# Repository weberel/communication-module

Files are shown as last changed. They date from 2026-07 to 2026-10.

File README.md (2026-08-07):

# ecoTrace Communication Module

> ## 🚧 HARDWARE VALIDATED, APPLICATION NOT YET - read this
> As of the **2026-08-06/07** bring-up campaign the **board is fully validated on
> real hardware**: both charge inputs (USB and solar, incl. VINDPM/MPPT control),
> cellular, WiFi, all I2C sensors, the SPI flash, deep sleep, and the QON button
> (wake / OTA mode / ship-mode power-off). GPS is the only untested block.
> The `lib/EcoTrace` drivers underneath all of that ran on hardware too.
>
> What has **NOT been exercised end-to-end** is the **`datalogger` application
> itself**: the 5-minute duty cycle, the flash ring log across power loss, MPPT
> tracking over a real day, the twice-daily ThingsBoard upload with clock sync,
> and watchdog/crash recovery. It compiles and boots; treat it as a scaffold to
> validate, not as proven.
>
> Full breakdown, including the measured numbers: [`docs/testing-status.md`](docs/testing-status.md).

Firmware and board-support for the **ecoTrace Communication Module** - a small,
battery- and solar-powered ESP32-C6 board with an LTE modem, built for **logging
data remotely** from the field.

This repo gives you a ready-to-run **datalogger** plus a library of drop-in
**functions for every peripheral** on the board, so you can fork the logger and add
whatever you need. It is the starting point for anyone (students, collaborators)
picking up the board.

> ⚠️ **Read [`docs/hardware-errata.md`](docs/hardware-errata.md) before wiring anything.**
> Rev A has a **swapped VIN +/- silkscreen** and other gotchas.

---

## The board at a glance

| | |
|---|---|
| MCU | ESP32-C6-MINI-1 (WiFi / BLE / 802.15.4, native USB Serial/JTAG) |
| Power / charging | **BQ25792** buck-boost charger + PMIC - USB, solar (MPPT), LiPo, 16-bit ADC |
| Cellular | **SIMCom A7672E-LASE** LTE Cat-1 modem (+ internal GNSS, untested) |
| Sensors (optional) | SC7A20 accelerometer, LTR-303ALS ambient light |
| Storage | GD25Q128 16 MB SPI NOR flash |
| Security | ATECC608B secure element |
| Inputs | USB-C (power + flashing), SIM slot, battery connector, VIN (solar/DC in) |
| Antennas | u.FL for LTE and GPS |

Board revision: **Rev A, 2026-04-23**. Full KiCad project, schematic PDF, board
renders, and JLCPCB fab files are in [`hardware/`](hardware/).

## What you get

**1. The datalogger** (`src/datalogger/`) - the main application. Every 5-minute
wake it:
- reads the full battery + charger state (BQ25792) and the I2C sensors
  (LTR-303 light, SC7A20 accel, MS5837 pressure + temperature on the hat header),
- runs a solar-management pass: **MPPT** (fractional-Voc + perturb-&-observe on
  VINDPM) to maximise input power, per-day **harvest accounting**, and a
  **weather-adaptive charge target** - good weather caps charging at ~80 % SoC to
  age the LiPo slower, bad weather allows 100 % for reserve,
- appends one 64-byte record to a **ring log on the 16 MB SPI flash**
  (power-loss safe, ~2.5 years of capacity),
- twice a day drains the backlog to **ThingsBoard** in timestamped batches -
  cellular first, **WiFi as backup** - and syncs the wall clock from the network,
- deep-sleeps in between with everything powered down (modem rail, flash,
  sensors, charger ADC); the BQ25792 keeps charging autonomously.

It is a **hackable starting point** - fork it and change whatever you need. To log
your own sensor: extend `LogRecord` in [`record.h`](src/datalogger/record.h) (spare
bytes are reserved), read it in `readSample()` in
[`main.cpp`](src/datalogger/main.cpp), and send it in `recordValues()` in
[`uplink.cpp`](src/datalogger/uplink.cpp). Connect external sensors on the SENSOR
(I2C) or SPI header. Tune the duty cycle / charge profile / MPPT / weather
thresholds in [`config.h`](src/datalogger/config.h).

**2. The driver library** (`lib/EcoTrace/`) - ready-to-call functions for every part
on the board. Pull in only what you need. Full list: [`docs/api-reference.md`](docs/api-reference.md).

| Driver | Covers | Status |
|---|---|---|
| `BQ25792` | charging (USB + solar), ADC, status, faults, MPPT/VINDPM | ✅ full, datasheet-accurate |
| `ModemA7672` | LTE power/AT, SIM, registration, GPRS, HTTP GET/POST, time | ✅ full (GPS = stub) |
| `LTR303` | ambient light (CH0/CH1, lux) - datalogger's example sensor | ✅ |
| `SC7A20` | accelerometer (X/Y/Z mg) | ✅ |
| `ExtFlash` | GD25Q128 read/erase/program, power-down | ✅ (full 16 MB) |
| `MS5837` | MS5837-02BA barometer (pressure, temperature, altitude) | ✅ |
| `ATECC608B` | secure element presence/wake | 🔹 thin (crypto via CryptoAuthLib) |
| `EcoTraceBoard` | safe init, I2C/SPI bring-up, deep sleep | ✅ |

**3. The board self-test** (`src/functionality_test/`) - probes every device and
prints a `PASS / FAIL / SKIP` report. Run it first on a new board.

## Toolchain

**VS Code + PlatformIO + Arduino-ESP32.** Reproducible builds, a real editor, the
Arduino library ecosystem, and full ESP-IDF APIs underneath when needed. See
[`docs/getting-started.md`](docs/getting-started.md).

The ESP32-C6 needs arduino-esp32 v3+, which the official PlatformIO platform does not
ship yet - this project pins the [pioarduino](https://github.com/pioarduino/platform-espressif32)
fork (version `53.03.13`) in `platformio.ini`. Don't unpin it.

## Quick start

```bash
# 1. open this folder in VS Code with the PlatformIO extension installed
# 2. plug the board in over USB-C (keep a battery connected -- see errata)
# 3. check the board is healthy:
pio run -e functionality_test -t upload && pio device monitor

# 4. set your SIM APN + upload URL, then run the logger:
cp lib/EcoTrace/secrets.example.h lib/EcoTrace/secrets.h   # then edit it
pio run -e datalogger -t upload && pio device monitor

# 5. reflash over WiFi later (bench convenience): press the QON button 3x
#    (board joins WiFi, blinks once per second, prints its IP on serial), then:
pio run -e datalogger        # build the new image
curl -F "image=@.pio/build/datalogger/firmware.bin" http://<board-ip>/update
#    (espota / `pio run -e datalogger_ota -t upload` also exists but its UDP
#     handshake proved unreliable on real networks -- prefer the curl path)
```

Without a `POST_URL` in `secrets.h` the datalogger runs in bench mode: it samples and
prints over serial but does not transmit.

## Layout

```
lib/EcoTrace/      board support: pin map + drivers (the reusable core)
  ecotrace_pins.h    single source of truth for the pin map
  EcoTraceBoard.*    safe init, I2C/SPI bring-up, deep-sleep helper
  BQ25792.*          charger / PMIC (hand-written, datasheet-accurate)
  ModemA7672.*       LTE modem (hand-written AT stack)
  LTR303.* SC7A20.* ATECC608B.* ExtFlash.*   peripheral drivers
  secrets.example.h  copy to secrets.h and fill in (gitignored)
src/
  datalogger/        the main application
    config.h           duty cycle, charge profile, MPPT, weather, upload tunables
    record.h           the 64-byte on-flash log record (+ CRC)
    flash_log.*        power-loss-safe ring log on the 16 MB SPI flash
    solar.*            MPPT + harvest tracking + weather-adaptive charge target
    uplink.*           ThingsBoard upload: cellular first, WiFi backup, clock sync
    main.cpp           the wake/sample/sleep cycle
  functionality_test/  board bring-up self-test
docs/              getting started, pinout, errata, api reference, testing status
hardware/          KiCad project + exports
```

## Related

- `functionality_test_arduino` - the original bring-up test this repo grew from.
- `bms_stove` - an ESP-IDF application on this hardware (remote battery/stove
  datalogger), a reference for a full deployment.

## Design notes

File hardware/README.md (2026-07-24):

# Hardware

The KiCad design and manufacturing outputs for the ecoTrace Communication Module
(Rev A, 2026-04-23) are included here so you don't need Drive access.

```
hardware/
  kicad/         KiCad project - open Communication_pcb_main.kicad_pro in KiCad
    Communication_pcb_main.kicad_pro / .kicad_pcb / .kicad_sch
    mcu.kicad_sch  power_mgmt.kicad_sch  simcom.kicad_sch   (schematic sheets)
    jlcpcb/        fab outputs: gerbers, drill, BOM, CPL, GERBER-*.zip
  exports/       viewable without KiCad:
    Communication_pcb_main-schematic.pdf
    board-top.png  board-bottom.png   (3D renders)
```

## No KiCad? Start here

- **Schematic:** `exports/Communication_pcb_main-schematic.pdf`. Sheets: `mcu`,
  `power_mgmt`, `simcom`. The **power_mgmt** sheet (BQ25792) is the one to know: it
  defines the charging path, VSYS, the NTC (TS) network (note the errata), and the
  ACDRV FET gating for USB vs solar inputs.
- **Board:** `exports/board-top.png` / `board-bottom.png`.

## Fabrication

`kicad/jlcpcb/` holds a ready-to-order set (gerbers, drill, BOM, CPL, and a zipped
gerber bundle) targeted at JLCPCB. Re-export from KiCad if you change the board.

This is the **current 4-layer** version of the board (F.Cu / In1 / In2 / B.Cu). An
older 2-layer design also exists on the shared drive; it is not included here.

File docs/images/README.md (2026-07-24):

# Board images

- `board_top.png` - top side (3D render from KiCad)
- `board_bottom.png` - bottom side (shows the BOOT / UART0 / test pads)

Higher-level renders and the schematic PDF are in [`../../hardware/exports/`](../../hardware/exports/).

TODO: add `board_annotated.png` - the top view with connector/pin callouts (the
hand-annotated render used during bring-up) if you want it embedded in the pinout doc.

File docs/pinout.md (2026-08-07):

# Pinout - ecoTrace Communication Module (ESP32-C6-MINI-1)

Verified against schematic 2026-05-05. The authoritative machine-readable copy is
[`lib/EcoTrace/ecotrace_pins.h`](../lib/EcoTrace/ecotrace_pins.h) - this page is the
human-friendly version.

Exposed GPIOs on the MINI-1 module: `0,1,2,3,4,5,6,7,8,9,12,13,14,15,18,19,20,21,22,23`
(GPIO10,11,16,17 are not bonded on the MINI-1; GPIO24-30 are internal flash).

## By function

| GPIO | Net | Notes |
|-----:|-----|---|
| 0 | MODEM_STATUS | A7672 STATUS out, but **only valid while the modem rail is on**: the translator (Q408) is gated by the modem's own 1V8, so with the rail off the line floats HIGH via R423 - indistinguishable from "modem running". Detect boot as the LOW→HIGH edge (or an AT response), never as a HIGH level. **Also a boot strap** - read briefly only |
| 1 | LED | status LED, active HIGH |
| 2 | QON | shared button net: BQ25792 QON + ESP deep-sleep wake (EXT1). BQ hardware behavior: LOW ~1 s exits ship mode, LOW ~10 s = full power cycle (tRST); shorter holds are ignored by the BQ, so firmware defines the long-press action (datalogger: 3 s hold = enter ship mode via I²C). Pad TP404 |
| 3 | INT_shared | shared interrupt: SC7A20 accel + LTR-303 light |
| 4 | SPI_MOSI (SI) | to GD25Q128 flash |
| 5 | SPI_MISO (SO) | from GD25Q128 flash |
| 6 | I2C_SDA | LP_I2C, external 4k7 pull-up to 3V3 |
| 7 | I2C_SCL | LP_I2C, external 4k7 pull-up to 3V3 |
| 8 | SPI_CS_FLASH | GD25Q128 CS. Strapping pin, idles HIGH via 10k |
| 9 | SPI_CS_PERIPH | spare CS, **not populated**. Strapping + **BOOT pad** (TP403) |
| 12 | USB D− | native USB Serial/JTAG |
| 13 | USB D+ | native USB Serial/JTAG |
| 14 | SENSOR_PWR | populated high-side switch (active HIGH) for EXTERNAL sensor power on the SENSOR header. On-board sensors run on the always-on 3V3 (RT9080 LDO), not this switch |
| 15 | (tied to GND) | strapping pin |
| 18 | SPI_CLK | to GD25Q128 flash |
| 19 | INT_bq | BQ25792 fault / charge interrupt |
| 20 | MODEM_TX | ESP TX → modem RX |
| 21 | MODEM_RX | ESP RX ← modem TX |
| 22 | MODEM_PWRKEY | drives a **low-side inverter** (Q409): GPIO HIGH = PWRKEY asserted (pulled LOW at the modem), GPIO LOW = released. The firmware's idle-HIGH convention holds PWRKEY asserted, so the modem auto-boots as the rail rises - field-proven, but be aware of the inversion when porting |
| 23 | MODEM_PWR_EN | modem rail MOSFET; HIGH = modem powered |

## I2C device addresses (7-bit)

| Addr | Device |
|---|---|
| 0x18 / 0x19 | SC7A20 accelerometer |
| 0x29 | LTR-303ALS ambient light |
| 0x35 / 0x60 | ATECC608B secure element (needs a wake pulse to answer) |
| 0x6B | BQ25792 charger / PMIC |

## Header labels (silkscreen)

Top-edge and side headers, per the board silkscreen:

- **SENSOR / I2C** (J401, the "hat" header): `GND · 3V3 · SCL · SDA` - the 3V3 pin is
  the **always-on** LDO rail, *not* the GPIO14-switched one, so devices here stay
  powered in deep sleep (put them in their own low-power mode instead). The separate
  J404 connector is the one switched by GPIO14.
- **SPI**: `GND · 3V3 · SCLK · SI · SO · CS`
- **BTN**: `GND · QON`
- **USB**: `GND · VUSB · DN · DP`
- **Programming pads** (back): `GND · 3V3 · RESET · BOOT · RX · TX`
- **Power**: `VIN (+/−, SWAPPED - see errata)`, `VBAT · TS · GND`, `VSYS`

## Debug / fixture pads (back side)

| Pad | Signal |
|-----|---|
| TP401 | TXD0 - UART0 flash TX |
| TP402 | RXD0 - UART0 flash RX |
| TP403 | GPIO9 - CS_periph / **BOOT** fallback |
| TP404 | GPIO2 - QON / wake |
| EN | reset (10k to 3V3, 1µF to GND, button to GND) |

## Board landmarks

Renders: [`images/board_top.png`](images/board_top.png),
[`images/board_bottom.png`](images/board_bottom.png). Schematic PDF:
[`../hardware/exports/`](../hardware/exports/).

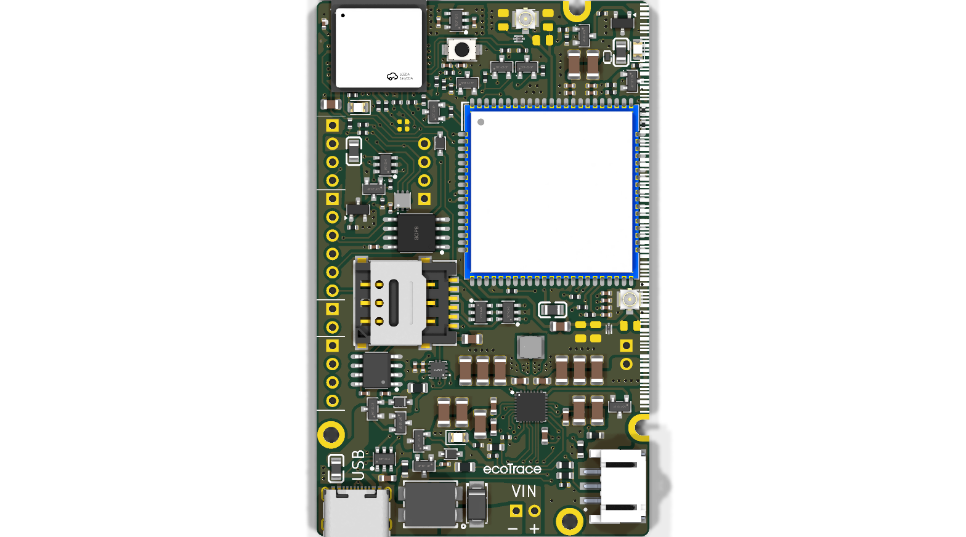
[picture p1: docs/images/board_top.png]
top render


Landmarks (using the photo orientation, USB at top-left): USB-C (power + ESP
flashing), USB pins, on/off button, SIM card slot, SPI pins, I2C/VSYS pins along the
top; ESP32-C6-MINI-1 module centre; A7672E LTE modem top-right; ESP reset button and
LTE (mobile) u.FL antenna on the right; GPS u.FL antenna, VSYS-out pads, battery
connector (bottom-left), and solar/general power in (VIN) on the left edge.

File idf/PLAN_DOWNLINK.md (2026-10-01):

# Plan: downlink (remote config and OTA) for the comm board

Written 2026-09-30, before the code. **The contract both sides build against is
`ecotrace-server/docs/DOWNLINK.md`** (agreed the same day, with the three corrections below
taken in). This file is the firmware half: stages, files, done-criteria. Where the two differ,
DOWNLINK.md wins.

## Contract

**Topic.** `ecotrace/<username>/config`, retained, QoS 1, published by the server only. The
device gets `pattern read ecotrace/%u/config` in the broker ACL and nothing else new. It is not
the telemetry topic: a retained message there would be ingested as a reading, and the device
must never be able to write its own config.

**Payload.** One JSON object. Unknown keys are ignored, so the contract can grow.

```json
{"cfg_ver": 7,
 "sample_interval_s": 300, "upload_period_s": 43200,
 "fw_ver": "com-0.36", "fw_url": "https://ingest.ecotrace.ch/fw/com-0.36.bin",
 "fw_sha256": "<64 hex>"}
```

- `cfg_ver` is an identity, not an order: the device applies a payload whose version differs
  from the one in NVS. A server that resets the counter still gets applied.
- Interval bounds on the device: sample 60..3600 s, upload 600..86400 s, upload >= sample.
  A payload that fails them is not applied at all and is reported with `cfg_err: "range"`.
- The `fw_*` keys are optional. Present means "run this version"; absent means keep what runs.
- An empty retained payload (the server's "clear") means no config: the device keeps its NVS
  values and reports them. Not an error.

**Ack, in the status message.** `cfg_ver` (in effect, 0 if never configured), `sample_s`,
`upload_s` (in force for the sleep that follows), `cfg_err` (only while the last received
payload was rejected: `parse`, `range`), and after a failed OTA `fw_err` (`download`, `sha256`,
`write`, `rollback`) with `fw_err_ver`. `fw` is already sent on every status message and is the
OTA ack.

The ack is truthful within one session: the payload arrives at subscribe time, before the
drain; the sleep length and the upload countdown are computed after the drain, so the status
message of the same session reports what will actually happen next.

## Stage 1: config (one build, com-0.35) -- DONE, verified on unit A (dev-4) 2026-09-30

Files: `main.c`, `uplink.c`, new `devcfg.c/h`, `config.h`, `CMakeLists.txt` (adds `json`).

- [x] `devcfg.c`: NVS namespace `cfg`, keys `ver`, `samp_s`, `upl_s` (u32). `devcfg_init()`
      at every boot in `app_main`, right after the rollback mark and before `board_init()`; it
      owns `nvs_flash_init()` now (it used to run only on the WiFi path). Values cached in
      `RTC_DATA_ATTR` with a magic: a warm wake never opens NVS, a cold boot reloads.
- [x] `SAMPLE_INTERVAL_S` / `UPLOAD_PERIOD_S` are compiled defaults only (`config.h`); the five
      use sites read `devcfg_sample_s()` / `devcfg_upload_s()`.
- [x] `uplink.c`: `config_fetch()` after `mqtt_up()` in both the cellular and the WiFi session,
      before `drain()`. Subscribes QoS 1 to `ecotrace/<user>/config`, waits up to 2 s for
      `EV_CFG_DONE`, unsubscribes. A refused SUBSCRIBE (`MQTT_ERROR_TYPE_SUBSCRIBE_FAILED`,
      the ACL not deployed yet) and a timeout are both "no config". The payload is applied
      from the MQTT event task (`devcfg_apply`, cJSON, bounded parse).
- [x] Apply rule as in DOWNLINK.md: `cfg_ver` differs from NVS, absent interval = keep, bounds
      sample 60..3600, upload 600..86400, upload >= sample checked on the resulting pair; any
      violation rejects the whole payload. NVS written and committed before the cache moves.
- [x] Status keys: `cfg_ver`, `sample_s`, `upload_s` on every status message, `cfg_err`
      (`parse` | `range`) only while the last received payload was rejected.
- [x] No countdown clamp needed: the countdown is (re)armed from `devcfg_upload_s()` after
      the session, so a new period is in force from the same session.

Verified 2026-09-30 from the server UI, board untouched: a config published from the server shows up in the next
status message with the same `cfg_ver`; the following wakes are spaced by the new interval
(USB console timestamps); a rejected payload shows `cfg_err` and unchanged intervals; a board
that never received a config reports `cfg_ver` 0 and the compiled 300 / 43200; a session
before the ACL is deployed logs "config subscribe refused" and drains normally.

## Stage 2: OTA (com-0.36) -- DONE. Forward and reverse OTA proven 2026-09-30; rollback proven 2026-10-01 with com-0.40

Files: `ota.c/h` (new), `devcfg.c/h`, `uplink.c/h`, `main.c`, `config.h`, `src/CMakeLists.txt`,
`version.txt` (new).

- [x] **One version source.** `idf/version.txt` holds `com-0.36`; ESP-IDF puts it in the image's
      app descriptor (the server reads it there at release upload) and `src/CMakeLists.txt`
      passes the same string as `FW_VERSION`. `config.h` errors if it is missing. Bump
      `version.txt` **and touch `idf/CMakeLists.txt`** (PlatformIO re-runs CMake only when a
      CMakeLists changes; a bump alone rebuilt com-0.36 on 2026-09-30). Checked on the built
      image: descriptor and status string agree. Release copies go to `.pio/build/release/`.
- [x] `devcfg.c` takes `fw_ver` / `fw_url` / `fw_sha256` from every accepted payload (also on
      `same`), all three or none; keeps them for the session. Attempt counter per version and
      the last error (`fw_err`, `fw_err_ver`) in NVS, so they outlive a rollback.
- [x] `ota.c`: `esp_https_ota` begin/perform/finish over the link already up, pinned ISRG root,
      into `esp_ota_get_next_update_partition()`. SHA-256 of the written bytes (mbedtls, 4 KB
      static buffer, WDT reset per chunk) against `fw_sha256` BEFORE `esp_https_ota_finish()`
      switches the boot partition. Errors map to the contract: `download`, `sha256`, `write`.
- [x] `uplink.c` `ota_attempt()`: after the drain, before the status message, in both the
      cellular and the WiFi session. Skipped when the target equals the running version, when
      VBAT < modem floor + 100 mV, or after 3 attempts for that version. The attempt is counted
      before the download starts, so a crash mid-download counts.
- [x] `main.c`: the mark-valid call moved from the top of `app_main` to after the upload
      session, only when it published. `ota_boot_check()` after the boot classification: an
      ABORTED other slot records `fw_err: rollback` with that slot's descriptor version and
      forces an upload now. On `ota_ready`: RTC magic cleared, devcfg cache dropped, restart.
- [x] Status keys `fw_err`, `fw_err_ver` when set; `fw` unchanged (it is the ack).
- [x] Builds clean: RAM 19.5 %, flash 64.8 %.
- [x] **Found on the first attempt, fixed the same day:** the download wedged after
      `uart_terminal: HW FIFO Overflow`. The UART ISR was in flash, so it is masked during every
      OTA flash write and modem bytes are lost, which killed the PPP stream; and
      `esp_https_ota_perform()` returns IN_PROGRESS on a read timeout, so the loop spun for 10+
      minutes feeding the watchdog with the modem on. Fixes: `CONFIG_UART_ISR_IN_IRAM=y`
      (sdkconfig.defaults and the generated sdkconfig), a 60 s no-progress stall and a 9 min
      deadline in `ota_run()` (`fw_err: download`), and the attempt counter restarts when the
      running version changes (a serial reflash gets fresh tries).
- [x] Forward OTA verified 2026-09-30 17:06: dev-4 on the fixed com-0.36 downloaded com-0.37
      over cellular, restarted, reported `fw: com-0.37`, cfg_ver 4 applied, server "up to date".
      (That com-0.37 was the build WITHOUT the UART fix; it must not be asked to OTA again.)

- [x] With the fixed code on both ends, 2026-09-30 17:19 and 17:26: com-0.36 -> com-0.37 -> com-0.36
      over cellular, each under 4 min from button press to "up to date" on the server. The status
      message of the downloading session goes out with the old `fw` and no `fw_err`, then the
      new image's cold-boot session acknowledges.

- [x] com-0.38 (2026-10-01): a version with `fw_err: rollback` on record is never retried (the
      retry ran before the status message and would have cleared the error the server needs to
      see; the same bytes would fail the same way). Also fixes the RSSI 0 dBm regression (CSQ
      re-read after registration). com-0.39 = same code with a wrong broker host, built only for
      the rollback test. Procedure: server `CHANGES_FIRMWARE_com-0.38.md`.

- [x] **com-0.40 (2026-10-01): rollback actually works now.** The com-0.39 rollback test failed:
      the broken image survived every wake and the button. Cause: the mark-valid call sat after
      the upload session in `main.c`, and the OTA runs inside that session;
      `esp_ota_mark_app_valid_cancel_rollback()` marks the ACTIVE otadata entry, which
      `esp_https_ota_finish()` had just pointed at the new slot. So every OTA so far validated the
      new image before it booted. Fix: `confirm_running_image()` in `uplink.c`, right after the
      drain published and before `ota_attempt()`, guarded by "running slot is PENDING_VERIFY";
      the `main.c` call is gone. com-0.41 = com-0.40 with the wrong broker host, for the retest.

- [x] **Rollback verified 2026-10-01 09:50** (device_status row, UTC 07:50:02): com-0.40 downloaded
      com-0.39 (09:44 status, `fw: com-0.40`, no error), restarted into it, com-0.39 failed its
      cold-boot session and slept; at its first timer wake the bootloader booted com-0.40, which
      reported `fw_err: rollback`, `fw_err_ver: com-0.39`, `wake_reason: timer`, `rssi_dbm: -71`
      (RSSI fix confirmed too). 5.5 min from restart to report. Server-side gap: `ecotrace-admin
      config` still prints `[pending]` for the target instead of failed; the data is there.

Still open on hardware:  a wrong SHA-256 is
refused with `fw_err: sha256` and the running image is untouched.

## Server side: three corrections to the 2026-09-30 plan (all taken into DOWNLINK.md)

1. Separate topic and a read ACL entry, see Contract. "The existing topic" does not work.
2. Put the `fw_*` keys and the error keys into the contract now, so the handoff is written
   once. The server leaves them unset until it hosts images.
3. Host firmware images over HTTPS behind the existing certificate chain (Caddy, same host as
   ingest), with the SHA-256 computed at upload time and stored with the version.

Per device only, no group inheritance. Agreed. Deltas the server side added: `fw_err` values
are `download | sha256 | write | rollback` with `fw_err_ver`; the OTA attempt counter stops at 3;
`cmd` stays reserved for one-shot commands.

## Traps
- `nvs_flash_init()` currently runs only when WiFi is used (`uplink.c` 1078). It must run at boot.
- ESP-IDF rollback is checked in the bootloader on every reset, including deep-sleep wake.
- MQTT 5 stays: a refused subscribe is visible as a reason code, a 3.1.1 broker would hide it.
- `boot_id` rolls on the post-OTA cold boot by design; the server's gap check treats the two
  boots separately.

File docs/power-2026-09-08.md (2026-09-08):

# Comm module sleep current: 1467 uA -> 356 uA (2026-09-08)

All currents measured with a Joulescope JS220 in the **battery lead**, USB
unplugged, board on battery. "Comm board alone" means nothing on J404.

USB-plugged is easy to mistake for a valid reading: with the cable in, the board
runs from VBUS and the battery lead shows a flat **62.9 uA**. That number, not
the presence of a COM port, is the test for whether the cable is out -- the C6's
USB-Serial/JTAG only enumerates while awake, so a sleeping board shows no port
either way.

## 1. Result

| configuration | sleep current |
|---|---|
| shipping firmware, start of day | **1467.5 uA** (also 1468, 1501 on two earlier runs) |
| after the pull-up fix, sensor rail up | **356.5 uA** |
| same, sensor rail down | **139.8 uA** |
| no GPIO holds at all | **128.3 - 128.5 uA** |

The 128.3 uA floor matches the 129.1 uA in the 2026-09-06 report's June bench
staircase to within 0.8 uA. The hardware was never the problem.

Full system (comm + ultrasonic + pressure sensor, rail up, USS metering at 1 Hz):
**floor 546.1 uA, median 649.1 uA**; the ripple is the 1 Hz captures.

## 2. What was actually wrong

### 2.1 Internal pull-ups latched into their own output drivers (1122 uA)

`gpio_reset_pin()` enables the pad's internal pull-up -- its own comment says
"for powersave reasons, the GPIO should not be floating, select pullup" -- and
`gpio_set_direction()` only touches input-enable / output-enable / open-drain.
It never clears the pull-up. So board.c's `out()` leaves every pin driving a
level WITH the pull-up still on.

A pad driven LOW then fights its own driver through the ~42k internal pull-up.
That pull-up is in the always-on domain, so an UNHELD pad powers down in deep
sleep and the conflict disappears; `gpio_hold_en()` latches it in.

MEASURED, holding pads driven LOW:

| pads held | delta |
|---|---|
| LED only | +78.4 uA |
| MODEM_PWR_EN + PWRKEY | +156.1 uA (78.1 uA each) |

A pad held HIGH costs nothing: GPIO1 high vs low measured **+12.4 uA**, which is
that pin's own load -- (3.3 - 1.9) V / R454 100k = 14 uA through D420.

FIX: `gpio_pullup_dis()` on the three pads held low, before `gpio_hold_en()`.
Three lines. Shipping firmware went **1467.5 -> 356.5 uA** with no behavioural
change: all four holds still applied, sensor rail still up, ultrasonic board
still powered between wakes.

### 2.2 The energised sensor rail (216.6 uA) -- already fixed in the schematic

Energising the switched rail costs **216.6 uA**, measured twice, under two
different pull-up configurations, with J404 empty.

It is NOT a load on the rail. It is the gate-drive divider, and the board on the
bench does not match the current schematic:

| | R419 | R420 | R421 |
|---|---|---|---|
| as built (BOM sent to JLC 2026-04-23) | 10k | 10k | 100k |
| schematic since 2026-08-18 | 1k | 1M | 1M |

With the as-built values:

    GPIO14 high -> R419 10k -> gate -> R420 10k -> GND   3.3 V / 20k   = 165 uA
    Q405 on     -> R421 100k, VSYS to drain              4.16 V / 100k =  42 uA
                                                                         -------
                                                             predicted   207 uA
                                                             measured    216.6 uA

The corrected values give 7.5 uA for the same paths, so the next build removes
~209 uA with no new work. D606 was suspected and is exonerated.

Supporting readings: with the rail ON, J404 pin 2 = 4.16 V (so nothing loads it)
and SDA/SCL = 3.3 V (so no clamp path); rail-to-GND cold = 2.9 MOhm.

### 2.3 Park mode leaked 321 uA

The two park-mode sleep paths called `bq_adc_disable()` but never
`bq_ibat_sense(false)`, leaving EN_IBAT on for exactly the long low-battery
sleeps. Fixed.

BQ25792 costs, one control bit removed per ladder rung:

| left enabled across sleep | cost |
|---|---|
| ADC in continuous conversion | **574.1 uA** |
| EN_IBAT | **321.4 uA** |
| ACDRV1, ACDRV2 | 0.0 uA each |

574.1 + 321.4 = 895.5 uA, matching an independent single-rung measurement of
895.5 uA exactly. Note the normal wake path already disabled both before sleep,
so this was never the field problem -- only park mode leaked.

## 3. Suspected and cleared

* Motion wake / `sc7a20_arm_motion()` -- disabled it, board still slept at
  1467.5 uA vs 1467.1 uA. Costs nothing. Left enabled.
* The modem and WiFi uplink -- a rung covering the entire wake path including a
  full uplink measured the same as one that skipped it.
* R405/R408 2.2k UART pull-ups -- parking IO20/IO21 before sleep changed nothing.
  The Q402/Q403 level shifters have their gates on the modem's own VDD_1V8, so
  they isolate correctly when it is unpowered.
* `esp_pm_configure()` with light sleep enabled -- +0.1 uA.
* D606 / errata 11 -- with the ultrasonic board attached and the rail down, the
  back-feed measures **+60.4 uA**, not 1.4 mA. The 1.4 mA figure belongs to
  `board_sensor_power_cycle()`, which deliberately drives SDA/SCL LOW through the
  4k7 pull-ups (2 x 3.3 V / 4k7 = 1.404 mA) for the off window only. Confirmed
  with a voltmeter: rail off, J404 pin 2 sits at 2.8 V, fed through D606's clamps
  from the 3.3 V bus. A connected ultrasonic board is therefore parasitically
  held near 2.8 V during sleep rather than being cleanly off.

## 4. Two ESP32-C6 facts worth keeping

* `gpio_deep_sleep_hold_en()` does not exist on the C6. driver/gpio.h guards it
  with `#if SOC_GPIO_SUPPORT_HOLD_IO_IN_DSLP && !SOC_GPIO_SUPPORT_HOLD_SINGLE_IO_IN_DSLP`
  and the C6 defines BOTH -- it holds pads individually, so plain
  `gpio_hold_en()` is sufficient, including on non-RTC pads like GPIO14/22/23.
  Being an RTC/LP pin (GPIO0..7) governs EXT1 wake and LP-core access, not hold.
  RTC pads are not cheaper to hold.
* `esp_sleep_pd_config(ESP_PD_DOMAIN_RTC_PERIPH, ESP_PD_OPTION_OFF)` RAISES
  deep-sleep current to 885.7 uA -- the documented light-sleep level -- and wipes
  RTC_DATA_ATTR. Do not use it.

## 5. Energy budget

Measured, comm + ultrasonic + pressure sensor, USS metering at 1 Hz:

    sleep    655 uA x 24 h                  = 15.7 mAh/day
    wakes    67.1 mC above floor x 288/day  =  5.4 mAh/day
    uplink   2.28 mAh x 1/day               =  2.3 mAh/day
                                              -------------
                                              ~23 mAh/day

against the 114 mAh/day field baseline in the 2026-09-06 report. On a 5000 mAh
cell that is ~217 days nominal; derating for usable capacity, self-discharge and
a real registered cellular session gives roughly 5 months, against ~6 weeks
before. The next board build should reach ~18 mAh/day.

## 6. NOT established

* The uplink figure is one attach ATTEMPT, not a registered session. There is no
  cellular signal at the bench, so the modem drew 351 mA for ~40 s (8.21 C =
  2.28 mAh) and failed to register. A real session may cost more; the 2026-09-06
  report modelled ~5.5 mAh/day.
* The per-wake charge comes from a SINGLE wake in one 420 s window.
* The rung-0 baseline drifted 128.5 -> 174.4 -> 139.6 uA across runs of identical
  code. Deltas within a run are consistent to ~1 uA; absolute floors across runs
  carry roughly 11-35 uA of unexplained spread.
* That the 216.6 uA is the gate divider is supported by arithmetic (207 uA
  predicted vs 216.6 uA measured) and by the BOM/schematic mismatch, but has NOT
  been confirmed by measuring the fitted resistors.

## 7. Method notes

* Peripheral state survives an ESP32 reset. The BQ25792 keeps its registers (and
  `bq_disable_watchdog()` removes the one timer that would restore defaults), and
  so does the SC7A20. A minimal "boot and sleep" image therefore proves nothing
  about persistent peripheral state -- only a ladder that TAKES STATE AWAY does.
* Encode the rung in the sleep duration (20 s + 5 s per rung). Two earlier
  ladders were mapped by plateau ORDER, and the same trace admitted two
  self-consistent mappings that gave opposite conclusions.
* Give every rung a >= 1.5 s awake window, or the USB port never enumerates and
  the board cannot be reflashed without a full power cycle.
* Always include a rung that MUST reproduce a known reference. The ladder that
  finally worked had one rung land on 128.5 uA (the known floor) and another on
  1467.1 uA (the known shipping figure). Earlier ladders had no such check and
  produced confident wrong answers.
* Audit the netlist that matches the BOARD, not the latest schematic. An hour was
  spent blaming D606 because the netlist export came from a schematic revised
  four months after the board was manufactured.

## 8. Soak configuration (flashed 2026-09-08)

| setting | value |
|---|---|
| SAMPLE_INTERVAL_S | 300 s |
| UPLOAD_PERIOD_S | 24 h (one uplink/day) |
| USS_AUTO_PERIOD_S | 1 s (ultrasonic meters at 1 Hz) |
| MOTION_WAKE_ENABLE | 1 |

Firmware contains the pull-up-before-hold fix and the park-mode EN_IBAT fix; all
ladder instrumentation removed (main.c 1271 -> 791 lines).

Predicted ~23 mAh/day. The soak is sited where there IS cellular signal, so the
daily uplink should be a real registered session rather than the failed attach
measured at the bench -- which makes the soak the measurement that finally closes
the one term in section 6 that is still an estimate.

What to check when it comes back:

* battery discharge slope vs the predicted 23 mAh/day
* actual mAh per registered cellular session
* whether the sleep floor drifts with battery voltage (it should not, now that
  the 216.6 uA is understood as a fixed resistive divider rather than a leakage)
* USS capture quality over a week (badcode / badsnr in the telemetry)

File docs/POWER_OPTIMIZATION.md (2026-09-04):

# Power optimisation — work plan (bench session, week of 2026-09-08)

Everything below came out of the 2026-09-02 telemetry export
(`tools/tb_export_PCB-test-rig_20260902_1831.csv`, 137,939 datapoints,
2026-08-11 → 09-02). Nothing here needs a hardware change: every item is
firmware, on one side or the other.

Companion write-up on the module side: `Ultrasonic/Firmware/docs/DEVLOG.md` §13.

---

## 0. Before you start: the board's state

The unit has been indoors on battery since 08-17 with **no charging at all**
(deliberate max-lifespan test). At 09-02 it was at 3789 mV falling ~22.5 mV/day:

| threshold | what happens | ETA from 09-02 |
|---|---|---|
| 3600 mV | cellular stops, WiFi only | ~09-10 |
| 3450 mV | **all telemetry stops** — records bank in flash only | ~09-15 |
| 3350 mV | sampling drops to 30 min | ~09-19 |
| 3300 mV | park mode, 60-min wakes | ~09-20 |

So by the bench session it may already be silent on the dashboard. That is not
a fault. **Plug USB in first** — charging resumes, and the flash backlog drains
on the next session (ring holds 131k records, cursor is journalled, nothing is
lost). Grab that data before reflashing anything: a record-layout bump would
discard it.

---

## 1. What the run measured

Whole node: **114 mAh/day (~4.8 mA)** on the 5000 mAh cell — ~45 days
full-to-empty. Split (from ratios of voltage slopes, so independent of the
capacity calibration):

| load | share | cause |
|---|---|---|
| ultrasonic board | ~45% (~2.1 mA) | OPA836 idle ~1 mA **+** MSP430 never sleeping ~1 mA |
| ESP32 wakes | ~28% | 288 wakes/day |
| cellular | ~25% | measured: +3.08 mV per session, 2 sessions/day |
| ESP32 deep sleep | ~2% | — |

Reliability over the same window was excellent and is not a concern: 5812
records, ~286/day against 288 nominal, **zero crashes**, `uss_code` 122 on
100% of 5090 measurements, `snr_db` pinned at 34.0 dB for 18 days.

---

## 2. Work items

### A. Ultrasonic module firmware (G: drive repo)

- [ ] **A1. Sleep the main loop (biggest single item, ~1 mA).**
      `EcoTrace_Run()`'s `for(;;)` busy-polls forever — the MSP430 never leaves
      active mode (~120 µA/MHz from FRAM ≈ 1 mA at 8 MHz). Add
      `__bis_SR_register(LPM3_bits | GIE)` at the bottom of the loop for the
      `ECOTRACE_I2C_SLAVE` build.
      * the I²C ISR **already** exits LPM3 (`__bic_SR_register_on_exit`), and
        `uss_link.h` already documents this as the design — it was simply never
        implemented;
      * needs a timer wake for the autonomous tick (ACLK Timer_A or RTC);
      * `now_ms()` timebase must run off ACLK, not SMCLK, to survive LPM3;
      * watchdog interval must exceed the sleep period (or source it from
        ACLK) — `FEED_WDT()` stops happening while asleep;
      * keep the bench build busy-polling so UART stays responsive; the
        `ECOTRACE_I2C_SLAVE` split already exists for exactly this.

- [ ] **A2. PD-gate the OPA836 per capture (~1 mA).**
      In the autonomous tick: `board_rx_en(true)` → measure →
      `board_rx_en(false)`. **Leave the rails up** — the bias network and
      coupling caps stay charged, so there is no `RAIL_SETTLE_MS` and no
      discard capture, unlike full rail gating. Today `RX_EN` is only ever
      cleared as a side effect inside `board_pwr_rx(false)`, which the
      autonomous path reaches only at `AUTO_STOP`.
      *Acceptance:* `uss_amp_ups`/`uss_amp_dns`/`uss_snr_db` unchanged against
      the 34.0 dB / 18-day baseline. If they move, the amp needs more settle.

- [ ] **A3. (optional) Gate the boost + VCC_TX muxes between captures.**
      Tens of µA — the smallest prize, but the TPS61240 currently runs
      continuously to feed an idle level shifter. `board_boost()` already
      toggles it mid-capture for the "BOOST 2" noise mode, so it is proven.

- [ ] **A4. Fix the totalizer wrap.** At zero flow `uss_vol_ml` climbs ~17 L
      per 5 min and tops out at 4,294,437 mL. 2³²/1000 = 4,294,967: the
      accumulator is a **uint32 of µL reported as mL**, wrapping every ~21 h.
      Integrate signed, and either widen it or expose a wrap counter — the
      master reads only the absolute value every 5 min, so a wrap is
      indistinguishable from reverse flow.
      (The ~3.4 L/min phantom flow driving the wrap is the uncalibrated cell —
      known and accepted — but the wrap survives calibration.)

- [ ] **A5. Find out why `uss_tof_comp2_us` stopped on 2026-08-24.** 97 points
      that day, then nothing for 9 days while every other USS key kept flowing.
      Deliberate change or a code path that quietly stopped emitting?

- [ ] **A6. (optional) Latch min/max/mean flow since last read.** Makes a
      longer ESP sample interval lossless for diagnostics — 15-min records that
      still describe a 1 Hz process. Spare register space at 0x1C–0x1E.

- [ ] **A7. (optional, later) Adaptive rate** — slow when idle, fast on flow.
      Worth it for burst capture, *not* for power (see §3). Needs the zero-flow
      offset fixed first or the threshold sits permanently triggered.

### B. Communication module firmware (this repo)

- [ ] **B1. Restore `vac2_mv` and `ts_stat` (and ideally `tdie_c`) telemetry.**
      The 08-15 trim to 22 keys dropped `vac2_mv`, `vindpm_mv`, `vreg_mv`,
      `weather_good`, `eco_chg`, `tdie_c`, `ts_pct`, `ts_stat`, `press_mbar`.
      Consequence found this session: with no `vac2_mv` there is no way to tell
      "no panel voltage" from "panel fine, charger refusing". Indoors
      `light_ch0` settled it; outdoors that argument does not exist. Required
      before the panel swap.

- [ ] **B2. Log VBAT *during* modem transmit into the status record.** Every
      VBAT sample today is taken with the modem off, so the sag under the
      A7672's ~2 A burst has never been measured — and that sag, not energy, is
      what sets the minimum battery size. A single mid-session read in
      `cell_session()` turns battery sizing from a datasheet estimate into a
      measurement.

- [ ] **B3. Retune MPPT for the small panel** (do together with C1):
      `MPPT_VINDPM_START_MV` 14000 → ~5000, `MPPT_VINDPM_MIN_MV` 5000 → ~3800.
      The 5000 floor is our choice, not the chip's — the BQ25792 is
      **buck-boost**, VBUS range 3.6–24 V, so a 6 V panel at Vmp ~4.5 V when
      hot is still fine. Without the retune the MPPT clamps against the floor
      and sits off the maximum power point.

- [ ] **B4. Clear the NVS `voc_max` key when the panel changes.** It still
      holds the 18 V panel's best-ever Voc, and the poison guards deliberately
      make the reference slow to fall — the sun-hours detector would report
      permanent overcast. Needs a mechanism or a documented procedure.

- [ ] **B5. (optional, small) Trim per-wake cost.** LTR-303 costs 150 ms every
      wake for a reading that has been 0 for 18 days in the box — sample it
      every 12th wake. Outdoors, `mppt_step()` adds 600–900 ms per wake (3
      perturb steps at 150 ms plus an hourly 250 ms Voc); the operating point
      does not move on a 5-min timescale, so every Nth wake is enough. The
      200 ms console drain before sleep only matters on USB.

- [ ] **B6. (probably NOT needed) Sample interval 5 → 15 min, upload 12 → 24 h.**
      See §3 — after A1+A2 there is enough margin to keep 5-minute sampling.
      Change these for margin, not necessity.

- [ ] **B7. Decision to record: keep GPIO14 always-on.** Cutting the
      ultrasonic board's rail *is* firmware-only (the switch is fitted, and
      `I2C_LINK.md` §2.0 documents the SDA/SCL-low sequence needed to avoid
      back-feeding through the I²C ESD clamps). But after A1+A2 the module
      costs ~2.4 mAh/day, so the rail cut would save that last few percent and
      cost continuous totalizing. Not worth it.
      *Open question:* confirm the harness actually has the module on the
      switched rail rather than always-on VSYS.

### C. Hardware to have on the bench

- [ ] **C1. 6 V / 1 W panel** (~1 CHF) — works electrically; measure Voc in
      full sun before trusting the label. For the deployed fleet buy ETFE or
      proper laminate: cheap epoxy potting delaminates under UV within a year
      or two. Voltage is not the deciding factor — the buck-boost handles it.
- [ ] **C2. 18650, 2000–2500 mAh**, with protection PCB, solder tabs not a
      spring holder (holder contact resistance lands on the same sag budget).
      Sized by ESR for the 2 A modem burst, not by energy — 30–80 mΩ gives
      60–160 mV of sag. The 5000 mAh pack is ~2.5× larger than needed.

---

## 3. Expected outcome

| state | mAh/day | autonomy, 2500 mAh 18650 |
|---|---|---|
| today | 114 | 18 days |
| **after A1 + A2** | **~40** | **~50 days** |
| + B5/B6 if wanted | ~25 | ~80 days |

Against the 5–10 days of overcast that actually needs riding out, **A1 + A2
alone give 5× margin while keeping 5-minute sampling and 12-hour uploads.**
That is the headline: the fixes buy resolution back, not just runtime.

Derate ~25% for cell aging after two years at 45–57 °C enclosure temperature.
Recovery: a 1 W panel yields ~500–600 mAh on a decent day, so a drained pack
refills in 3–4 good days.

## 4. Verification

1. **Night slope** (00:00–05:00 UTC, no sun, no charging) is the clean metric —
   it isolates idle draw from cellular. Baseline to beat: **0.61–0.82 mV/h**.
   After A1+A2 expect roughly 0.15–0.25 mV/h.
2. **Signal integrity after A2:** `uss_amp_*` and `uss_snr_db` must be
   unchanged (34.0 dB baseline).
3. **Charger efficiency**, once B1 restores `vac2_mv`: plot
   `vbus_mv × ibus_ma` against `vbat_mv × ibat_ma` versus input power. This is
   what decides whether the BQ25792 is still the right chip at the new scale —
   its ~15 µA quiescent is negligible (~0.4 mAh/day), so the only real question
   is conversion efficiency at low irradiance. Decide with the curve, not on
   suspicion; a swap to a nano-power harvester (BQ25570, AEM10941) would cost
   the dual input, the full ADC set, JEITA and ship mode.
4. **Battery sag** from B2: headroom above the 3600 mV modem floor tells you
   how small a cell you can actually run.

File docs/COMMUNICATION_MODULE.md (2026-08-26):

# ecoTrace Communication Module — system description

**Scope.** What this board is, how the firmware behaves in the field, what it
stores, and exactly what it sends to ThingsBoard. Written 2026-08-13 against
firmware **idf-0.10**. Companion document on the sensing side:
`Ultrasonic/Firmware/docs/I2C_LINK.md` (the link contract) — the two are
designed to be read together.

---

## 1. The plan

The module is the **communications and power half of a solar-powered remote
node**. It is the long-term replacement for a fleet of MicroPython
"bucket-communication" devices (20 units, six months in Kenya and Malawi):
same job, but engineered for unattended operation with no local support.

Design commitments, in priority order:

1. **Never lose data.** Sampling and logging must survive anything the uplink
   does. Records go to external flash first; the network is a separate,
   failable concern.
2. **Never expose the fleet.** All telemetry travels over TLS. There is no
   plaintext fallback at any escalation level — better no data than a leaked
   device credential or a compromised server.
3. **Never drain the battery chasing a network.** Outages are waited out, not
   fought. Roughly two short attempts per day; the log keeps banking meanwhile.
4. **Survive the season, not the demo.** Deep sleep between samples, a charge
   profile that respects battery chemistry and weather, and a park mode that
   refuses to write flash on a dying pack.

The node splits across two boards: **this one** (ESP32-C6: power, storage,
uplink) and the **ultrasonic flow module** (MSP430FR6043 + gas cell). This
board owns the wake schedule, so it owns the I²C bus; the ultrasonic module
joins as a slave peripheral. See §7.

---

## 2. The hardware (Rev A, 2026-04-23)

Single ESP32-C6-MINI-1 board. Pin map source of truth:
[`lib/EcoTrace/ecotrace_pins.h`](../lib/EcoTrace/ecotrace_pins.h) — verified
against the schematic 2026-05-05.

### 2.1 Blocks

| Block | Part | Interface | Notes |
|---|---|---|---|
| MCU | ESP32-C6-MINI-1 | — | 4 MB flash used; RISC-V + LP core (LP core unused so far) |
| Charger / PMIC | BQ25792 | I²C 0x6B | 1S Li-ion, dual input (USB + solar), MPPT via VINDPM, full ADC set, JEITA |
| Cellular | SIMCom A7672E-LASE | UART1 @115200 | LTE Cat-1, PPP; separate switched rail |
| External storage | GD25Q128 (16 MB NOR) | SPI | the log ring; deep-power-down between wakes |
| Light | LTR-303 | I²C 0x29 | always-on 3V3 rail |
| Accelerometer | SC7A20 | I²C 0x18/0x19 | tilt/tamper; always-on rail |
| Barometer | MS5837-02BA | I²C 0x76 | pressure + temperature |
| Secure element | ATECC608B | I²C 0x60 | fitted, **not yet used** (mTLS endgame) |
| Flow module | MSP430FR6043 (separate PCB) | I²C 0x2C | slave; see §7 |
| Pressure (flow board) | WF280A | I²C 0x38 | read directly by this board; see §7 |

### 2.2 Pins that matter

```
I²C  SDA 6, SCL 7 (100 kHz, external 4k7 pull-ups)
SPI  MOSI 4, MISO 5, CLK 18, CS_flash 8
Modem TX 20, RX 21, PWRKEY 22, PWR_EN 23, STATUS 0
Wake  QON/button 2 (EXT1), sensor INT 3, BQ INT 19
Misc  LED 1, external sensor rail 14 (active HIGH)
```

Two hardware behaviours the firmware must respect:

- **PWRKEY is inverted** by Q409: GPIO HIGH = PWRKEY asserted at the modem.
  It is held **LOW through deep sleep** — holding it asserted burns ~0.3 mA in
  the inverter (lesson from dl-2.10).
- **The on-board sensors are on the always-on 3V3 rail**, not the switched
  GPIO14 rail. They are low-powered over I²C, never by cutting their supply.

### 2.3 Power tree

Solar panel (1.2 W) and/or USB → BQ25792 → 1S LiPo (2500 mAh) → RT9080 LDO →
3V3 always-on rail (ESP32 + sensors + flash). The modem has its own switched
high-side rail off VBAT, enabled only for an uplink session. GPIO14 switches an
external-sensor header rail, independent of the on-board sensors.

---

## 3. How the firmware works

Source: [`idf/src/`](../idf/src). ESP-IDF (PlatformIO `framework = espidf`,
pioarduino platform 53.03.13). The Arduino implementation in `src/datalogger`
is **frozen at dl-2.14** as a hardware-validated reference — do not modify it.

### 3.1 The wake cycle

Every wake is a complete, self-contained transaction — there is no long-running
main loop. `app_main()` runs once and ends in deep sleep.

```
wake (timer / button / crash-reboot)
  ├─ enforce 120 s task watchdog          (runtime, not just sdkconfig — §3.6)
  ├─ board_init(): rails safe, PWRKEY idle
  ├─ BQ25792 up, read VBAT
  ├─ park-mode check ──────────────► if parked: sleep 3600 s, done
  ├─ flash log begin (recover cursors if cold/crashed)
  ├─ solar_on_wake(): MPPT step, harvest accounting, weather verdict, VREG target
  ├─ read_sample(): charger + all sensors + flow module → one 128 B record
  ├─ append record to the flash ring
  ├─ upload if due (12 h schedule, or button) ─► §4
  └─ deep sleep (300 s; ×6 when critically low)
```

State that must survive sleep (ring cursors, MPPT operating point, harvest
counters, upload schedule, boot/crash counters) lives in **RTC RAM**, with the
flash-log cursors additionally journalled to flash sector 0 so a power cut is
recoverable. A cold boot rebuilds the ring cursors by forward-scanning the
chip.

### 3.2 Sampling and the flash ring

- Interval **300 s** (5 min) during validation. For deployment this is expected
  to drop to 10–15 min, ideally by remote configuration.
- One **128-byte record** per sample, self-validating: magic + sequence number
  + CRC16-CCITT. Fixed size keeps the ring trivial — 32 records per 4 KB
  sector, never crossing a page.
- Capacity: 4095 data sectors × 32 = **131,040 records ≈ 1.25 years** at 5 min.
  Records are only dropped from the tail when the ring wraps, and the upload
  cursor only advances on a broker **PUBACK**, so an unacknowledged record is
  re-sent rather than lost.
- Record magic is a layout version: `ECL3` → `ECL4` at idf-0.10 (64 → 128 B,
  flow-module fields added). **A magic bump makes older pending records
  unreadable**, so a build carrying one must be flashed immediately after a
  clean upload.

### 3.3 Charging, MPPT and weather

- **MPPT** on the BQ25792's VINDPM input-regulation point: fractional-Voc
  (80 % of a periodically measured open-circuit panel voltage) plus a small
  perturb-and-observe hill climb, 3 steps per wake, clamped 5–22 V.
- **Weather-aware charge target.** A "good day" caps the pack at 4050 mV
  (~80 % SoC) instead of 4200 mV — meaningfully longer calendar life. USB
  always charges full: plugging a cable in is a deliberate "fill it up".
- Two independent signals declare a good day; either suffices:
  - **harvest** — integrated input current ≥ 1000 mAh today or yesterday;
  - **Voc sun-hours** — hourly open-circuit panel voltage ≥ 80 % of a
    self-calibrating best-ever Voc (persisted in NVS, with guards against one
    glitched reading poisoning the reference), ≥ 4 such hours.

  The second exists because harvest goes blind when the battery is already
  full — found in the 2026-08-12 telemetry audit.
- **JEITA** thermal charge suspension is the charger's own doing and is now
  fully observable in telemetry (`tdie_c`, `ts_pct`, `ts_stat`) after an
  afternoon lockout at ~57 °C box temperature was misread as a fault.

### 3.4 Battery protection

| Threshold | Value | Behaviour |
|---|---|---|
| Cellular floor | 3600 mV | no modem attempts below (resting voltage) |
| WiFi floor | 3450 mV | no WiFi attempts below |
| Park entry | 3300 mV | no flash writes, no sensors, 3600 s sleeps |
| Park exit | 3450 mV | hysteresis |
| Critical sampling | 3350 mV | sample interval ×6 (30 min) |

Park mode exists to avoid the one unrecoverable failure: a brownout in the
middle of a flash write.

### 3.5 Clock

Correct timestamps matter more than they look — every record carries one, and a
wrong clock silently corrupts a year of data. Carrier NITZ is **never** used
(it produced a 1970→2070 parse bug). Instead: multi-server SNTP
(time.google.com, pool.ntp.org) cross-checked against the **HTTPS `Date`
header** from the ThingsBoard server. The carrier can intercept UDP NTP; it
cannot rewrite a header inside our TLS session, so a disagreement > 120 s
vetoes the SNTP result. Sanity bounds: [2026-01-01, 2036-01-01). Re-synced
every uplink session.

A record sampled before the first sync stores `ts_s = 0` and is placed in time
at upload, from the **monotonic uptime counter** it carries: the elapsed time
between that record and the newest one is real elapsed time, whatever the sleep
interval happened to be. That matters because a clockless device is exactly the
device whose intervals are irregular — critical-battery mode (×6), park mode
(3600 s), button wakes, crash reboots. Uptime is only comparable within one
boot epoch (a cold boot restarts it and rolls `boot_id`), so records from an
older epoch fall back to a position-in-the-ring estimate at the nominal
interval — coarse, but the only thing left.

### 3.6 Watchdog

120 s task watchdog, panic on expiry. It is set **at runtime** with
`esp_task_wdt_reconfigure()` and not only in `sdkconfig.defaults`: regenerating
the sdkconfig silently reverted the timeout to 5 s once and boot-looped the
board during the modem's 8 s settle (idf-0.5/0.6).

---

## 4. Uplink: what goes to ThingsBoard, and how

### 4.1 Transport

**Cellular is primary, WiFi is backup** — the reverse of what is convenient on
a bench, but correct for the field.

```
cell_session:  modem rail on → PWRKEY → 8 s fed settle → esp_modem sync
               → +CEREG registration (stat 1 or 5) → PPP up
               → clock sync → MQTT → drain → status record
wifi_session:  same publisher, different netif
```

Registration is bounded: 25 s fail-fast if CSQ still reports no signal, 45 s
normal attach budget, 180 s once-daily deep search.

**Broker:** `mqtts://eu.thingsboard.cloud:8883`, TLS with the **ISRG Root X1**
certificate pinned into the image. Authentication is the ThingsBoard device
access token as the MQTT username. **There is no plaintext fallback** — if TLS
cannot be established the session fails and the data waits in flash.

**Topic:** `v1/devices/me/telemetry`, QoS 1.

### 4.2 Batching and pacing

Records are drained oldest-first in batches of **8**, as a JSON array, with a
400 ms gap between batches (ThingsBoard Cloud dislikes bursts). The ring cursor
advances only on PUBACK. Broker connection churn — routinely ~18 s on TB Cloud
— is handled by waiting out the client's auto-reconnect (up to 15 s) and
retrying the publish once.

A **status record** is published at both the start and the end of every
session. Sending it only at the end lost it nearly every time to the
end-of-session disconnect; health telemetry must not depend on the drain
succeeding.

### 4.3 Payload format

Historical records carry an explicit timestamp:

```json
[{"ts": 1786000000000, "values": {"vbat_mv": 3987, "ibat_ma": 142, ...}},
 {"ts": 1786000300000, "values": {...}}]
```

Status records are a single object of the same shape.

### 4.4 Telemetry keys

**Per record** (every sample):

| key | unit | meaning |
|---|---|---|
| `vbat_mv` | mV | battery voltage |
| `ibat_ma` | mA | battery current (+ charging, − discharging) |
| `bat_mw` | mW | derived battery power |
| `soc_pct` | % | crude voltage-based state of charge (temperature-sensitive — §6) |
| `vbus_mv`, `ibus_ma` | mV, mA | charger input rail |
| `vac2_mv` | mV | solar input voltage |
| `vsys_mv` | mV | system rail |
| `vindpm_mv` | mV | MPPT operating point |
| `vreg_mv` | mV | active charge-voltage target (4200 or 4050) |
| `chg_stat` | enum | BQ25792 charge state |
| `fault0`, `fault1` | bitfield | BQ25792 fault registers |
| `harvest_mah` | mAh | solar charge harvested today |
| `solar`, `usb` | 0/1 | input present |
| `weather_good`, `eco_chg` | 0/1 | weather verdict, eco charge cap active |
| `light_ch0`, `light_ch1` | counts | LTR-303 visible+IR, IR |
| `acc_x_mg`, `acc_y_mg`, `acc_z_mg` | mg | SC7A20 |
| `press_mbar`, `temp_c` | mbar, °C | MS5837 |
| `tdie_c` | °C | BQ25792 die temperature |
| `ts_pct` | % | battery NTC as % of bias |
| `ts_stat` | bitfield | charger JEITA verdict |
| `sensor_ok` | bitfield | bit0 BQ, bit1 LTR-303, bit2 SC7A20, bit3 MS5837, bit4 flow module, bit5 WF280A |

`sensor_ok` matters: without it a zero reading is indistinguishable from a dead
sensor.

**Per record, only when the flow module answered** (`sensor_ok` bit 4):
`flow_lpm` (L/min), `uss_dtof_ns` (ns), `uss_temp_c` (°C), `uss_code`
(122 = valid, 126 = no echo), `uss_amp_ups`, `uss_amp_dns` (ADC counts),
`uss_snr_db` (dB), `uss_gain` (index), `uss_vol_ml` (mL, totalizer — reserved),
`uss_status` (link status bits).

Signal metrics are sent even when no echo was found; that is what makes a
remote gain problem diagnosable from a dashboard.

**Per record, only when the WF280A answered** (bit 5): `wf_praw`, `wf_traw` —
raw 24-bit counts. The vendor compensation polynomial is private, so
conversion to physical units happens server-side once characterized.

**Per session** (status record): `fw` (version string), `transport`
(`cell`/`wifi`/`none`), `rssi_dbm`, `wifi_rssi_dbm`, `cereg_stat`, `backlog`
(records still pending), `boot_id`, `boot_count`, `wake_count`, `crash_count`,
`reset_reason`, `vbat_mv`, `sun_h`, `voc_max_mv`.

### 4.5 Schedule and escalation

Uploads every **12 h**, plus a manual button press. On failure: up to **2
retries at 30 min**, then back to the 12 h schedule. Escalation varies
*technique*, never *tempo* — a multi-day outage costs roughly two short
attempts per day while everything banks in flash. If an upload attempt crashes
the board, the next attempt skips cellular once (one-shot) and tries WiFi.

**Datapoint budget:** ~26 keys × 288 samples/day ≈ 7.5 k datapoints/device/day
at the current 5-minute interval, more with the flow keys. Fine for validation;
for a fleet, lengthen the interval and/or send daily aggregates.

---

## 5. Build, flash, deploy

```bash
cd idf && pio run                 # build
pio run -t upload                 # normal flash
pio device monitor                # 115200
```

Partition layout (4 MB): dual 1.9 MB OTA slots with bootloader rollback
enabled, 64 KB coredump, NVS.

**ESP32-C6 flashing quirk that will bite anyone new:** the USB-Serial/JTAG port
only exists while the chip is awake, and *opening the port resets the chip*
(reset reason 11), wiping RTC RAM. On a deep-sleeping unit, flashing means
catching a wake window — a background watcher that waits for the port to
appear, then writes the app only at `0x10000`. Observe a running unit
sparingly: every serial connection is a cold boot.

Secrets (`idf/src/secrets.h`, gitignored): APN, broker URI, device access
token, WiFi credentials.

---

## 6. Field lessons worth carrying forward

- **Afternoon "battery drain" that isn't.** A hot pack shows depressed
  open-circuit voltage (~50 mV at +30 °C) which recovers on cooling. It looks
  like drain in `vbat_mv`/`soc_pct` with `ibat_ma` at zero. Real, reversible,
  and a reason not to trust voltage-based SoC in the heat.
- **Enclosure temperature drives everything.** At ~57 °C box temperature the
  charger's JEITA protection suspends charging 12:00–18:00 UTC. The hardware is
  behaving correctly; the enclosure is the problem.
- **The light sensor is nearly useless inside a box.** Panel Voc is the better
  weather signal — it exists whether or not charging is happening.
- **Broker churn is normal**, not a fault. Publishes must be retry-wrapped.

## 7. Interface to the ultrasonic flow module

One bus, one master: **this board is the master**, because it owns the wake
schedule. The MSP430FR6043 is an I²C **slave at 0x2C**, and this board reads
the flow board's WF280A pressure sensor (0x38) directly as another device on
the same wires.

Handshake per sample: write `MEASURE` to the command register, poll status
until ready (3 s budget), read a 28-byte CRC8-guarded result block in one
transaction. Integers only on the wire — flow in µL/min, ΔToF in picoseconds,
temperature in 0.01 °C, SNR in half-dB.

The contract is `uss_link.h`, held **byte-identical in both repositories**
(`idf/src/uss_link.h` and `Ultrasonic/Firmware/fw/uss_link.h`); they must be
changed together. Master-side driver: `idf/src/uss.c`. Full rationale, wiring,
power constraints and bring-up checklist:
**`Ultrasonic/Firmware/docs/I2C_LINK.md`**.

Two constraints that belong here as well as there:

- The flow board's `/VCC` must be fed from this board's always-on rail. An
  unpowered board on a shared bus drags SDA/SCL down and takes out every other
  sensor.
- The flow module's own I²C master (its bit-banged WF280A driver) must be
  dormant in the deployed build. Two masters on one bus is a bus fight.

**Status (2026-08-15): WORKING on hardware, end to end.**

Verified: `sensor_ok=0x3F` (all six devices), `uss_code=122`, absolute ToF
131.3 us -> 335 m/s, autonomous mode `st=0x09`, volume accumulating, records
uploading over LTE with the backlog draining to zero.

### How it is driven

The module runs **autonomously at 1 Hz** and integrates flow into `VOL_ML`; this
board wakes every 5 min and reads the latest latched block plus the totalizer.
Sample rate is decoupled from bus traffic, which is also the prerequisite for
LP-core sampling later. Rules the master must follow are in
`Ultrasonic/Firmware/docs/PROTOCOL.md` section 8.3 -- in particular: only send
`AUTO_START` when `STATUS.AUTO` is clear (it zeroes the totalizer), wait for
`AUTO` and then for `READY` before sampling, and never send `MEASURE` while AUTO
is set.

### Power, and why it matters more than it looks

The ultrasonic board is on the **switched SENSOR rail (J404, GPIO14)**, and the
rail is **always on** except during a deliberate power cycle. Three findings
force that:

1. **An unpowered board on the shared bus clamps it.** Its ESD diodes hold
   SDA/SCL near 0.6 V and its own 4k7 pull-ups become pull-downs to a dead rail.
   The symptom is every device unreachable -- the BQ25792 on our own always-on
   rail included -- and a record of all zeros.
2. **Leaving the rail off in sleep costs power, not saves it**: our pull-ups
   then feed the sleeping board through those clamps, ~1.4 mA continuously.
3. **Cutting VCC does not power it down while the bus idles high.** To
   power-cycle it you must hold SDA/SCL LOW for the whole off window --
   `board_sensor_power_cycle()` does this, and `eco_i2c_hold_low()` tears the
   bus down to make it possible. **CAUTION: that blocks the charger and every
   other sensor for the duration, so keep the window short.**

`BOARD_SENSOR_BOOT_MS` is **3000**: that board's init primes the USSXT crystal
with up to 5 x 300 ms retries, and talking to it sooner gets a clean NACK from a
module that is merely still booting.

### Telemetry keys

22 per record (trimmed from ~40 on 2026-08-15; the 128-byte flash record still
carries every field, only the uplink is trimmed):

`vbat_mv ibat_ma soc_pct vbus_mv ibus_ma chg_stat harvest_mah solar usb`
`light_ch0 acc_x_mg acc_y_mg acc_z_mg temp_c sensor_ok`
`p_gas_hpa dp_hpa`
`uss_tof_us uss_dtof_us uss_code uss_snr_db uss_vol_ml`

* `uss_tof_us` is the **mean** of both directions: the mean is the
  speed-of-sound (composition) signal, the difference is flow and `uss_dtof_us`
  carries that at far better resolution.
* `uss_vol_ml` is a counter to be **differenced**; it wraps at 4294 L.
* `flow_lpm` is deliberately **not** published: the VFR constants are wrong for
  this cell, so it is misleading rather than merely useless.
* Datapoint budget matters -- at ~40 keys x 8 records ThingsBoard Cloud closed
  the MQTT connection.

## 8. Roadmap

In rough priority order:

1. **OTA with rollback** — staged through the 16 MB external flash with a
   golden image. This is what ends bench visits; the partition table and
   bootloader rollback are already in place.
2. **Remote configuration** via ThingsBoard shared attributes — per-device
   charge target (server-side weather-informed, no on-device forecast API),
   sample interval, "stay awake for OTA". NVS-cached with a freshness window,
   falling back to the on-board Voc heuristic.
3. **Error-event log** in the coredump partition; health telemetry.
4. **NVS provisioning** — one image for the whole fleet.
5. **ATECC608B identity**, ending in mTLS. TLS must terminate on the ESP32, not
   in the modem's AT stack, for the secure element to be usable.
6. **LP-core sampling** while the HP core sleeps.
7. **Autonomous flow totalizer** on the MSP430 (register space reserved): flow
   integrated between samples is a far better volume estimate than 288
   instantaneous readings, and costs this board nothing.

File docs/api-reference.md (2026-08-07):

# API reference - EcoTrace driver library

Every peripheral on the board has a ready-to-call driver in `lib/EcoTrace/`. Include
the header you need and call the functions. This page lists what is available so you
can grab a function without reading the source.

All drivers default to the shared `Wire` / `SPI` instance and the addresses/pins in
`ecotrace_pins.h`, so construction is usually just `BQ25792 bq;`.

> **Logging your own sensor?** The datalogger is a plain starting point - edit
> `readSample()` in `src/datalogger/main.cpp` and read your sensor there, with any
> driver below, an Arduino library, or raw `Wire` / `analogRead`.

Typical setup at the top of `setup()`:

```cpp
#include "EcoTraceBoard.h"
EcoTrace::beginBoard();   // safe defaults: rails off, strapping-safe
EcoTrace::beginI2C();     // Wire on GPIO6/7
EcoTrace::beginSPI();     // SPI on GPIO18/5/4 (only if you use the flash)
```

---

## EcoTraceBoard (`EcoTraceBoard.h`, namespace `EcoTrace`)

| Function | Does |
|---|---|
| `beginBoard()` | safe GPIO defaults (modem + sensor rails off, releases sleep holds) |
| `beginI2C(freq=100k)` | start `Wire` on GPIO6/7, returns `TwoWire&` |
| `beginSPI()` | start `SPI` on the flash pins, both CS high, returns `SPIClass&` |
| `ledOn() / ledOff() / ledToggle()` | status LED (GPIO1) |
| `sensorRail(bool)` | external sensor rail (GPIO14) on/off |
| `deepSleepSeconds(s)` | hold rails off and deep-sleep; never returns |
| `wokeFromTimer()` | true if this boot was a timer wake (vs power-on/reset) |
| `wokeFromButton()` | true if the QON button woke us (EXT1 on GPIO2) |

`deepSleepSeconds()` arms both the timer and the QON button, so a short press
always wakes the board early.

## BQ25792 charger / PMIC (`BQ25792.h`)

The important one. Charging, ADC, status, faults, MPPT knobs. Register-accurate to
the TI datasheet.

| Function | Does |
|---|---|
| `begin() / isPresent()` | detect the chip (part number check) |
| `enableADC(continuous=true) / disableADC()` | turn the 16-bit ADC on/off |
| `enableIbatSensing(on=true)` | needed to read discharge current (IBAT < 0) |
| `readVbat_mV() readVbus_mV() readVsys_mV() readVac1_mV() readVac2_mV()` | voltages (1 mV) |
| `readIbat_mA() readIbus_mA()` | currents, signed (+ = charge / into VBUS) |
| `chargeState() / chargeStateName()` | not-charging / trickle / CC / CV / done ... |
| `vbusPresent() ac1Present() ac2Present() powerGood()` | input presence |
| `readFaults(f0,f1) / hasFault() / faultString(buf,len)` | fault decode |
| `setChargeVoltage_mV() setChargeCurrent_mA() setInputCurrentLimit_mA()` | limits |
| `setVINDPM_mV() / getVINDPM_mV()` | input-voltage regulation point (used for MPPT) |
| `enableCharging(on) setHIZ(on) disableWatchdog()` | control |
| `enableACDRV1(on) enableACDRV2(on)` | gate USB (AC1) / solar (AC2) input FETs |
| `enableExtILIM(on)` | ILIM_HIZ pin current clamp (cleared by `configureCharging`) |
| `setShipFETPresent(on=true)` | declare the external ship FET - **required** before any ship/reset action |
| `enterShipMode(immediate=true)` | power the board off: battery disconnected, ~129 µA |
| `systemPowerReset()` | hardware power-cycle everything on VSYS (~350 ms) |
| `configureCharging(ichg,iindpm,vreg)` | one-call: WD off, HIZ off, set limits, charge on |
| `readReg8/16 writeReg8/16 setBits` | raw register access for experimentation |

> ⚠️ **Ship mode gotcha.** `SDRV_CTRL` writes are silently discarded unless
> `SFET_PRESENT` (REG14 bit 7) is set first - the write is ACKed, the field reads
> back 0, and nothing happens. `enterShipMode()` / `systemPowerReset()` set it for
> you. Ship mode also requires **no input present** (USB or solar refuses it), and
> the board wakes on a ~1 s QON press *or* on any adapter being plugged in.

Solar note: the BQ25792 has no true MPPT. Track the panel's max-power point by
hill-climbing `setVINDPM_mV()` (see `mpptStep()` in the datalogger).

## ModemA7672 LTE modem (`ModemA7672.h`)

Hand-written AT driver for the A7672E. Use `sendAT()` / `uart()` for anything not
wrapped below.

| Function | Does |
|---|---|
| `begin(baud=115200)` | power rail + PWRKEY sequence, wait for AT/OK |
| `powerOff()` | graceful AT+CPOF then drop the rail |
| `statusHigh()` | modem STATUS pin (powered?) |
| `sendAT(cmd,expect="OK",timeout) / waitFor(needle,timeout)` | raw AT |
| `lastResponse() / uart()` | last reply buffer / the underlying Stream |
| `getInfo(buf,len)` | ATI |
| `simReady()` | AT+CPIN? -> READY |
| `waitForNetwork(timeout)` | registration (home/roaming) |
| `signalQuality_dBm()` | AT+CSQ in dBm |
| `batteryVoltage_mV()` | modem's own VBAT sense (AT+CBC) |
| `connectGPRS(apn)` | CGDCONT + CGACT |
| `httpGet(url,status[,body,len])` | HTTP GET, returns true on 2xx |
| `httpPost(url,ctype,payload,status[,body,len])` | HTTP POST, returns true on 2xx |
| `getUnixTimeMs()` | network time (AT+CCLK) as unix ms |
| `gpsEnable() / gpsGetFix(...)` | 🚧 stub - GPS untested on Rev A hardware |

## LTR303 ambient light (`LTR303.h`)

| Function | Does |
|---|---|
| `begin() / isPresent()` | detect + activate |
| `read(ch0,ch1)` | CH0 = visible+IR, CH1 = IR |
| `readCh0()` | convenience |
| `readLux()` | rough lux estimate (trends, not photometry) |
| `setActive(bool) / powerDown()` | active / standby |

## SC7A20 accelerometer (`SC7A20.h`)

| Function | Does |
|---|---|
| `begin() / isPresent()` | auto-detect 0x18/0x19, WHO_AM_I, 100 Hz |
| `readMilliG(x,y,z)` | acceleration in mg (+/-2 g) |
| `powerDown()` | low-power |
| `address()` | detected I2C address |

## ExtFlash - GD25Q128 NOR flash (`ExtFlash.h`)

Persists across power loss. Erase-before-write; page = 256 B, sector = 4 KB. The
full 16 MB is reachable via 3-byte addressing.

| Function | Does |
|---|---|
| `begin()` | wake + confirm GigaDevice JEDEC |
| `jedecId()` | mfg/type/capacity |
| `read(addr,buf,n)` | read bytes |
| `eraseSector(addr)` | erase 4 KB to 0xFF |
| `writePage(addr,buf,n)` | program <=256 B within one page |
| `powerDown() / wake()` | deep power-down for sleep |

## MS5837-02BA barometer (`MS5837.h`)

Off-board pressure / temperature sensor on the I2C hat header (J401), fixed
address 0x76. Handles the factory PROM (with CRC-4 check) and the full first- and
second-order compensation.

| Function | Does |
|---|---|
| `begin()` | reset, read calibration PROM, verify CRC-4 |
| `read(mbar, degC)` | one conversion pair at OSR 4096 (blocks ~40 ms) |
| `altitudeM(mbar, sea_level=1013.25)` | ISA altitude estimate |
| `isPresent() / coefficient(i)` | probe / raw calibration words |

Note it sits on the **always-on** 3V3 rail, so it cannot be switched off in deep
sleep; it idles at ~0.1 µA between conversions, which is negligible next to the
board's ~198 µA sleep current.

## ATECC608B secure element (`ATECC608B.h`)

Thin: presence + wake/sleep only. For provisioning / ECDSA signing use Microchip
CryptoAuthLib or SparkFun_ATECCX08a.

| Function | Does |
|---|---|
| `begin()` | wake pulse + probe (0x60 or 0x35) |
| `wake() / sleep()` | power state |
| `address()` | detected I2C address |

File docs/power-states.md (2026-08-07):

# Power states

The board's intended power/charging states are documented in the diagram
[`ecoTrace_power_states.pdf`](ecoTrace_power_states.pdf) in this folder.

Key ideas (see the PDF for the authoritative version):

- The **BQ25792** is the PMIC: it manages input selection (USB / VBUS via VAC1, solar
  via VAC2), battery charging, and the regulated system rail **VSYS** that powers the
  ESP32-C6 and peripherals.
- Deep-sleep duty cycling (see `src/datalogger/`) is how the logger keeps average
  current low: the ESP32 sleeps most of the time, waking to sample and - less often -
  to power the modem and transmit.
- The modem rail (GPIO23) and external sensor rail (GPIO14) are switched off and held
  off during sleep so they don't dominate the sleep budget.

## The QON button (power/wake)

One button drives the shared QON net (BQ25792 QON input + ESP GPIO2, external
pull-up):

| Action | Effect | Implemented by |
|---|---|---|
| short press (asleep) | wakes the ESP for an immediate sample | EXT1 deep-sleep wake on GPIO2 |
| 3 presses in ~2.5 s | WiFi **OTA mode** for 5 min (`pio run -e datalogger_ota -t upload`) | firmware (`ota.cpp`) |
| hold ~3 s, then release | **power off**: BQ ship mode, battery disconnected, ~129 µA | firmware (`BQ25792::enterShipMode`) |
| hold ~1 s (while off) | **power on**: BQ exits ship mode, board cold-boots | BQ hardware (tSM_EXIT) |
| plug in USB or solar (while off) | also exits ship mode - a shipped board revives itself in the field | BQ hardware, not disableable |
| hold ~10 s (any time) | full hardware power cycle (ship FET off 350 ms) - the unbrick reset | BQ hardware (tRST), cannot be disabled |

> **`SFET_PRESENT` (REG14 bit 7) must be set before any `SDRV_CTRL` action.** It
> tells the charger that an external ship FET (Q204) is fitted. Without it every
> ship-mode / shutdown / system-power-reset write is silently discarded: the
> write is ACKed, the field reads back 0, and nothing happens. This cost a full
> debugging session on 2026-08-07; `BQ25792::enterShipMode()` and
> `systemPowerReset()` now set it automatically.

Ship mode entry requires **no input present** - with USB or solar connected the
charger refuses (documented), so the board only powers down once unplugged. The
button never enters ship mode while it is still held down, because QON low for
~1 s is the charger's wake-from-ship signal.

Notes: ship mode disconnects only the battery - with USB/solar plugged the board
stays powered and only goes dark when unplugged; the battery does **not** charge
while in ship mode. Correction to the PDF: ship mode wakes on the QON button as
well as on adapter insertion.

> TODO: transcribe the state diagram into text/mermaid here so it is searchable and
> reviewable in-repo, not only as a PDF.

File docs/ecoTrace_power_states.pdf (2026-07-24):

10

−4 | 10
−3 | 10
−2 | 10
−1 | 10
0
Current (A, log scale)

### A7672 modem active

| 22 mA

### ESP32-C6 active

| 910 µA

### Light sleep

| 198 µA

### Deep sleep

### Ship mode

450 mA

129 µA

State | Current | Power @4 V | LP I²C | What the device can do
A7672 modem active | 450 mA | 1.80 W | ✓ | Cellular attach + data TX/RX (peaks higher)
ESP32-C6 active | 22 mA | 89.20 mW | ✓ | MCU awake: code, sensors, GPIO (WiFi off)
Light sleep | 910 µA | 3.64 mW | ✓ | CPU halted, RAM retained; wakes in µs
Deep sleep | 198 µA | 0.79 mW | ✓ | RTC timer + LP core alive; RAM not retained
Ship mode | 129 µA | 0.52 mW | ✗ | Battery disconnected; wakes only on solar/USB

# ecoTrace – Communication Module

## Power consumption by device state

LP I²C: the ESP32-C6 LP core can poll the LP_I²C devices in deep sleep, without waking the main core. Measured with a Joulescope JS220 from a bench PSU at 4.0 V. Board: ESP32-C6-MINI-1.
Figures are WITHOUT external sensors – the switched external-sensor rail is off.

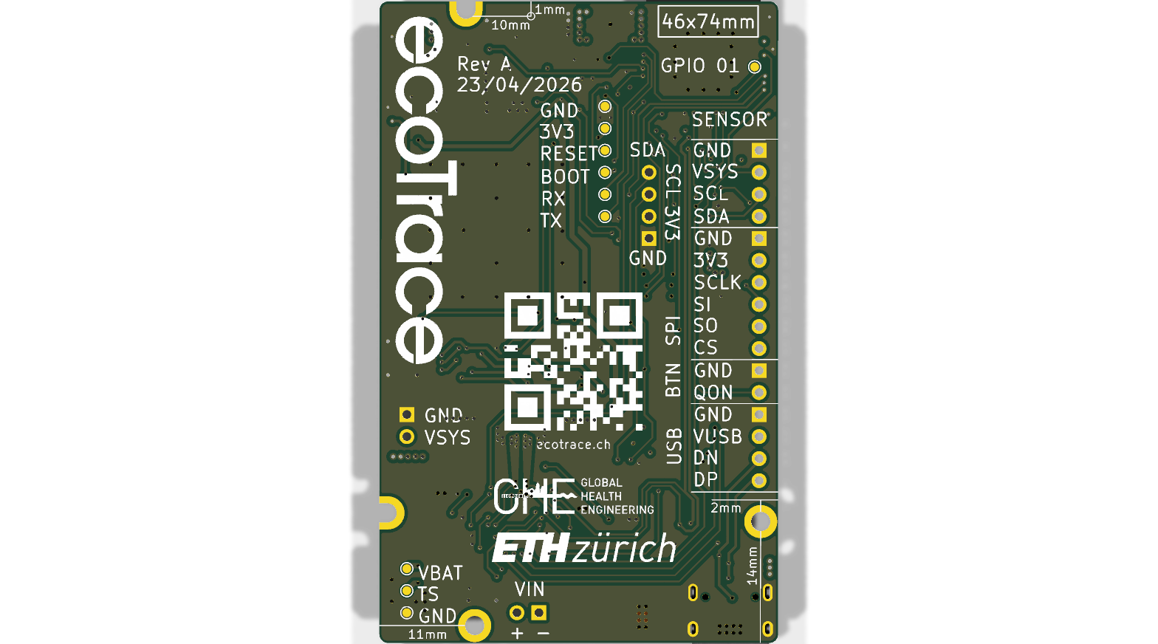
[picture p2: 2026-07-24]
hardware/exports/board-bottom.png

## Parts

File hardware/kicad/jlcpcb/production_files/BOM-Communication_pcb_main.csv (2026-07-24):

Comment | Designator | Footprint | LCSC | Quantity
100kΩ | R201,R209,R418,R421,R427,R454 | R_0402 | C25741 | 6
100nF | C202,C206,C217 | C_0603 | C14663 | 3
100nF | C402,C409,C603,C604,C605,C607,C697,C698 | C_0402 | C1525 | 8
100pF | C418 | C_0805 | C1790 | 1
100Ω | R208 | R_0603 | C22775 | 1
10kΩ | R403,R404,R405,R406,R407,R408,R415,R416,R417,R419,R420,R422,R423,R603,R604,R655,R699 | R_0402 | C25744 | 17
10pF | C404 | C_0402 | C32949 | 1
10uF | C203,C204,C205,C207,C209,C210,C211,C212,C218,C219 | C_1206 | C13585 | 10
150kΩ | R223 | R_0603 | C22807 | 1
1N5819WS | D407 | SOD-323_L1.8-W1.3-LS2.5-RD | C191023 | 1
1kΩ | R402,R413,R414 | R_0402 | C11702 | 3
1nF | C220,C221 | C_0402 | C1523 | 2
1uF | C417 | C_0603 | C15849 | 1
1uF | C411,C601,C602,C606,C693 | C_0402 | C52923 | 5
2.2uF | C415 | C_0805 | C377773 | 1
2.2Ω | R424 | R_0603 | C22939 | 1
220kΩ | R212 | R_0603 | C22961 | 1
22pF | C406,C407,C408 | C_0402 | C1555 | 3
22uF | C416 | C_0805 | C45783 | 1
22Ω | R409,R410,R411,R650,R651 | R_0402 | C25092 | 5
27kΩ | R224 | R_0603 | C22967 | 1
3.3kΩ | R225 | R_0402 | C25890 | 1
300Ω | R213,R214 | R_0805 | C17617 | 2
33pF | C403 | C_0402 | C1562 | 1
3kΩ | R202 | R_0603 | C4211 | 1
4.7kΩ | R425,R601,R602 | R_0402 | C25900 | 3
4.7uF | C201 | C_1206 | C29823 | 1
47kΩ | R426 | R_0402 | C25792 | 1
47nF | C208,C213,C214 | C_0603 | C1622 | 3
47uF | C401,C410 | C_1206 | C96123 | 2
5.1kΩ | R222 | R_0402 | C25905 | 1
A7672E (LASE) | U403 | LGA-124_L24.0-W24.0-P1.0-A7670C-LASS | C6116733 | 1
AO3400A | Q201,Q202,Q203,Q204,Q206,Q401,Q402,Q403,Q405,Q406,Q408,Q409 | SOT-23-3_L2.9-W1.3-P1.90-LS2.4-BR | C20917 | 12
AO3401A | Q404,Q407 | Q_SOT-23 | C15127 | 2
ATECC608B-SSHDA-T | U604 | SOIC-8_L4.9-W3.9-P1.27-LS6.0-BL | C1518769 | 1
BQ25792RQMR | U202 | QFN-29_L4.0-W4.0-P0.40-TL-BQ25792RQMR | C2862876 | 1
BZT52C9V1S | D203,D204 | SOD-323_L1.8-W1.3-LS2.5-RD | C22614 | 2
ESD9X3.3ST5G | D403,D406 | SOD-923_L0.8-W0.6-LS1.0-RD | C130456 | 2
ESDBW5V0A1_C5173252 | U404 | X1-DFN1006-2_L1.0-W0.6-P0.65-BI | C5173252 | 1
ESP32-C6-MINI-1-N4 | U405 | WIFIM-SMD_61P-L16.6-W13.2-P0.80-ESP32-C6-MINI-1-N4 | C5736265 | 1
GD25Q128ESIGR | U602 | SOP-8_L5.3-W5.3-P1.27-LS8.0-BL | C2928891 | 1
GZ2012D601TF | L403,L404 | L0805 | C1017 | 2
Green | D201,D402,D420 | D_0805 | C2297 | 3
LTR-303ALS-01 | U407 | TDFN-6_L2.0-W2.0-P0.65-BL | C364577 | 1
MPZ2012S221AT000 | L401,L402 | L0805 | C76818 | 2
RSCM7060-701 | L407 | FILTER-SMD_4P-L7.0-W6.0-P3.00-TL | C32712963 | 1
RT9080-33GJ5 | U603 | TSOT-23-5_L2.9-W1.6-P0.95-LS2.8-BL | C841192 | 1
SC7A20HTR | U406 | LGA-12_L2.0-W2.0-P0.50-TL | C19274408 | 1
SMAJ30A | D401 | SMA_L4.3-W2.6-LS5.2-RD | C10767 | 1
SMN-303 | Card401 | SIM-SMD_SMN-305 | C266890 | 1
TS-1088-AR02016 | SW603 | SW-SMD_L3.9-W3.0-P4.45 | C720477 | 1
TYPE-C 16PIN 2MD(073) | J201 | USB-C-SMD_TYPE-C-6PIN-2MD-073 | C2765186 | 1
USBLC6-2SC6_C2687116 | D212,D404,D405,D606 | SOT-23-6_L2.9-W1.6-P0.95-LS2.8-BL | C2687116 | 4
VLS3012HBX-1R0M | L201 | IND-SMD_L3.0-W3.0_VLS3012CX | C404493 | 1
WAFER-PH2.0-3PWB | J202 | CONN-SMD_3P-P2.00_XUNPU_WAFER-PH2.0-3PWB | C3029441 | 1
ZX-RF-1-Z21.25X | U401,U402 | IPEX-SMD_3P-L2.6-W2.6-LS3.0_YUANDI_RF-001 | C7426714 | 2

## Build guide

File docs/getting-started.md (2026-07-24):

# Getting started

## 1. Install the toolchain

1. Install [VS Code](https://code.visualstudio.com/).
2. Install the **PlatformIO IDE** extension (this project recommends it in
   `.vscode/extensions.json`; VS Code will offer to install it when you open the
   folder).
3. Open this folder (`communication-module`) in VS Code. PlatformIO will download the
   pinned `pioarduino` platform on first build - this takes a few minutes once.

You do **not** need the Arduino IDE or a separate ESP-IDF install.

## 2. Connect the board

- Plug into the **USB-C** connector. The ESP32-C6 exposes a **native USB Serial/JTAG**
  interface (GPIO12/13) - no external USB-UART adapter needed for flashing or the
  serial monitor.
- **Keep a charged battery connected** while flashing. USB-only power can brown the
  board out during flashing (see [errata](hardware-errata.md#-3-brownout-when-flashing-without-a-battery)).

## 3. Build & flash

There are two build targets (PlatformIO environments):

```bash
pio run -e functionality_test -t upload && pio device monitor   # board self-test
pio run -e datalogger -t upload && pio device monitor           # the main app
```

Or use the PlatformIO toolbar / project tasks in VS Code and pick the env.

On a fresh board, run `functionality_test` first: it probes every device (charger,
sensors, flash, modem, WiFi) and prints a `PASS / FAIL / SKIP` summary. Once that is
clean, flash `datalogger`.

## 4. Serial console notes (ESP32-C6 USB-CDC)

The C6 has only USB Serial/JTAG, so `Serial` is the USB CDC. Two consequences baked
into every example:

- `build_flags` set `-DARDUINO_USB_MODE=1` and `-DARDUINO_USB_CDC_ON_BOOT=1`.
- Each sketch does a `delay(1500)` at the top of `setup()` so the host has time to
  re-enumerate the CDC port after a reset - otherwise the first prints are lost.

If the monitor shows nothing after flashing, close and reopen `pio device monitor`
(the port re-enumerates on reset).

## 5. Recovery: forcing the ROM bootloader (BOOT pad)

If USB flashing ever fails (e.g. a sketch that reconfigures USB pins), force the
built-in ROM bootloader using the pads on the **back** of the board:

1. Hold **BOOT** (GPIO9 / pad TP403) low.
2. Pulse **RESET** (EN).
3. Release BOOT.
4. Flash normally.

## 6. Cellular / secrets

Anything that uses the modem needs your SIM's APN:

```bash
cp lib/EcoTrace/secrets.example.h lib/EcoTrace/secrets.h
# edit secrets.h -> set SIM_APN (and POST_URL if you want to test an upload)
```

`secrets.h` is gitignored so credentials never get committed.

## 7. Where to go next

- Log your own sensor: edit `readSample()` / `LogRecord` / `buildJson()` in
  [`src/datalogger/main.cpp`](../src/datalogger/main.cpp). It is a plain starting
  point - change whatever you need.
- Configure the logger: [`src/datalogger/config.h`](../src/datalogger/config.h)
  (sample interval, upload cadence, charge profile, MPPT bounds).
- Browse the available driver functions: [`api-reference.md`](api-reference.md).

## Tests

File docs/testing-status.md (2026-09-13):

# Testing status

What is proven on real hardware vs what is a new port that has not been run yet.
Read this before trusting any single feature.

## Bring-up campaign, 2026-08-06 / 07

Two units were taken through the full self-test: **unit A** `8C:FD:49:03:C4:10`
(clean board) and **unit B** `8C:FD:49:05:CA:AC` (the board behind repo issues
#4 and #5). Everything below was measured, not inferred.

**The whole board is now validated.** Every peripheral, both radios, both charge
inputs, the button, and deep sleep have run on real hardware. GPS remains the
only untested block (deliberately - see the errata).

| Verified | Detail |
|---|---|
| USB charging | fast-charge CC at the 500 mA SDP limit. The earlier "no charging" was a **cable with a broken VBUS wire** - the ~2.5 V seen on VUSB was phantom back-feed from the ESP's D+ through the D212 ESD array, not a sagging rail |
| Solar / VIN charging | outdoor test, panel Voc 6.72 V -> VBUS 6.09 V, fast-charge. The VINDPM mechanism the datalogger's MPPT depends on is proven |
| Input current limit | 799 mA drawn with the ILIM_HIZ pin limit *enabled*, so the ~600 mA clamp reported in issue #3 does not reproduce (0.8-2 A still untested) |
| Battery NTC / TS | unit B's mis-fitted resistor reworked; both units now read `TS: normal` |
| Modem UART ceiling | stock 10 k level-shifter pull-ups: 230400 clean, 460800 dead. After reworking **R405-R408 to 2.2 k** (unit B): **921600 clean** - the A7672's own maximum, since it rejects `AT+IPR=1843200`. ~90 KB/s, so a 1.2 MB OTA takes ~15 s |
| SPI flash | GD25Q128 (16 MB). Unit B's "dead" flash was **two unwetted lands under the ESP module** (IO8 = flash CS, IO18 = SCLK; IO9 between them fine) - the chip was healthy all along |
| QON button | short press wakes from deep sleep, 3 presses enter WiFi OTA mode, 3 s hold powers the board off via BQ ship mode, ~1 s hold powers it back on |
| MS5837-02BA barometer | on the I2C "hat" header: PROM CRC-4 valid, 967.8 mbar / 25.9 C / ~385 m ASL at Zurich |

### The one that cost the most time: `SFET_PRESENT`

BQ25792 ship mode, shutdown and system power reset **all silently do nothing**
unless `SFET_PRESENT` (REG14 bit 7) is set first to tell the charger an external
ship FET is fitted. The failure mode is deceptive: the I2C write is ACKed, every
other bit in the same register writes normally, and `SDRV_CTRL` simply reads back
0 with no error anywhere. Hours went into eliminating the watchdog, adapter
presence, the QON pin, the ADC, `EN_HIZ`, `REG_RST`, both delay settings and all
four field values before the bit was found (in the older `bq25792` Pico test
repo's register header). `BQ25792::enterShipMode()` and `systemPowerReset()` now
set it automatically.

### Diagnostics added to `functionality_test`

Built while chasing the faults above, and kept because they turn a vague failure
into a located one:

- **SPI**: MISO pull test (short vs open), `0xAB` deep-power-down wake before the
  JEDEC read, SI-SO loopback echo, header-jumper line-follow tests, GPIO
  pad-attachment sniffing, and an open-vs-clamped discriminator. Between them
  these distinguish a dead chip, a solder bridge, an open module land, and a
  chip merely asleep - none of which look different from "JEDEC = 0x000000".
- **Charger**: VAC1/VAC2 sense readings, an `EN_ACDRV1` read-back, an input
  qualification watch, the ILIM_HIZ probe, and a solar/MPPT sweep that measures
  panel Voc unloaded and then hill-climbs VINDPM to find the real maximum power
  point without knowing anything about the panel.
- **Modem**: a baud sweep that escalates 230400 -> 3686400 and always restores
  115200, so a level-shifter rework can be measured before and after. (Quirk: the
  first AT after `AT+IPR` always fails - send a throwaway command.)

### Per-unit build overrides

Unit B runs with a two-wire bypass for its open module lands - flash CS on GPIO1
(TP410 -> U602 pin 1) and SCLK on GPIO9 (header jumper CS<->SCLK):

```
pio run -e functionality_test -t upload \
    --build-flag="-DPIN_SPI_CS_FLASH=1 -DPIN_SPI_CLK=9"
```

Both pins default to the normal 8/18 for every other board.

## Proven on hardware

These have run on an actual ecoTrace Communication Module and worked. They were
validated in the two projects this repo is built from:

- **`functionality_test_arduino`** - the Arduino board self-test (the same code is in
  this repo as `functionality_test`).
- **`bms_stove`** - a full ESP-IDF datalogger deployed on this board.

Everything in the table below was re-confirmed during the 2026-08 campaign unless
noted otherwise.

| Capability | Proven | Where |
|---|:---:|---|
| QON button: wake / OTA mode / ship-mode power off | ✅ | `button_test`, 2026-08-07 |
| Solar input + VINDPM (MPPT) control | ✅ | `functionality_test`, 2026-08-07 |
| MS5837-02BA barometer on the I2C hat header | ✅ | `functionality_test`, 2026-08-07 |
| Board bring-up: I2C scan, device IDs on the bus | ✅ | functionality_test |
| BQ25792 read (VBAT/VBUS/IBAT, charge state, faults) | ✅ | functionality_test, bms_stove |
| USB charging | ✅ | bms_stove |
| Solar charging + software MPPT (VINDPM tracking) | ✅ | bms_stove |
| Cellular: modem power, SIM, registration, HTTP upload | ✅ | bms_stove, functionality_test |
| Deep sleep + timed wake, RTC-RAM persistence | ✅ | bms_stove |
| GPIO14 external sensor power switch | ✅ | confirmed on hardware |
| LTR-303 light + SC7A20 accelerometer read | ✅ | functionality_test |
| GD25Q128 external flash (JEDEC / read-write) | ✅ | functionality_test |
| ATECC608B secure element presence/wake | ✅ | functionality_test |

The **hardware and every technique above are known good.** The board works.

## NOT run on hardware yet (this repo's Arduino rewrite)

The `datalogger` app and the `lib/EcoTrace` driver library are a fresh Arduino
implementation of the proven techniques above. They compile cleanly for both build
environments but have **not been exercised on a board**.

| Item | Status | Note |
|---|---|---|
| `BQ25792` driver - charging | ⚠️ unrun | **Highest risk.** Uses the *correct* TI registers, which differ from the older (proven) code that charged via mislabelled ones. Charging as written here has never run. |
| `ModemA7672` driver - HTTP upload | ⚠️ unrun | Fresh Arduino AT port. The technique is proven (bms_stove uploaded), this exact re-implementation is not. |
| `datalogger` main loop | ✅ core proven 2026-08-07 | Wake/sample/sleep cycle, flash ring log (incl. recovery + backlog catch-up after a wrong-URL era), button wake/forced upload, and the ThingsBoard upload over WiFi all ran on unit A (`dl-2.9`). Still unproven: MPPT over a real solar day, weather/80 % switching, multi-day sleep budget. |
| WiFi backup uplink + SNTP | ✅ 2026-08-07 | Cellular failed gracefully ("no SIM / no network") -> WiFi fallback connected at -56 dBm and drained the backlog to eu.thingsboard.cloud. |
| Cellular upload (`ModemA7672` HTTP) | ✅ 2026-08-10 | **580 records drained over LTE in one session** (attach -65/-77 dBm) after a weekend offline in a basement -- the full store-and-forward design proven end-to-end. ThingsBoard Cloud intermittently answered 500 to the back-to-back burst; per-batch retry powered through, and `UPLOAD_BATCH_GAP_MS` pacing now avoids it. |
| WiFi OTA mode (3x button press) - **HTTP path** | ✅ 2026-08-07 | `curl -F "image=@firmware.bin" http://<ip>/update` on unit A over a PC mobile hotspot: upload, verify, ota_0 -> ota_1 slot switch and reboot all worked first try (reverse swap not yet exercised). No rollback: a broken pushed image means recovering over USB. |
| WiFi OTA mode - **espota/UDP path** (`datalogger_ota` env) | ❌ failed everywhere tried | espota's UDP invitation went unanswered in every tested configuration - across eth-iot (drops peer UDP), and even on a direct hotspot link with WiFi power-save disabled and ICMP+TCP healthy. Use the HTTP path. Bench findings: eth-iot passes ICMP between subnets but drops peer UDP; Windows mobile hotspot defaults to 5 GHz (C6 is 2.4-only) and auto-stops when no client connects; ESP modem power-save caused ~0.5 s RTT / 25 % loss until `WiFi.setSleep(false)`. |
| `LTR303` / `SC7A20` / `ExtFlash` / `ATECC608B` drivers | ⚠️ unrun | Thin re-ports of proven register sequences. Low risk, still unverified. |
| GPS (`ModemA7672::gps*`) | ❌ stub | Not implemented; GPS antenna path unvalidated on this board. |

`functionality_test` in this repo is a near-verbatim copy of the proven
`functionality_test_arduino` (hardcoded credentials were moved to `secrets.h`, and
the charge "nudge" was fixed to drive EN_ACDRV1 at REG13[6] -- the old copy wrote
the mislabelled REG12[3]/WKUP_DLY and gated on presence bits that stay 0 while
ACFET1 is off, so it never actually opened the USB input gate).

Update 2026-08-07: the **Rev A solar input path** (VAC2 -> ACFET2 -> VBUS, with
VINDPM control) was verified on hardware by `functionality_test`'s new solar/MPPT
sweep, outdoors with a real panel (Voc 6.7 V -> fast-charge CC from the panel). The
VINDPM mechanism the datalogger's `solar.cpp` MPPT relies on is therefore proven;
the datalogger code itself remains unrun.

## Bottom line

- **Flash `functionality_test` first** on any board - it is trusted and confirms the
  board is healthy.
- Treat the **`datalogger` as a working scaffold to validate**, not as known-good.
  When you first run it, watch the charge path: `chg_stat` should reach fast-charge
  and `IBAT` should go positive on USB/solar. Then confirm a record reaches your
  upload endpoint with a sane timestamp.
- See [`hardware-errata.md`](hardware-errata.md) for the physical gotchas (swapped VIN
  silk, NTC resistor rework, keep a battery connected when flashing).

---

## Ultrasonic link brought up, 2026-08-14/15

**The gas node works end to end.** The comm module reads the MSP430FR6043 over
I2C, logs a record and uploads it. Measured, not inferred:

| Capability | Proven | Evidence |
|---|:---:|---|
| I2C slave link, PROTO 2 | ✅ | `who_am_i 0x5A`, `proto 2`; 20/20 then 15/15 valid, CRC clean |
| Measurement over I2C, no UART | ✅ | `code=122`, 1301 ms mean / 1675 ms max vs a 3000 ms budget |
| Absolute ToF | ✅ | 131.3 us -> **335 m/s** on the 44 mm cell (air ~346) |
| Autonomous 1 Hz + totalizer | ✅ | `st=0x09 AUTO`, `vol_ml` accumulating |
| Slave watchdog (~3.2 s) | ✅ | 16 consecutive measurements, uptime monotonic, no spurious resets |
| All six I2C devices | ✅ | `sensor_ok=0x3F`; scan shows 7 incl. ATECC608 |
| Cellular upload with this payload | ✅ | "26 records sent, 0 pending" |

### Not proven / not calibrated

| Item | State |
|---|---|
| **Flow calibration (VFR constants)** | **Wrong for this cell.** `flow_lpm` reads several L/min at zero flow and `vol_ml` integrates it faithfully, so absolute volume is meaningless. Needs the lab DOE; no firmware change after. |
| Gas pressure | MS5837 is **not plumbed into the line yet** -- it reads ambient, so `dp_hpa` is not meaningful |
| Atmospheric pressure | a per-site **constant** (`P_ATM_CONST_HPA`), no sensor. Set before deployment: Nairobi at the Zurich value is ~18 % off |
| WF280A | **does not work.** Status byte 0x19 on every access = ADC powered off + test mode; a datasheet-correct trigger returns 6. Compensation polynomial is unpublished. Bosch part on the respin |
| GPS | still a stub |

### Bench gotchas for whoever picks this up

* **`USB_STAY_AWAKE` changes how the button is read.** With a cable attached
  the board never deep-sleeps, so `esp_sleep_get_wakeup_cause()` is stale and
  `board_woke_from_button()` can never be true -- a press is invisible no
  matter how the wake flags are handled. `main.c` therefore polls
  `board_button_pressed()` (QON level, active low) every 50 ms through the wait
  window and ends the wait early. On battery nothing changed: EXT1 still wakes
  the chip. Two separate bugs bit here on 2026-09-11 -- the flags were also
  being cleared before the code that reads them -- and fixing only the first
  left the button just as dead, so **test a press with the cable in AND out.**
* **The ultrasonic board needs a power cycle after flashing.** SBW flashing
  succeeds while the CPU never starts. On the node its rail comes from this
  board, so it only bites on the bench.
* **Its `/SDA` trace is broken between J2 and R22** and is currently **bodged
  J2.4 -> R22.1**. Do not remove that wire. The layout routes `/SDA` through
  U8's pad, so one unwetted LGA land cuts the whole bus.
* **Feed its `/VCC` from VSYS, not 3V3** -- its onboard XC6206 needs headroom;
  3.3 V in leaves it in dropout.
* The USB CDC takes several seconds to enumerate after a wake, so a console
  attached mid-cycle misses the sampling logs entirely. A `USS recap` line is
  emitted just before deep sleep for exactly this reason.

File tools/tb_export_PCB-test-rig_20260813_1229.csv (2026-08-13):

ts_ms | ts_utc | key | value
1786509098000 | 2026-08-12 04:31:38 | solar | 0
1786509399000 | 2026-08-12 04:36:39 | solar | 0
1786509700000 | 2026-08-12 04:41:40 | solar | 0
1786510001000 | 2026-08-12 04:46:41 | solar | 0
1786510302000 | 2026-08-12 04:51:42 | solar | 0
1786510603000 | 2026-08-12 04:56:43 | solar | 0
1786511240000 | 2026-08-12 05:07:20 | solar | 0
1786511541000 | 2026-08-12 05:12:21 | solar | 0
1786511842000 | 2026-08-12 05:17:22 | solar | 0
1786512143000 | 2026-08-12 05:22:23 | solar | 0
1786512444000 | 2026-08-12 05:27:24 | solar | 0
1786512745000 | 2026-08-12 05:32:25 | solar | 0
1786513046000 | 2026-08-12 05:37:26 | solar | 0
1786513347000 | 2026-08-12 05:42:27 | solar | 0
1786513648000 | 2026-08-12 05:47:28 | solar | 0
1786513948000 | 2026-08-12 05:52:28 | solar | 0
1786514249000 | 2026-08-12 05:57:29 | solar | 0
1786514550000 | 2026-08-12 06:02:30 | solar | 0
1786514851000 | 2026-08-12 06:07:31 | solar | 0
1786515152000 | 2026-08-12 06:12:32 | solar | 0
1786515453000 | 2026-08-12 06:17:33 | solar | 0
1786515754000 | 2026-08-12 06:22:34 | solar | 0
1786516055000 | 2026-08-12 06:27:35 | solar | 0
1786516356000 | 2026-08-12 06:32:36 | solar | 0
1786516657000 | 2026-08-12 06:37:37 | solar | 0
1786516958000 | 2026-08-12 06:42:38 | solar | 0
1786517259000 | 2026-08-12 06:47:39 | solar | 0
1786517560000 | 2026-08-12 06:52:40 | solar | 0
1786517860000 | 2026-08-12 06:57:40 | solar | 0
1786518161000 | 2026-08-12 07:02:41 | solar | 0
1786518462000 | 2026-08-12 07:07:42 | solar | 0
1786518763000 | 2026-08-12 07:12:43 | solar | 0
1786519064000 | 2026-08-12 07:17:44 | solar | 0
1786519365000 | 2026-08-12 07:22:45 | solar | 0
1786519666000 | 2026-08-12 07:27:46 | solar | 0
1786519967000 | 2026-08-12 07:32:47 | solar | 0
1786520268000 | 2026-08-12 07:37:48 | solar | 0
1786520569000 | 2026-08-12 07:42:49 | solar | 0
1786520870000 | 2026-08-12 07:47:50 | solar | 0
1786521171000 | 2026-08-12 07:52:51 | solar | 0
1786521472000 | 2026-08-12 07:57:52 | solar | 0
1786521772000 | 2026-08-12 08:02:52 | solar | 0
1786522073000 | 2026-08-12 08:07:53 | solar | 0
1786522374000 | 2026-08-12 08:12:54 | solar | 0
1786522675000 | 2026-08-12 08:17:55 | solar | 0
1786522976000 | 2026-08-12 08:22:56 | solar | 0
1786523277000 | 2026-08-12 08:27:57 | solar | 0
1786523578000 | 2026-08-12 08:32:58 | solar | 0
1786523879000 | 2026-08-12 08:37:59 | solar | 0
1786524180000 | 2026-08-12 08:43:00 | solar | 0
1786524481000 | 2026-08-12 08:48:01 | solar | 0
1786524782000 | 2026-08-12 08:53:02 | solar | 0
1786524860000 | 2026-08-12 08:54:20 | solar | 0
1786525289000 | 2026-08-12 09:01:29 | solar | 0
1786525590000 | 2026-08-12 09:06:30 | solar | 0
1786525891000 | 2026-08-12 09:11:31 | solar | 0
1786526192000 | 2026-08-12 09:16:32 | solar | 0
1786526493000 | 2026-08-12 09:21:33 | solar | 0
1786526794000 | 2026-08-12 09:26:34 | solar | 0
1786527095000 | 2026-08-12 09:31:35 | solar | 0
1786527396000 | 2026-08-12 09:36:36 | solar | 0
1786527697000 | 2026-08-12 09:41:37 | solar | 0
1786527999000 | 2026-08-12 09:46:39 | solar | 1
1786528300000 | 2026-08-12 09:51:40 | solar | 1
1786528602000 | 2026-08-12 09:56:42 | solar | 1
1786528904000 | 2026-08-12 10:01:44 | solar | 1
1786529206000 | 2026-08-12 10:06:46 | solar | 1
1786529508000 | 2026-08-12 10:11:48 | solar | 1
1786529810000 | 2026-08-12 10:16:50 | solar | 1
1786530112000 | 2026-08-12 10:21:52 | solar | 1
1786530414000 | 2026-08-12 10:26:54 | solar | 1
1786530716000 | 2026-08-12 10:31:56 | solar | 1
1786531018000 | 2026-08-12 10:36:58 | solar | 1
1786531320000 | 2026-08-12 10:42:00 | solar | 1
1786531622000 | 2026-08-12 10:47:02 | solar | 1
1786531924000 | 2026-08-12 10:52:04 | solar | 1
1786532226000 | 2026-08-12 10:57:06 | solar | 1
1786532528000 | 2026-08-12 11:02:08 | solar | 1
1786532829000 | 2026-08-12 11:07:09 | solar | 1
1786533131000 | 2026-08-12 11:12:11 | solar | 1
1786533433000 | 2026-08-12 11:17:13 | solar | 1
1786533735000 | 2026-08-12 11:22:15 | solar | 1
1786534037000 | 2026-08-12 11:27:17 | solar | 1
1786534338000 | 2026-08-12 11:32:18 | solar | 1
1786534640000 | 2026-08-12 11:37:20 | solar | 1
1786534942000 | 2026-08-12 11:42:22 | solar | 1
1786535243000 | 2026-08-12 11:47:23 | solar | 1
1786535545000 | 2026-08-12 11:52:25 | solar | 1
1786535846000 | 2026-08-12 11:57:26 | solar | 1
1786536148000 | 2026-08-12 12:02:28 | solar | 1
1786536449000 | 2026-08-12 12:07:29 | solar | 1
1786536751000 | 2026-08-12 12:12:31 | solar | 1
1786537052000 | 2026-08-12 12:17:32 | solar | 1
1786537354000 | 2026-08-12 12:22:34 | solar | 1
1786537656000 | 2026-08-12 12:27:36 | solar | 1
1786537958000 | 2026-08-12 12:32:38 | solar | 1
1786538260000 | 2026-08-12 12:37:40 | solar | 1
1786538562000 | 2026-08-12 12:42:42 | solar | 1
1786538864000 | 2026-08-12 12:47:44 | solar | 1
1786539166000 | 2026-08-12 12:52:46 | solar | 1
1786539468000 | 2026-08-12 12:57:48 | solar | 1
1786539770000 | 2026-08-12 13:02:50 | solar | 1
1786540072000 | 2026-08-12 13:07:52 | solar | 1
1786540374000 | 2026-08-12 13:12:54 | solar | 1
1786540676000 | 2026-08-12 13:17:56 | solar | 1
1786540978000 | 2026-08-12 13:22:58 | solar | 1
1786541280000 | 2026-08-12 13:28:00 | solar | 1
1786541582000 | 2026-08-12 13:33:02 | solar | 1
1786541884000 | 2026-08-12 13:38:04 | solar | 1
1786542186000 | 2026-08-12 13:43:06 | solar | 1
1786542488000 | 2026-08-12 13:48:08 | solar | 1
1786542790000 | 2026-08-12 13:53:10 | solar | 1
1786543092000 | 2026-08-12 13:58:12 | solar | 1
1786543393000 | 2026-08-12 14:03:13 | solar | 1
1786543695000 | 2026-08-12 14:08:15 | solar | 1
1786543997000 | 2026-08-12 14:13:17 | solar | 1
1786544299000 | 2026-08-12 14:18:19 | solar | 1
1786544601000 | 2026-08-12 14:23:21 | solar | 1
1786544903000 | 2026-08-12 14:28:23 | solar | 1
1786545205000 | 2026-08-12 14:33:25 | solar | 1
1786545507000 | 2026-08-12 14:38:27 | solar | 1
1786545809000 | 2026-08-12 14:43:29 | solar | 1
1786546111000 | 2026-08-12 14:48:31 | solar | 1
1786546413000 | 2026-08-12 14:53:33 | solar | 1
1786546715000 | 2026-08-12 14:58:35 | solar | 1
1786547017000 | 2026-08-12 15:03:37 | solar | 1
1786547319000 | 2026-08-12 15:08:39 | solar | 1
1786547621000 | 2026-08-12 15:13:41 | solar | 1
1786547923000 | 2026-08-12 15:18:43 | solar | 1
1786548225000 | 2026-08-12 15:23:45 | solar | 1
1786548527000 | 2026-08-12 15:28:47 | solar | 1
1786548829000 | 2026-08-12 15:33:49 | solar | 1
1786549131000 | 2026-08-12 15:38:51 | solar | 1
1786549433000 | 2026-08-12 15:43:53 | solar | 1
1786549734000 | 2026-08-12 15:48:54 | solar | 1
1786550036000 | 2026-08-12 15:53:56 | solar | 1
1786550338000 | 2026-08-12 15:58:58 | solar | 1
1786550640000 | 2026-08-12 16:04:00 | solar | 1
1786550942000 | 2026-08-12 16:09:02 | solar | 1
1786551244000 | 2026-08-12 16:14:04 | solar | 1
1786551546000 | 2026-08-12 16:19:06 | solar | 1
1786551848000 | 2026-08-12 16:24:08 | solar | 1
1786552150000 | 2026-08-12 16:29:10 | solar | 1
1786552452000 | 2026-08-12 16:34:12 | solar | 1
1786552754000 | 2026-08-12 16:39:14 | solar | 1
1786553056000 | 2026-08-12 16:44:16 | solar | 1
1786553358000 | 2026-08-12 16:49:18 | solar | 1
1786553660000 | 2026-08-12 16:54:20 | solar | 1
1786553962000 | 2026-08-12 16:59:22 | solar | 1
1786554264000 | 2026-08-12 17:04:24 | solar | 1
1786554566000 | 2026-08-12 17:09:26 | solar | 1
1786554868000 | 2026-08-12 17:14:28 | solar | 1
1786555170000 | 2026-08-12 17:19:30 | solar | 1
1786555472000 | 2026-08-12 17:24:32 | solar | 1
1786555774000 | 2026-08-12 17:29:34 | solar | 1
1786556076000 | 2026-08-12 17:34:36 | solar | 1
1786556377000 | 2026-08-12 17:39:37 | solar | 1
1786556679000 | 2026-08-12 17:44:39 | solar | 1
1786556981000 | 2026-08-12 17:49:41 | solar | 1
1786557283000 | 2026-08-12 17:54:43 | solar | 1
1786557585000 | 2026-08-12 17:59:45 | solar | 1
1786557887000 | 2026-08-12 18:04:47 | solar | 1
1786558189000 | 2026-08-12 18:09:49 | solar | 1
1786558490000 | 2026-08-12 18:14:50 | solar | 0
1786558791000 | 2026-08-12 18:19:51 | solar | 0
1786559091000 | 2026-08-12 18:24:51 | solar | 0
1786559392000 | 2026-08-12 18:29:52 | solar | 0
1786559693000 | 2026-08-12 18:34:53 | solar | 0
1786559994000 | 2026-08-12 18:39:54 | solar | 0
1786560295000 | 2026-08-12 18:44:55 | solar | 0
1786560596000 | 2026-08-12 18:49:56 | solar | 0
1786560897000 | 2026-08-12 18:54:57 | solar | 0
1786561198000 | 2026-08-12 18:59:58 | solar | 0
1786561499000 | 2026-08-12 19:04:59 | solar | 0
1786561800000 | 2026-08-12 19:10:00 | solar | 0
1786562101000 | 2026-08-12 19:15:01 | solar | 0
1786562402000 | 2026-08-12 19:20:02 | solar | 0
1786562703000 | 2026-08-12 19:25:03 | solar | 0
1786563004000 | 2026-08-12 19:30:04 | solar | 0
1786563304000 | 2026-08-12 19:35:04 | solar | 0
1786563605000 | 2026-08-12 19:40:05 | solar | 0
1786563906000 | 2026-08-12 19:45:06 | solar | 0
1786564207000 | 2026-08-12 19:50:07 | solar | 0
1786564508000 | 2026-08-12 19:55:08 | solar | 0
1786564809000 | 2026-08-12 20:00:09 | solar | 0
1786565110000 | 2026-08-12 20:05:10 | solar | 0
1786565411000 | 2026-08-12 20:10:11 | solar | 0
1786565712000 | 2026-08-12 20:15:12 | solar | 0
1786566013000 | 2026-08-12 20:20:13 | solar | 0
1786566314000 | 2026-08-12 20:25:14 | solar | 0
1786566615000 | 2026-08-12 20:30:15 | solar | 0
1786566916000 | 2026-08-12 20:35:16 | solar | 0
1786567216000 | 2026-08-12 20:40:16 | solar | 0
1786567517000 | 2026-08-12 20:45:17 | solar | 0
1786567818000 | 2026-08-12 20:50:18 | solar | 0
1786568119000 | 2026-08-12 20:55:19 | solar | 0
1786568420000 | 2026-08-12 21:00:20 | solar | 0
1786568862000 | 2026-08-12 21:07:42 | solar | 0
1786569163000 | 2026-08-12 21:12:43 | solar | 0
1786569464000 | 2026-08-12 21:17:44 | solar | 0
1786569764000 | 2026-08-12 21:22:44 | solar | 0
1786570065000 | 2026-08-12 21:27:45 | solar | 0
1786570366000 | 2026-08-12 21:32:46 | solar | 0
1786570667000 | 2026-08-12 21:37:47 | solar | 0
1786570968000 | 2026-08-12 21:42:48 | solar | 0
1786571269000 | 2026-08-12 21:47:49 | solar | 0
1786571570000 | 2026-08-12 21:52:50 | solar | 0
1786571871000 | 2026-08-12 21:57:51 | solar | 0
1786572172000 | 2026-08-12 22:02:52 | solar | 0
1786572473000 | 2026-08-12 22:07:53 | solar | 0
1786572774000 | 2026-08-12 22:12:54 | solar | 0
1786573075000 | 2026-08-12 22:17:55 | solar | 0
1786573376000 | 2026-08-12 22:22:56 | solar | 0
1786573676000 | 2026-08-12 22:27:56 | solar | 0
1786573977000 | 2026-08-12 22:32:57 | solar | 0
1786574278000 | 2026-08-12 22:37:58 | solar | 0
1786574579000 | 2026-08-12 22:42:59 | solar | 0
1786574880000 | 2026-08-12 22:48:00 | solar | 0
1786575181000 | 2026-08-12 22:53:01 | solar | 0
1786575482000 | 2026-08-12 22:58:02 | solar | 0
1786575783000 | 2026-08-12 23:03:03 | solar | 0
1786576084000 | 2026-08-12 23:08:04 | solar | 0
1786576385000 | 2026-08-12 23:13:05 | solar | 0
1786576686000 | 2026-08-12 23:18:06 | solar | 0
1786576987000 | 2026-08-12 23:23:07 | solar | 0
1786577288000 | 2026-08-12 23:28:08 | solar | 0
1786577588000 | 2026-08-12 23:33:08 | solar | 0
1786577889000 | 2026-08-12 23:38:09 | solar | 0
1786578190000 | 2026-08-12 23:43:10 | solar | 0
1786578491000 | 2026-08-12 23:48:11 | solar | 0
1786578792000 | 2026-08-12 23:53:12 | solar | 0
1786579093000 | 2026-08-12 23:58:13 | solar | 0
1786579394000 | 2026-08-13 00:03:14 | solar | 0
1786579695000 | 2026-08-13 00:08:15 | solar | 0
1786579996000 | 2026-08-13 00:13:16 | solar | 0
1786580297000 | 2026-08-13 00:18:17 | solar | 0
1786580598000 | 2026-08-13 00:23:18 | solar | 0
1786580899000 | 2026-08-13 00:28:19 | solar | 0
1786581200000 | 2026-08-13 00:33:20 | solar | 0
1786581500000 | 2026-08-13 00:38:20 | solar | 0
1786581801000 | 2026-08-13 00:43:21 | solar | 0
1786582102000 | 2026-08-13 00:48:22 | solar | 0
1786582403000 | 2026-08-13 00:53:23 | solar | 0
1786582704000 | 2026-08-13 00:58:24 | solar | 0
1786583005000 | 2026-08-13 01:03:25 | solar | 0
1786583306000 | 2026-08-13 01:08:26 | solar | 0
1786583607000 | 2026-08-13 01:13:27 | solar | 0
1786583908000 | 2026-08-13 01:18:28 | solar | 0
1786584209000 | 2026-08-13 01:23:29 | solar | 0
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

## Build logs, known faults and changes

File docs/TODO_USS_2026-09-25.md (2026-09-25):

# TODO: bring the 2026-09-25 USS work onto the comm board

The ultrasonic module (USS), the uss-link library and the bench streamer changed on
2026-09-25. The comm board firmware (`idf/`) has not been touched yet, apart from the
`uss_link.h` copy. This file lists what to do, in order. Background, measurements and bench
procedure: `Calibration-data-collection/calibration/USS.md`.

## What changed on the other side (read first)

| Where | Change | Effect on the comm board |
|---|---|---|
| module firmware | **ONE gas image for every cell** (`6a0290ff`). Capture window and ToF gate limits are **per cell and set by the ESP32 over I2C**; image defaults (window 110 µs = `gap_adcsmp` 1550, gate 80–320 µs) work on the 44 mm and the 75 mm cell until configured. On the 75 mm cell the window must be set to 140 µs (`gap_adcsmp` 1700): the zero then no longer depends on composition (±4 ns from 10 to 90 % CH4, was 5–54 ns). | **push the cell's window and gate at every module boot** (task 5b). Offsets measured before this are obsolete. |
| module firmware | gain fallback never goes below 25 | nothing to do |
| module firmware | **abs-ToF gate**: a capture with an implausible time of flight is rejected with **code 0xE1 (`USS_CODE_TOF_HOP`)**, counted as skipped in the raw totalizer, and triggers a re-search | it is a non-122 code, so the current driver already treats it as invalid. Up to 4 are expected after every module boot. |
| module firmware | **parameter access over I2C**: registers `0x44` (id), `0x45` (i32 value), commands `USS_CMD_PARAM_SET` 0x06 / `USS_CMD_PARAM_GET` 0x07, result block `0x68..0x6F` with its own CRC. **New since the first version of this file: `USS_PARAM_TOFG_MIN_NS` 0x41 / `USS_PARAM_TOFG_MAX_NS` 0x42** (ns, FRAM, SET range 20000–2000000, min < max). | additive, PROTO stays 3. Add the two gate ids to the preset sync (task 5b). |
| `uss_link.h` | all of the above | **already copied** into `idf/src/uss_link.h`; all three copies are byte-identical (MD5 `1f30b1de…`, LF line endings). Keep them in sync. |
| uss-link | `uss_param_get/set()`, and **`uss_derive.c/h`**: composition, gas properties, Re, K(Re, x), zero, low-flow cutoff, standard volumes, gas profiles | this is what the comm board should report (tasks 2–4) |

**Module settings persist in FRAM** across power cycles until the next flash. A module that
was tuned on the bench keeps those values. Read them back (`USS_CMD_PARAM_GET`) before
trusting a unit in the field.

## Tasks

### 1. Build check (do first; ~10 min)
- [x] Build `datalogger_idf` from `idf/` with the new `uss_link.h`. It is purely additive, so
      nothing should break. Watch for name clashes with the new `USS_PARAM_*` / `USS_PRM_*` macros.
      *Done 2026-09-25: builds clean (RAM 16.1 %, flash 62.4 %); the new macro names appear
      nowhere else in `idf/src`.*
- [x] Confirm `main.c`'s USS block handles `code == 0xE1` exactly like any non-122 code:
      no flow, the sample is kept, and it is logged.
      *Done 2026-09-25: nothing on the device branches on the code value. `uss_ok` is only
      "CRC-valid block read", so a 0xE1 sample is stored and `uss_code` is logged and uplinked.
      The module leaves it out of S1/S0. Note: its ToF/dTOF fields still go into the record and
      the JSON unfiltered, so anything downstream (server, and `uss_derive` in task 3) must gate
      on `uss_code == 122`.*

### 2. Decide: port to uss-link, or copy only the derivation
**Decided 2026-09-25: neither. The comm board stays separate from uss-link.** It keeps its own
driver (`idf/src/uss.c`, now with `uss_param_get/set`) and its own derivation
(`idf/src/gasflow.c/h`), written for the comm board. The constants and physics must stay
numerically identical to `uss_derive.c`; `tools/gasflow_check.c` checks that on the host
(2.8 M comparisons, worst relative difference 3.5e-16). **Refit one, refit both, bump
`GF_DERIVE_VER`, rerun the check.** uss-link's ESP-IDF port was not used: it caches its own
I2C handle, which `eco_i2c_hold_low()` (the rail-cycle recovery) would delete under it.

The original options, for reference:
The comm board has its **own** `idf/src/uss.c/.h`, a separate driver from `uss-link/src/uss.c`
with a different struct (`uss_sample_t`-style vs `uss_result_t`).
- **Option A (recommended): use uss-link as the ESP-IDF component** (its `CMakeLists.txt`
  already lists `uss.c uss_derive.c uss_port_espidf.c`) and delete the local driver. One
  driver, one place to fix bugs. Cost: re-verify retry/timeout behaviour on the real bus
  (clock stretching; `USS_XFER_TIMEOUT_MS` 1000), and the STALE-seq detection in `main.c`
  must keep working.
- **Option B: copy `uss_derive.c/h` only** and write a small adapter that fills a
  `uss_result_t` from the local struct (fields used: `code, tof_ups_q40, tof_dns_q40,
  dtof_ps, amp_ups, amp_dns`). Quicker, but it leaves two drivers drifting.

### 3. Derived values per record, WITHOUT changing the record layout
The record already holds every raw input: `uss_s1`, `uss_s0`, `uss_tot_skip`,
`uss_tof_ups_q40`, `uss_tof_dns_q40`, `uss_dtof_ps`, `uss_amp_*`, `press_dmbar`, `temp_cC`.
The MS5837 sits **in the gas line** (`config.h`), which is what the derivation needs.
- [x] In `uplink.c`, when building the JSON: `gf_sample()` from the record's sample
      fields plus `press_dmbar / 10` and `temp_cC / 100`, then `gf_window()` on
      `dS1 = s1 − prev.s1`, `dS0 = s0 − prev.s0`, `dt` = time between the two records.
- [x] The predecessor is **read back from the flash ring by seq** (`flashlog_read_seq`), not kept
      in RAM, so it survives deep sleep and reboots. No predecessor → no window
      (`uss_win_err: "no_prev"`), never zero.
- [x] Window rejected (with `uss_win_err`) on SAT, `dS0 <= 0` (includes a reset and pre-PROTO 3
      records), no usable dt, no valid sample at either end, **coverage** > 1.25, or mean
      |q| > 60 SL/min. Coverage is `dS0 · tu · td / 2^40 / dt`: the time S0 claims was
      integrated, over the wall clock. It stands in for "fits the number of captures", because the
      record has no TOT_N. Field median 0.990 (eco-field-02, 2026-09-23); not judged under 60 s.
- [x] `REC_MAGIC` unchanged (ECL6). A backlog logged before this build still gets derived values.
- [x] Raw keys unchanged and still sent.
- [x] Found and fixed along the way: when a batch overflowed the JSON buffer, `drain()` still
      advanced by the full batch, so records that did not fit were marked sent without ever
      leaving the board. Buffer is now 16 KB and the advance counts only what was sent.

Telemetry keys as implemented (per record, when the module answered):

| Key | Meaning |
|---|---|
| `uss_gas` | profile name (`biogas`, `air`, `air_co2`, `n2`) |
| `uss_c_mps` | speed of sound |
| `uss_x_a` | fraction of the profile's first component (**CH4 for biogas**) |
| `uss_q_std_lpm` | window-mean flow, standard L/min (20 °C / 1013.25 mbar), after the cutoff |
| `uss_v_std_l`, `uss_v_a_std_l` | window volume, total and first component (CH4) |
| `uss_re` | Reynolds number of the window |
| `uss_tof_bad` | the host judged the ToF impossible for the selected gas |
| `uss_cut` | the window was below the low-flow cutoff |
| `uss_derive_ver` | which constant set produced these numbers (bump on every refit) |
| `uss_validated` | the profile's constants were validated (biogas, air) |
| `uss_not_gas` | echo > 2× what this gas gives at this c (e.g. air in a biogas line); CH4 volume forced to 0. Replaces the proposed `uss_not_biogas`. |
| `uss_cov` | window coverage, see above (~1 when the module measured the whole window) |
| `uss_win_s` | window length, s |
| `uss_win_err` | why there is no window: `no_prev`, `no_module`, `saturated`, `ds0`, `no_dt`, `no_sample`, `coverage`, `window`, `q_max` |

Status record: `uss_preset` (-1 not tried this module boot, 0 failed, 1 in place).

### 4. Retire the legacy path
- [x] Removed the `K_est` diagnostic and its RTC state from `main.c`.
- [x] `uss_vol_ml` is still sent (the server reads it) and is commented as legacy in `uplink.c`.
      `uss_flow_ulpm` was already not uplinked.

### 5. Gas profile on the comm board
- [ ] NVS key `uss_gas` (default `biogas`), settable remotely (downlink / config message).
      **Blocked: the board has no downlink at all yet** (MQTT publish only). For now the profile
      is compile-time: `USS_GAS_PROFILE` in `config.h`.
- [x] Module preset synced once per module boot (`USS_ST_BOOT`, latched in `uss.c` because
      `uss_start_auto`'s command clears it) and after a cold boot of the comm board. GET first,
      SET only what differs, each SET verified by read-back. With biogas on a freshly flashed
      module this writes nothing. Tried once per module boot even on failure, so an old module
      without PARAM costs one 3 s timeout, not one per wake. *Not yet run on hardware.*
- [x] `uss_validated` reported in telemetry.
- [x] **Detect "not biogas"** (`uss_not_gas`): air reads as ~61 % CH4 by speed of sound
      alone. Use the echo amplitude (raw counts, `AMP_UPS/DNS`), normalised to gain 25: more
      than 2× the biogas amplitude for that speed of sound means not biogas (air ~1050 counts
      vs biogas 210–460 at gain 25). Publish a `uss_not_biogas` flag. Table and rule:
      `Calibration-data-collection/calibration/USS.md`, "Is it biogas at all?".

### 5b. Gas cell (NEW, 2026-09-25 evening)
The module no longer knows its cell; the ESP32 tells it. uss-link reference implementation:
`uss_cell_t`, `uss_derive_profile_cell(&cfg, gas, cell)`, and `uss_module_preset_t` gained
`tofg_min_ns` / `tofg_max_ns`, written by `uss_apply_module_preset()`.
*Done 2026-09-25 in idf-0.30 (first three items). eco-field-02 (COM125) is on the 44 mm cell and
is built with `USS_CELL GF_CELL_44`. The preset sync also re-runs when the cell, gas or
`GF_DERIVE_VER` changes (RTC key): idf-0.29 had possibly pushed the 75 mm window (1700) into
that module, and a reflash alone does not guarantee a cold boot. Server handoff:
`ecotrace-server/docs/CHANGES_FIRMWARE_idf-0.30.md`.*
- [x] **Mirror the cell in `gasflow.c`** (it carries these per cell, not per gas):

      | | 75 mm (validated) | 44 mm (NOT calibrated, starting point) |
      |---|---|---|
      | `path_m` | 0.07220 | 0.0440 |
      | `t0_us` | 1.2 | 1.2 |
      | K (`k_a`, `k_b`, `k_c`) | as fitted | × 44/72.2 (assumes the same 15.5 mm bore) |
      | `gap_adcsmp` | 1700 | 1550 |
      | ToF gate (ns) | 140000–320000 | 80000–200000 |
      | not-biogas amplitude check | on | **off** (`amp_ref_n = 0`): shorter path, stronger echo |
      | `validated` | per gas | 0 |

      Then rerun `tools/gasflow_check.c` against the new `uss_derive.c` and bump `GF_DERIVE_VER`.
      *Both cells × 4 gases: 5.6 M comparisons, 0 mismatches. `GF_DERIVE_VER` = 2.*
- [x] **Add the gate to the preset sync** (ids 0x41/0x42). Order matters: the module refuses a
      min ≥ current max, so widen first: SET max to 2000000, then min, then max
      (uss-link does exactly this).
- [x] Cell selection: compile-time `USS_CELL` in `config.h` next to `USS_GAS_PROFILE` (no
      downlink yet), later an NVS key `uss_cell`. Report it: telemetry key `uss_cell` (`44`/`75`).
- [ ] **Calibrate the 44 mm cell** before trusting its derived values: one air point (the
      acoustic temperature gives the real path L; the old 131.3 µs air reading implies ~1.7 %
      longer than 44 mm), a zero, a few flow points for K, and its own amplitude table. Expect a
      composition-dependent zero on this cell: its echo sits inside the transmit tail.

### 6. Per-unit constants, OTA-updatable
- [ ] Move the calibration constants into NVS with the compiled defaults as fallback:
      `k_a, k_b, k_c`, `off_a_ps`, `q_cutoff_lpm`, `path_m`, `t0_us`, `pipe_d_m`.
      Per unit, settable remotely.
- [ ] The low-flow cutoff (default 0.5 SL/min) applies to **derived** values only. Make sure
      nothing on the device cuts the raw sums.

### 7. Things the field will do that the bench did not
- [ ] **Water vapour.** Field biogas is saturated. At 35 °C ~5.6 % H2O shifts the CH4 reading
      by ~3–4 %. At least add a "saturated at T" option, or a humidity input if a sensor exists.
- [ ] **Temperature gradients** (sun on the pipe) moved the zero by 10–25 ns on the bench
      (2026-09-24 "hotgrad"), which is ~0.15–0.35 L/min. Log the gas temperature with every
      record; flag windows where the MS5837 temperature changes fast.
- [x] ~~The module's hard ToF limits~~: now I2C parameters, set per cell (task 5b).

### ✓ Answered: eco-field-02 (device 4) ToF
Its abs ToF of 132.5–133.0 µs (2026-09-23/24) is the **44 mm cell**, not the 75 mm one: air
reads ~131 µs there, and 132.5 µs is roughly 55–60 % CH4 with the nominal 44 mm path. The
`uss_tof_bad` flags came from applying 75 mm constants. Fix = task 5b (cell 44). The module on
the comm-board unit was flashed on 2026-09-25 with the standard image `6a0290ff`, whose
defaults (window 110 µs, gate 80–320 µs) work on this cell without any configuration.

### 8. Verify
- [x] Host equivalence check, from `tools/`:
      `gcc -std=c99 -O2 -Wall -Wextra -I../../uss-link/include -I../idf/src gasflow_check.c
      ../idf/src/gasflow.c ../../uss-link/src/uss_derive.c -lm -o gasflow_check && ./gasflow_check`
      → 0 mismatches (2026-09-25).
- [x] `datalogger_idf` builds clean (idf-0.29, RAM 18.0 %, flash 63.2 %).
- [ ] Bench: comm board + module on the MFC rig, one composition, 2/5/8 SL/min, ≥ 5 min per
      point. Compare `uss_v_std_l` per record against MFC-integrated standard litres. The
      expected agreement is a few %: 1.5 % rms in-sample on 2026-09-25, not yet validated
      out of sample.
- [ ] Soak at zero flow for ≥ 1 h: `uss_v_std_l` must stay 0 (cutoff), and `uss_skip`
      must not grow in steady gas (no 0xE1 after boot).

## Traps (from `uss-link/CLAUDE.md`, still valid)
- Build from `idf/`, not the repo root (different `platformio.ini`).
- ESP32 **automatic light sleep stays off** (it caused module reboots and code 135).
- **Flash order: host first, then the module**, whenever the contract changes. This change
  is additive, so either order works this time.
- `uss_link.h` exists in three copies: change all three together.
- Nothing is committed on 2026-09-25 by the assistant; the user does all commits.
- **Module image:** there is ONE gas image (`Firmware/tools/build.sh`, `BOARD=PCB I2CSLAVE=1`, LPM3 by
  default). Never flash a cell-specific build; there is no such thing any more. Flash only from WSL
  (MSP430Flasher), never with Windows TI tools.

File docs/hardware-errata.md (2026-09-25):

# Hardware errata & gotchas - ecoTrace Communication Module Rev A (2026-04-23)

Read this before wiring or deploying. These are known issues on the current boards.

## 🔴 1. VIN +/- silkscreen is SWAPPED

The `+` and `-` labels next to the **VIN** screw terminal (top of the board) are
**reversed**. The terminal that is silk-labelled `+` is actually the negative, and
vice versa. This is on purpose noted very visibly because it is easy to get wrong.

**Action:** ignore the silkscreen. Verify polarity against the schematic / with a
meter before connecting a panel or DC source. Reversed input can damage the board.

## 🔴 2. Battery NTC (TS) input - wrong resistor value as shipped

The boards were populated with an **incorrect resistor value at the battery NTC (TS)
input** of the BQ25792. Left unfixed, the charger may misread battery temperature and
refuse to charge / report false TS_COLD/TS_HOT faults.

**Action:** this should be **fixed (reworked) on all boards** before use. Confirm the
rework was done on your unit. If charging never starts and the BQ reports TS faults,
suspect this first.

## 🟠 3. Brownout when flashing without a battery

Flashing / heavy activity **without a battery connected** (USB only) can brown the
board out - not thoroughly characterised yet. The USB input alone may not hold VSYS
under inrush.

**Action:** keep a charged battery connected while flashing and during first bring-up.
If you see boot loops or resets only on USB-only power, this is the likely cause.

## 🔴 4. No GPS: the fitted A7672E-LASE has no GNSS engine

**Tested 2026-09-25** (bench firmware `idf` env `gnsstest`, `src/gnss_bench.c`, active
ceramic patch antenna with a view of the sky). The module identifies as
`Model: A7672E-LASE`, `Revision: A011B18A7672M7`. **Every GNSS AT command returns
`ERROR`**, also after the modem had fully booted (`+CPIN: READY`, `SMS DONE`,
`PB DONE`): `AT+CGNSSPWR?`, `AT+CGNSSPWR=1`, `AT+CGNSSPORTSWITCH=0,1`,
`AT+CGNSSTST=1`, `AT+CGPSCOLD`. No `+CGNSSPWR: READY!` in 60 s, no NMEA.
The firmware has no GNSS command set at all. That matches distributor listings:
**`-LASE` is the variant without GNSS, `-FASE` has it.** The old note here saying
"the A7672E-LASE has an internal GNSS engine" was wrong.

The GNSS circuit on the board follows SIMCom's non-standalone reference (1V8_GNSS
from VDD_1V8, GNSS_TXD/RXD via 1 kΩ to UART3, GNSS_PWRCTL via 10 kΩ to MK_IN_3) and
the active-antenna bias feed (C418 100 pF DC block, L404 ferrite from VDD_AUX, which
reads `+CVAUXS: 1`, 3000 mV). C413/C414/R412 are the DNP matching footprints. So a
footprint-compatible **A7672E-FASE** should work as drawn. Two deviations to revisit
then: D403 (ESD9X3.3ST5G, 15 pF) is far above SIMCom's recommended sub-pF RF ESD
parts (PESD0402-03, CE0201S05G01R), and L404 is a ferrite bead rather than the
reference's >56 nH inductor plus series resistor.

**Action:** location needs a module swap to A7672E-FASE (or a separate GNSS
receiver). The `ModemA7672::gps*()` stubs stay stubs.

## 🟡 5. Important pads are on the BACK of the board

Several essential test/programming pads are on the **bottom side**, including **BOOT**
(GPIO9), the UART0 flash pads (TXD0/RXD0), QON (GPIO2), and reset (EN). If flashing
over USB Serial/JTAG ever fails, you recover via the **BOOT pad + reset** (hold BOOT
low, pulse reset, release BOOT) to force the ROM bootloader. See
[`pinout.md`](pinout.md) for the pad list.

## 🟡 6. GPIO14 sensor rail powers the SENSOR header, not the on-board sensors

Not a defect, just worth knowing: `GPIO14` drives a populated high-side switch
(active HIGH) for the **external sensor rail** on the SENSOR header. The on-board
SC7A20 + LTR-303 are wired directly to 3V3, **not** this rail, so cutting GPIO14 in
sleep does not power them down -- put those in low-power mode over I2C instead.

## 🔴 7. USB-C CC pins are floating - no VBUS (no charging) from C-to-C cables

`J201` (USB-C) has **CC1 and CC2 unconnected** in the schematic - there are no 5.1 k
Rd pulldowns. A spec-compliant USB-C source (laptop port, C-to-C cable, PD charger)
therefore never detects a sink and **never enables VBUS**: flashing and serial still
work (USB 2.0 data lines are hardwired and the ESP runs from the battery), but 0 V
reaches the charger. With a **USB-A to C cable** this erratum does not apply (A ports
supply 5 V unconditionally).

**Action:** for a respin, add 5.1 k from CC1 to GND and 5.1 k from CC2 to GND at
J201. Until then, charge via an A-to-C cable or VIN/solar.

**Debugging gotcha (resolved 2026-08-06, keep in mind):** if USB charging doesn't
start, don't trust a ~2.5 V reading on the `VUSB` net - that is a **phantom
voltage**, not a sagging 5 V rail. The ESP's D+ idles at 3.3 V and leaks through
the D212 (USBLC6) internal diode onto the VBUS net (3.3 V - 0.7 V, present even
with the cable unplugged). Since 2.6 V is below the BQ's ~3.6 V adapter-present
threshold, `AC1_PRESENT` stays 0 and the charger auto-clears `EN_ACDRV1`. On the
first Rev A unit the actual cause was a **cable with a broken VBUS wire** - the one
cable fault that is invisible on a self-powered board, because USB data (flashing,
serial) keeps working. With a good A-to-C cable the full path was verified: VAC1
~5.0 V, AC1_PRESENT=1, EN_ACDRV1 latches, fast-charge (CC) at the 500 mA SDP limit.
The self-test prints VAC1/VAC2 for exactly this diagnosis.

## 🟡 8. SPI flash is a GD25Q128 (16 MB), not the GD25Q256 on the schematic

The schematic symbol says GD25Q256 (32 MB), but the part populated on Rev A boards
reads JEDEC `C8 40 18` = **GD25Q128, 16 MB** (confirmed by the self-test). The
`ExtFlash` driver uses 3-byte addressing, which covers the whole 16 MB chip, so
nothing breaks -- just don't plan around 32 MB of storage.

---

### Notes on the old test firmware

The original `functionality_test_arduino` code charged the battery via the BQ25792 by
writing to **mislabelled registers** (it wrote ICHG to the IINDPM register and toggled
an ACDRV bit that is actually `WKUP_DLY`). It happened to work because the BQ's reset
defaults were already usable. The `BQ25792` driver in this repo uses the **correct**
registers per the TI datasheet (SLUSDG1D). If you port old snippets, cross-check the
register map in `lib/EcoTrace/BQ25792.h`.

---

## 🟠 9. Switched SENSOR rail has no bleed resistor

GPIO14's high-side switch leaves its output **floating** when it opens, so the
rail discharges only through whatever load is attached. Confirmed on the bench
2026-08-15 with an LED across the header: it **fades** rather than switching off.

Consequence: a short "power cycle" does not produce a power-on reset.
`board_sensor_power_cycle()` uses 800 ms for this reason.

**Respin:** ~100 kΩ from the switched rail to GND.

## 🔴 10. An unpowered device on the shared I2C bus takes the WHOLE bus down

Not specific to this board, but it bit hard and the symptom is misleading.

Any device on SDA/SCL that is unpowered while the bus is live will clamp it:
its ESD diodes hold the lines at ~0.6 V, and any pull-ups it has to *its* rail
become pull-downs to ground. I2C has no isolation, so **one clamped line makes
every device on those wires unreachable**.

Observed 2026-08-15 with the ultrasonic board unpowered: BQ25792 "not found",
light sensor and accelerometer silent, entire record zeros. All of them healthy.

Two error signatures separate this from a device fault, and they are worth
memorising:

* ESP-IDF **`clear bus failed`** = a line is held low -> hardware/power
* ESP-IDF **`unexpected nack`** = bus healthy, that device did not answer

**Respin:** if anything on a switched rail shares the bus, add an I2C isolator
(TCA9517/TCA4311A class) or two BSS138 FETs on SDA/SCL gated by the rail enable.
Otherwise "power-cycle the sensor" and "keep the charger readable" are mutually
exclusive -- and a node that cannot read its charger cannot manage its battery.

## 🟠 11. Cutting a device's VCC does not power it down while the bus idles high

The same coupling in reverse. Current flows: our 3V3 -> bus pull-up -> SDA ->
the device's ESD clamp -> its VCC. It sits about a diode drop below the bus:
**too low to run, too high to trigger a power-on reset**.

This is why `board_sensor_power_cycle()` holds SDA and SCL **low** for the whole
off window (`eco_i2c_hold_low()`), and why leaving a switched rail off during
deep sleep *costs* ~1.4 mA rather than saving anything.

## 🟡 12. Telemetry datapoint budget is a real constraint

ThingsBoard Cloud closed the MQTT connection (`transport_read(): EOF`,
`mqtt_message_receive() returned -2`) once records carried ~40 datapoints at
8 records per publish (~320 per message). Trimmed to 22 keys per record.

Related, and worse because it is silent: the record payload buffer was 800 bytes
and the JSON grew past it. `snprintf` truncated mid-field, the JSON became
malformed, and the server rejected **the whole batch** with no error anywhere.
The symptom was every sensor key frozen at one timestamp while the separate,
shorter status payload kept updating. `record_values()` now returns -1 on
truncation so it cannot fail quietly again.

Also: keep large payload buffers **static**. A 1536-byte automatic on the 4 kB
main task stack triggered `Guru Meditation Error: Core 0 panic'ed (Stack
protection fault)` mid-upload, rebooting the device every cycle.

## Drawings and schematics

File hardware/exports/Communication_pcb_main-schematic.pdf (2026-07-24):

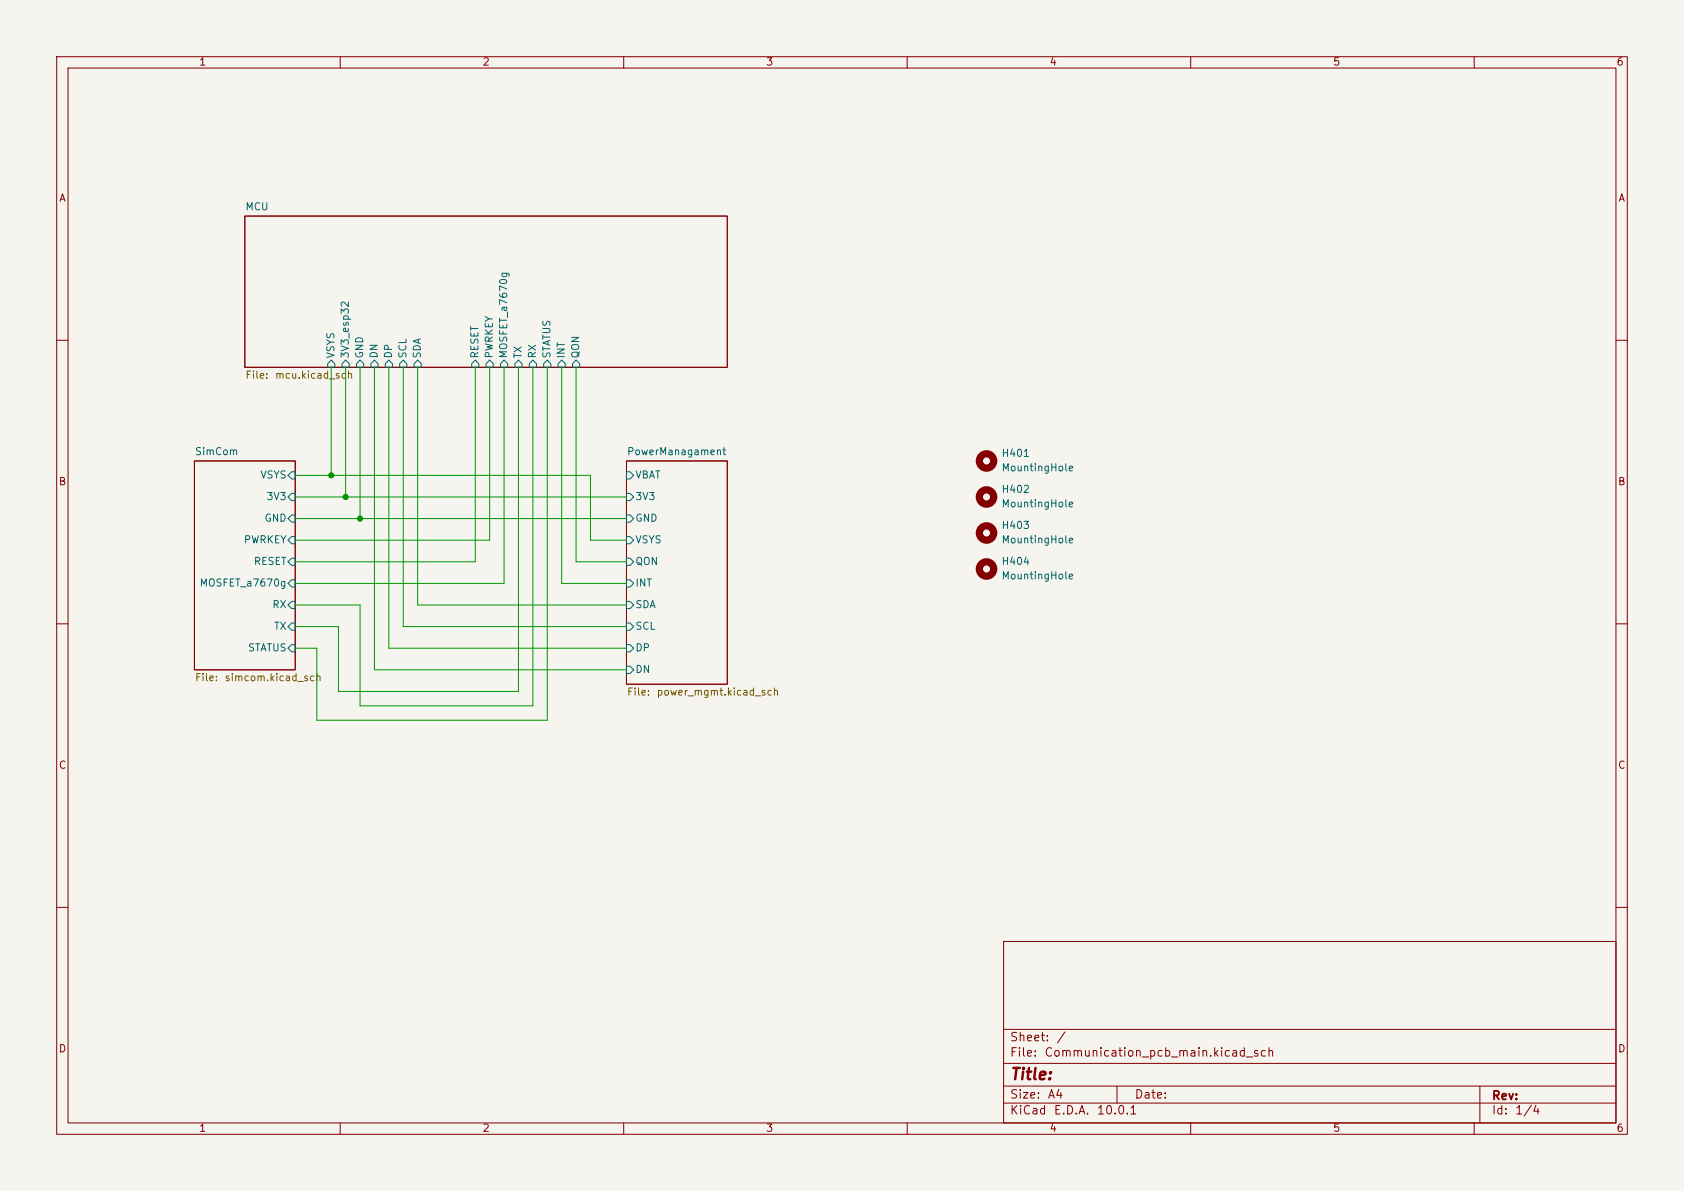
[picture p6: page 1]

Size: A4 | Rev:
KiCad E.D.A. 10.0.1 | Id: 1/4

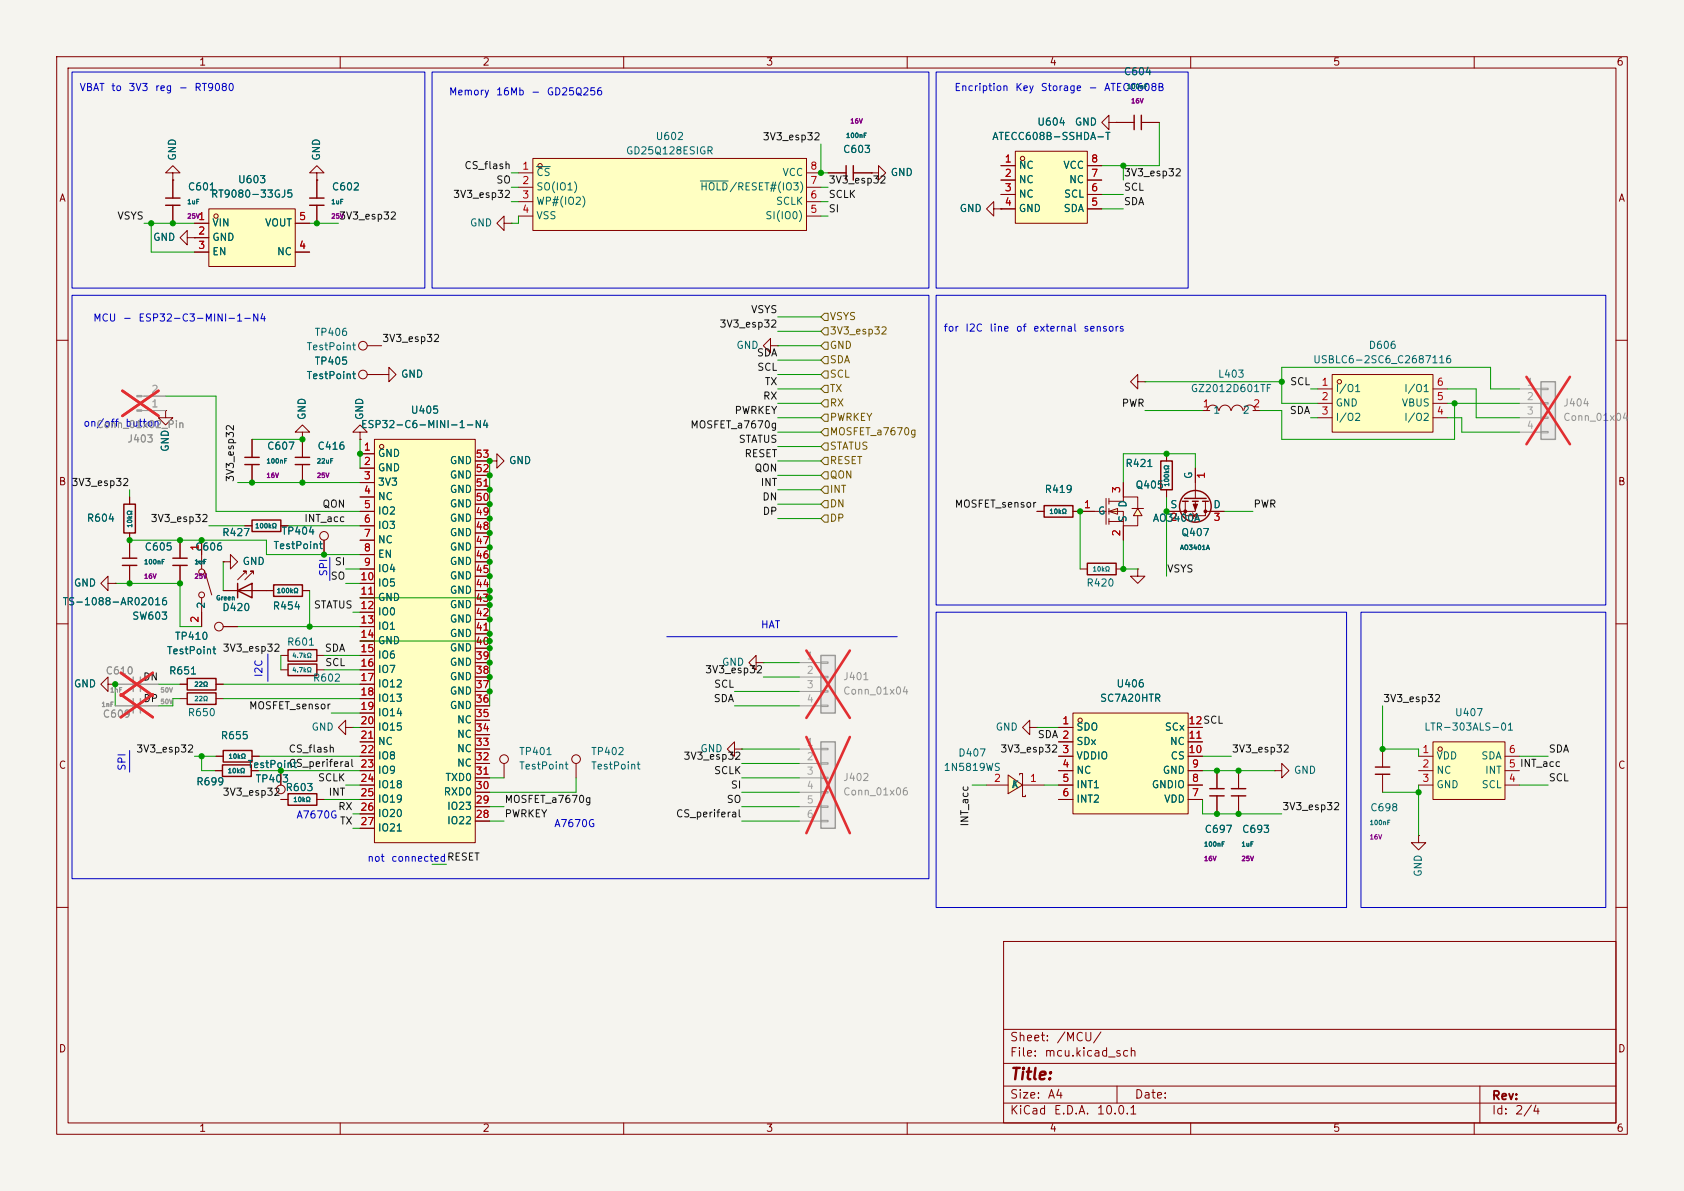
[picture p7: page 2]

for I2C line of external sensors VBAT to 3V3 reg - RT9080
1uF 25V GND

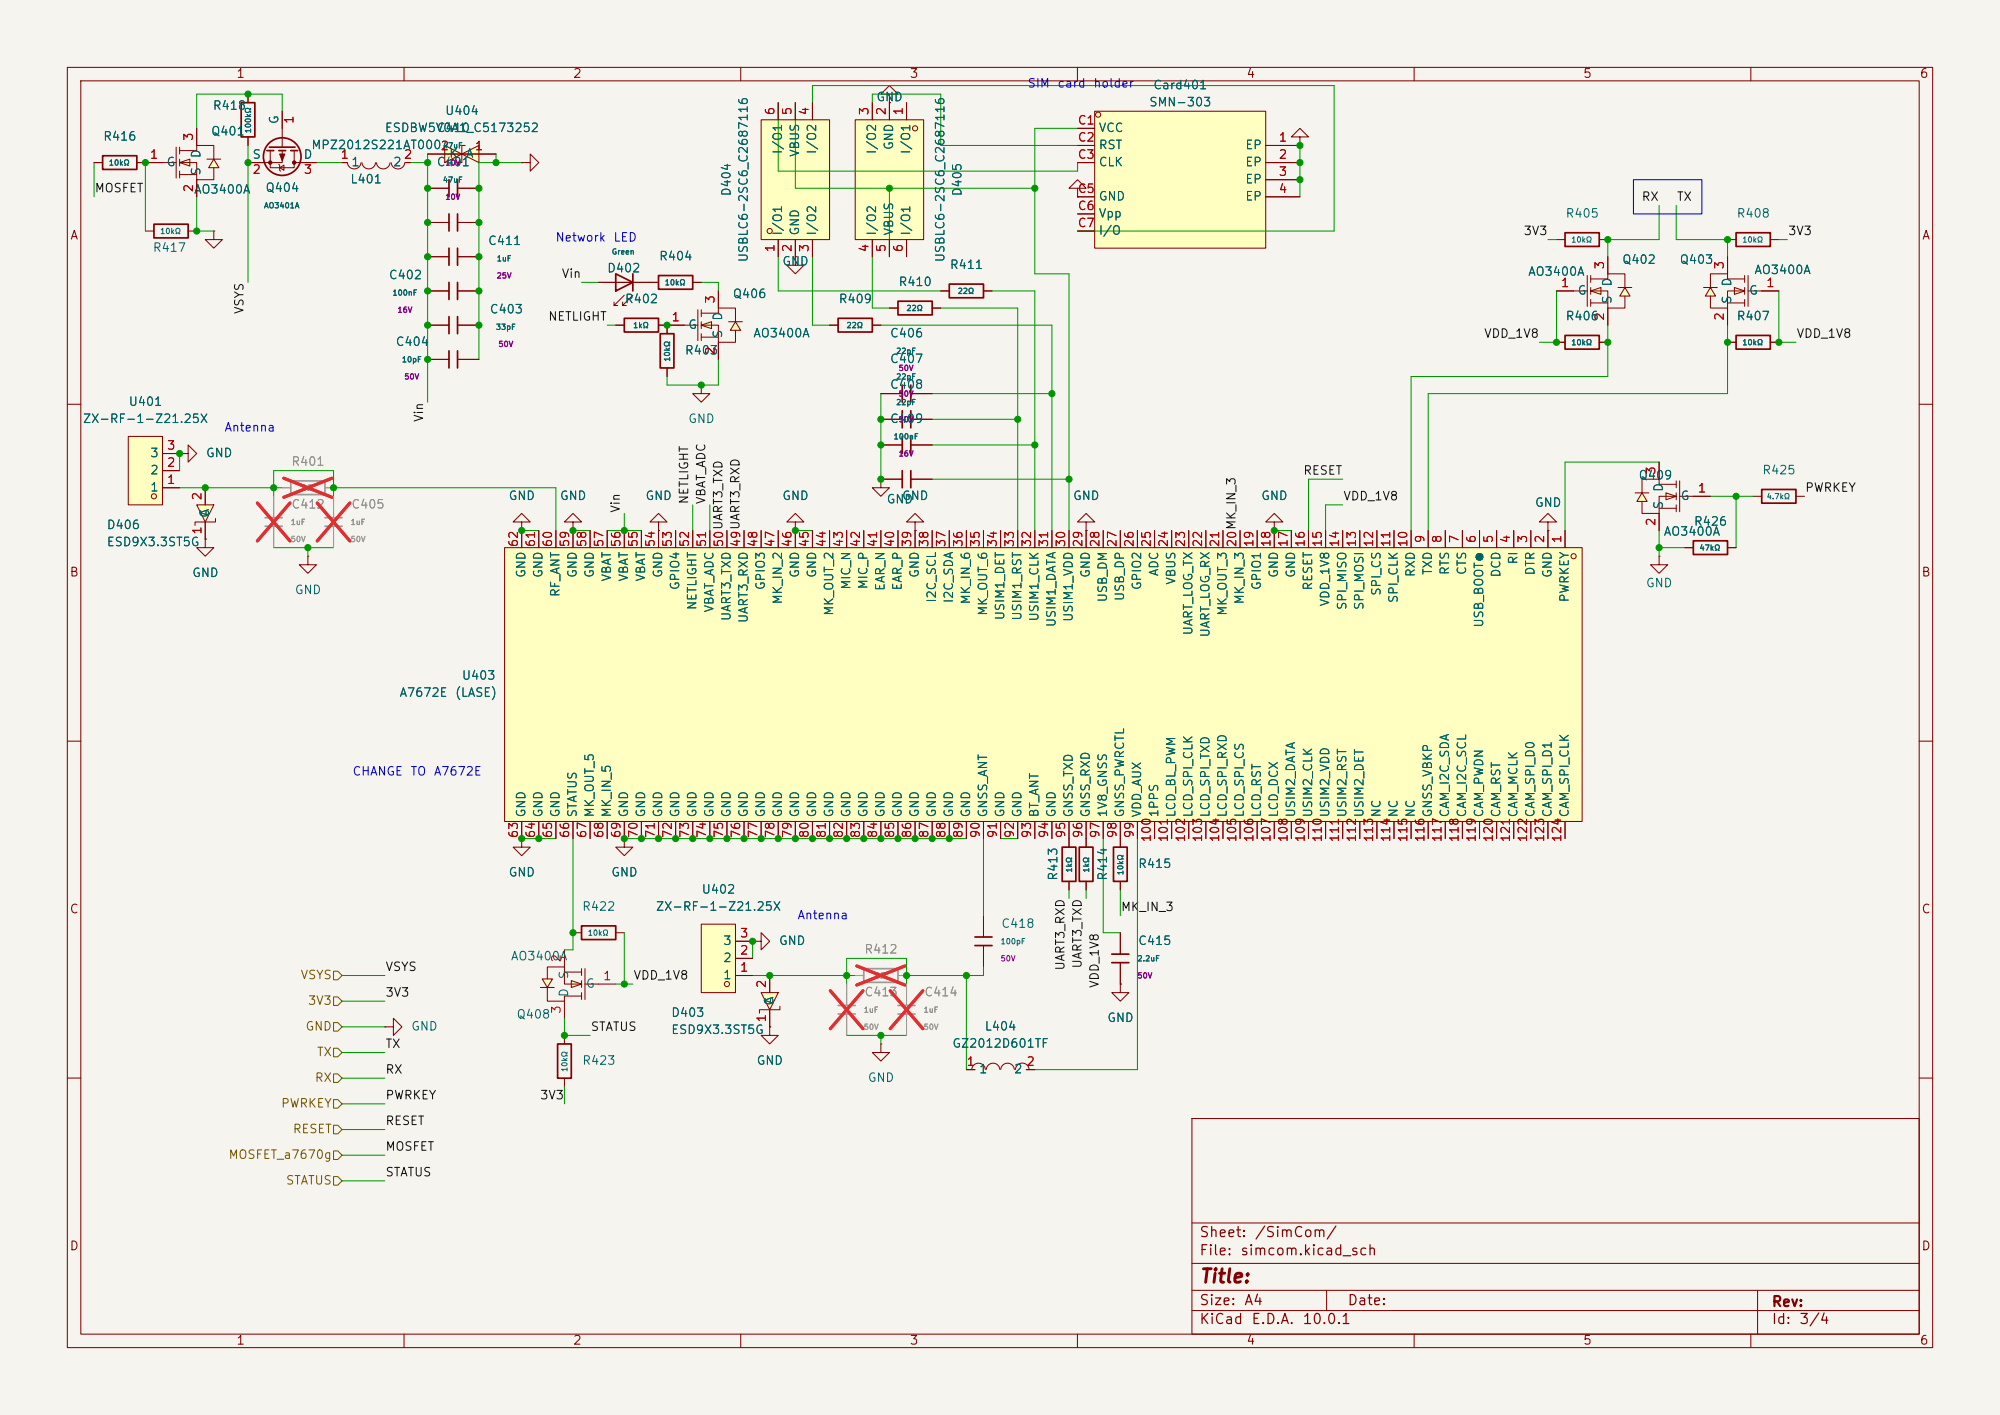
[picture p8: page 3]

VCC C1 RST C2 CLK C3 GND C5

9 RXD 10 SPI_CLK 11 SPI_CS 12 SPI_MOSI 13 SPI_MISO 14 VDD_1V8 15 RESET 16 GND 17 GND 18 GPIO1 19 MK_IN_3 20 MK_OUT_3 21 UART_LOG_RX 22 UART_LOG_TX 23 VBUS 24 ADC 25 GPIO2 26 USB_DP 27 USB_DM 28 GND 29 USIM1_VDD 30 USIM1_DATA 31 USIM1_CLK 32 USIM1_RST 33 USIM1_DET 34 MK_OUT_6 35 MK_IN_6 36 I2C_SDA 37 I2C_SCL 38 GND 39 EAR_P 40 EAR_N 41 MIC_P 42 MIC_N 43 MK_OUT_2 44 GND 45 GND 46 MK_IN_2 47 GPIO3 48 UART3_RXD 49 UART3_TXD 50 VBAT_ADC 51 NETLIGHT 52 GPIO4 53 GND 54 VBAT 55 VBAT 56 VBAT 57 GND 58 GND 59 RF_ANT 60 GND 61 GND 62 GND 63 GND 64 GND 65 STATUS 66 MK_OUT_5 67 MK_IN_5 68 GND 69 GND 70 GND 71 GND 72 GND 73 GND 74 GND 75 GND 76 GND 77 GND 78 GND 79 GND 80 GND 81 GND 82 GND 83 GND 84 GND 85 GND 86 GND 87 GND 88 GND 89 GNSS_ANT 90 GND 91 GND 92 BT_ANT 93 GND 94 GNSS_TXD 95 GNSS_RXD 96 1V8_GNSS 97 GNSS_PWRCTL 98 VDD_AUX 99 1PPS 100LCD_BL_PWM 101LCD_SPI_CLK 102LCD_SPI_TXD 103LCD_SPI_RXD 104LCD_SPI_CS 105LCD_RST 106LCD_DCX 107USIM2_DATA 108USIM2_CLK 109USIM2_VDD 110USIM2_RST 111USIM2_DET 112NC 113NC 114NC 115GNSS_VBKP 116CAM_I2C_SDA 117CAM_I2C_SCL 118CAM_PWDN 119CAM_RST 120CAM_MCLK 121CAM_SPI_D0 122CAM_SPI_D1 123CAM_SPI_CLK 124 R407

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

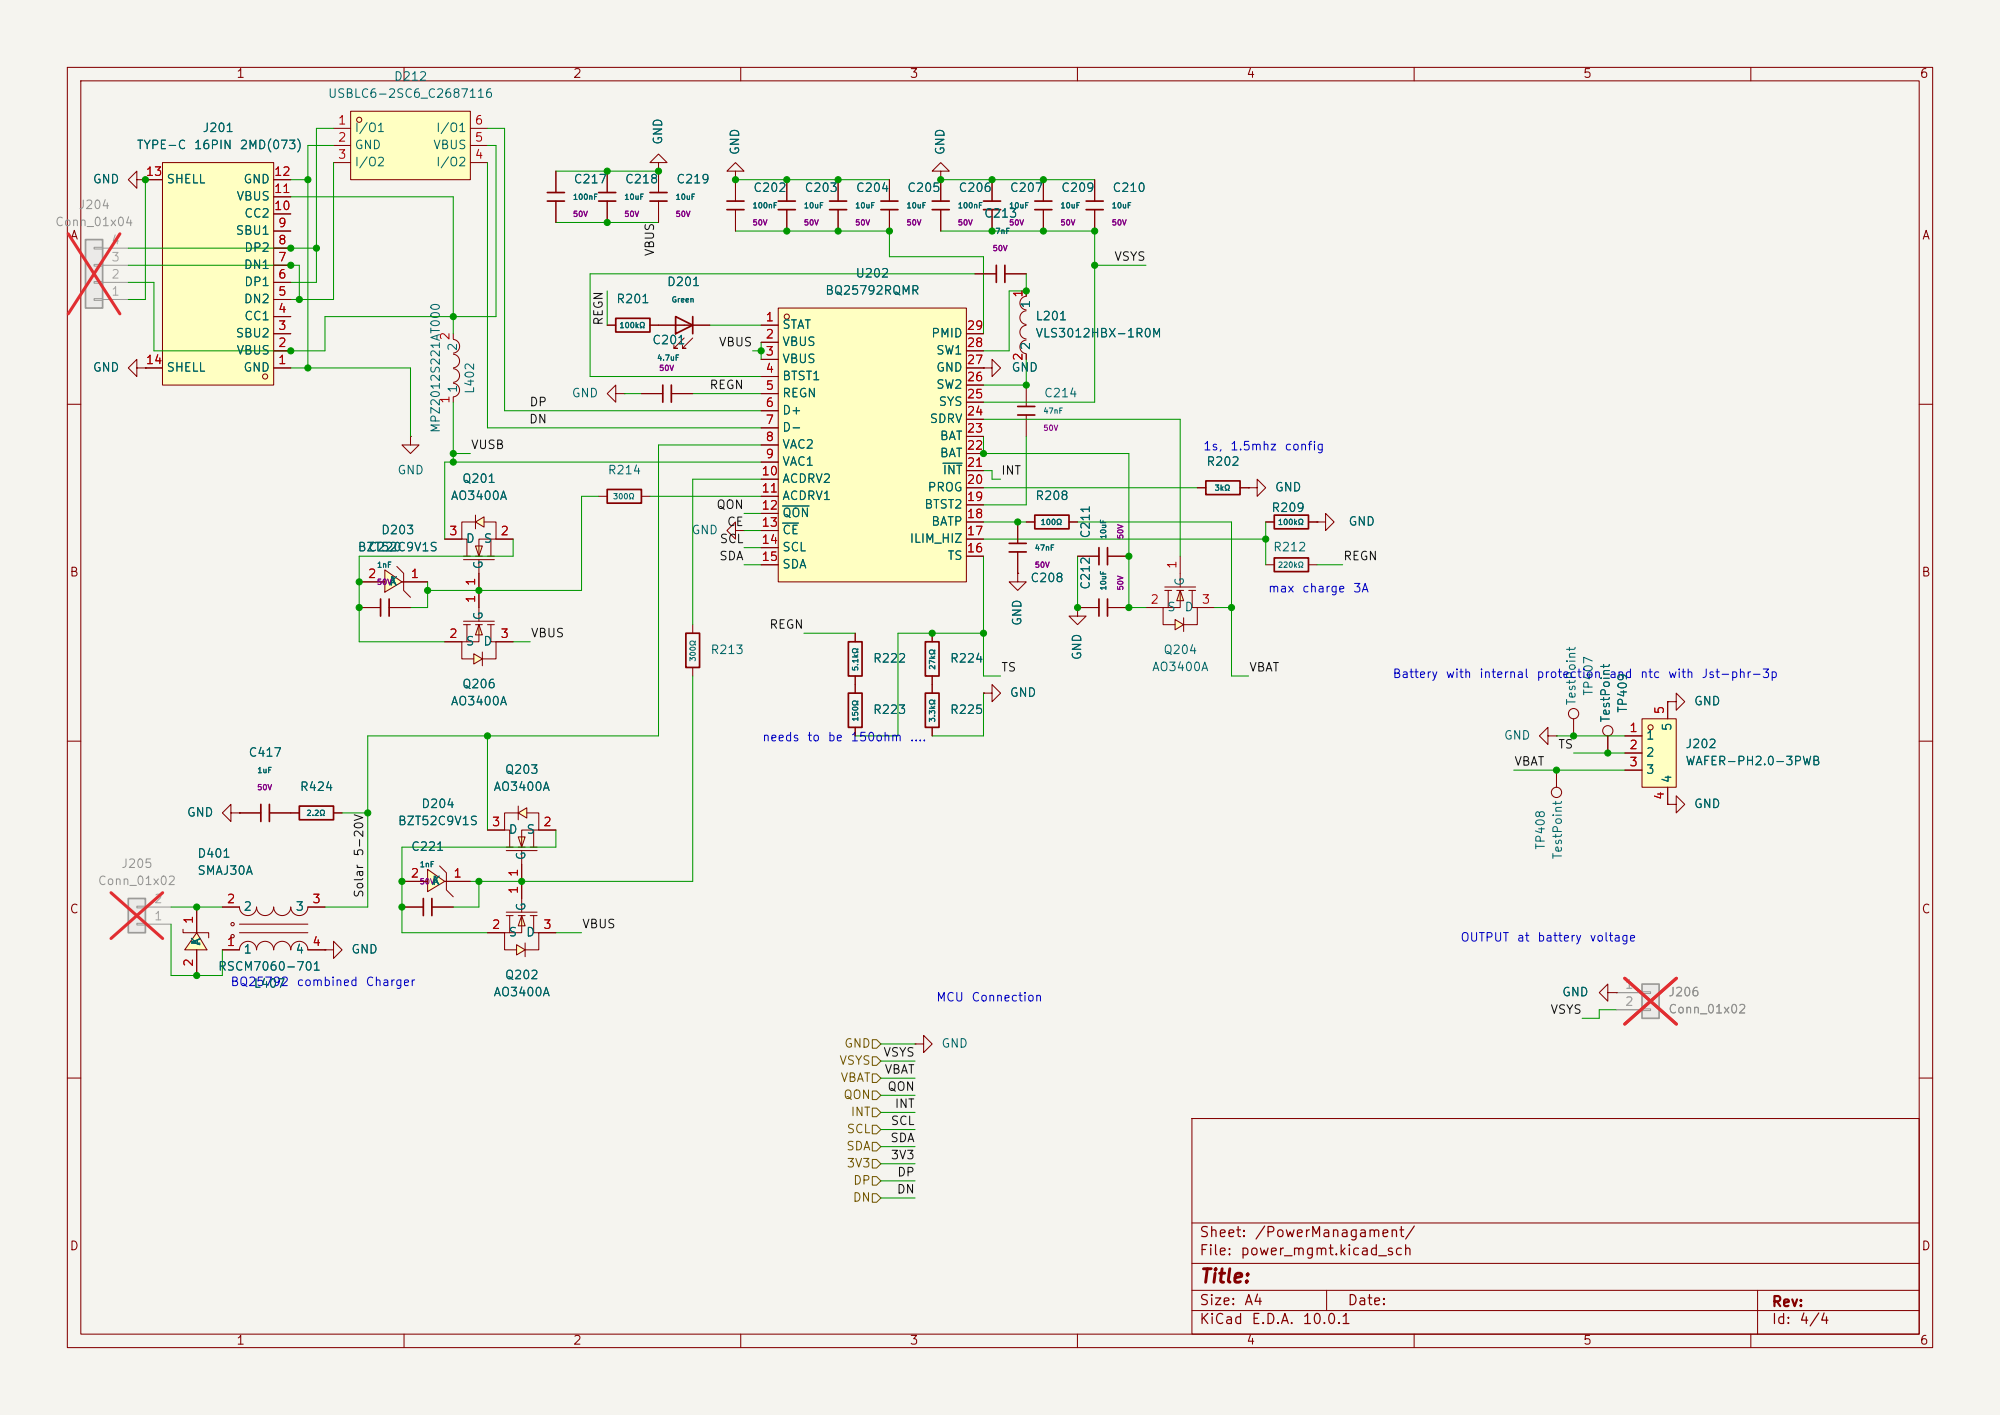
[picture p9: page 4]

ACDRV1 11 QON 12 CE 13

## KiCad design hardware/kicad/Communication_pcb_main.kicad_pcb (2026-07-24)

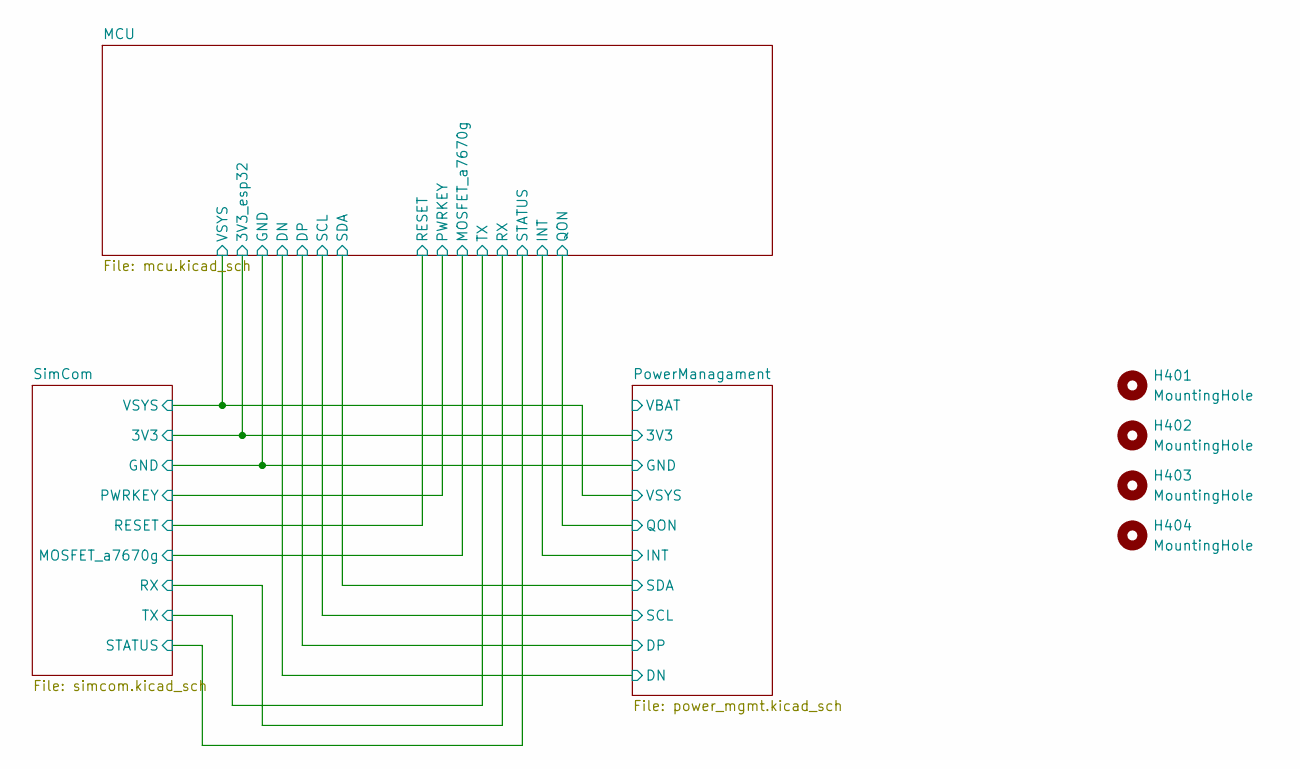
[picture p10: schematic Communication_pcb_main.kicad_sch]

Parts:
H401, H403: MountingHole; MountingHole_2.2mm_M2_ISO14580_Pad
H402, H404: MountingHole; Slot_2.2mm_M2_ISO14580_Pad

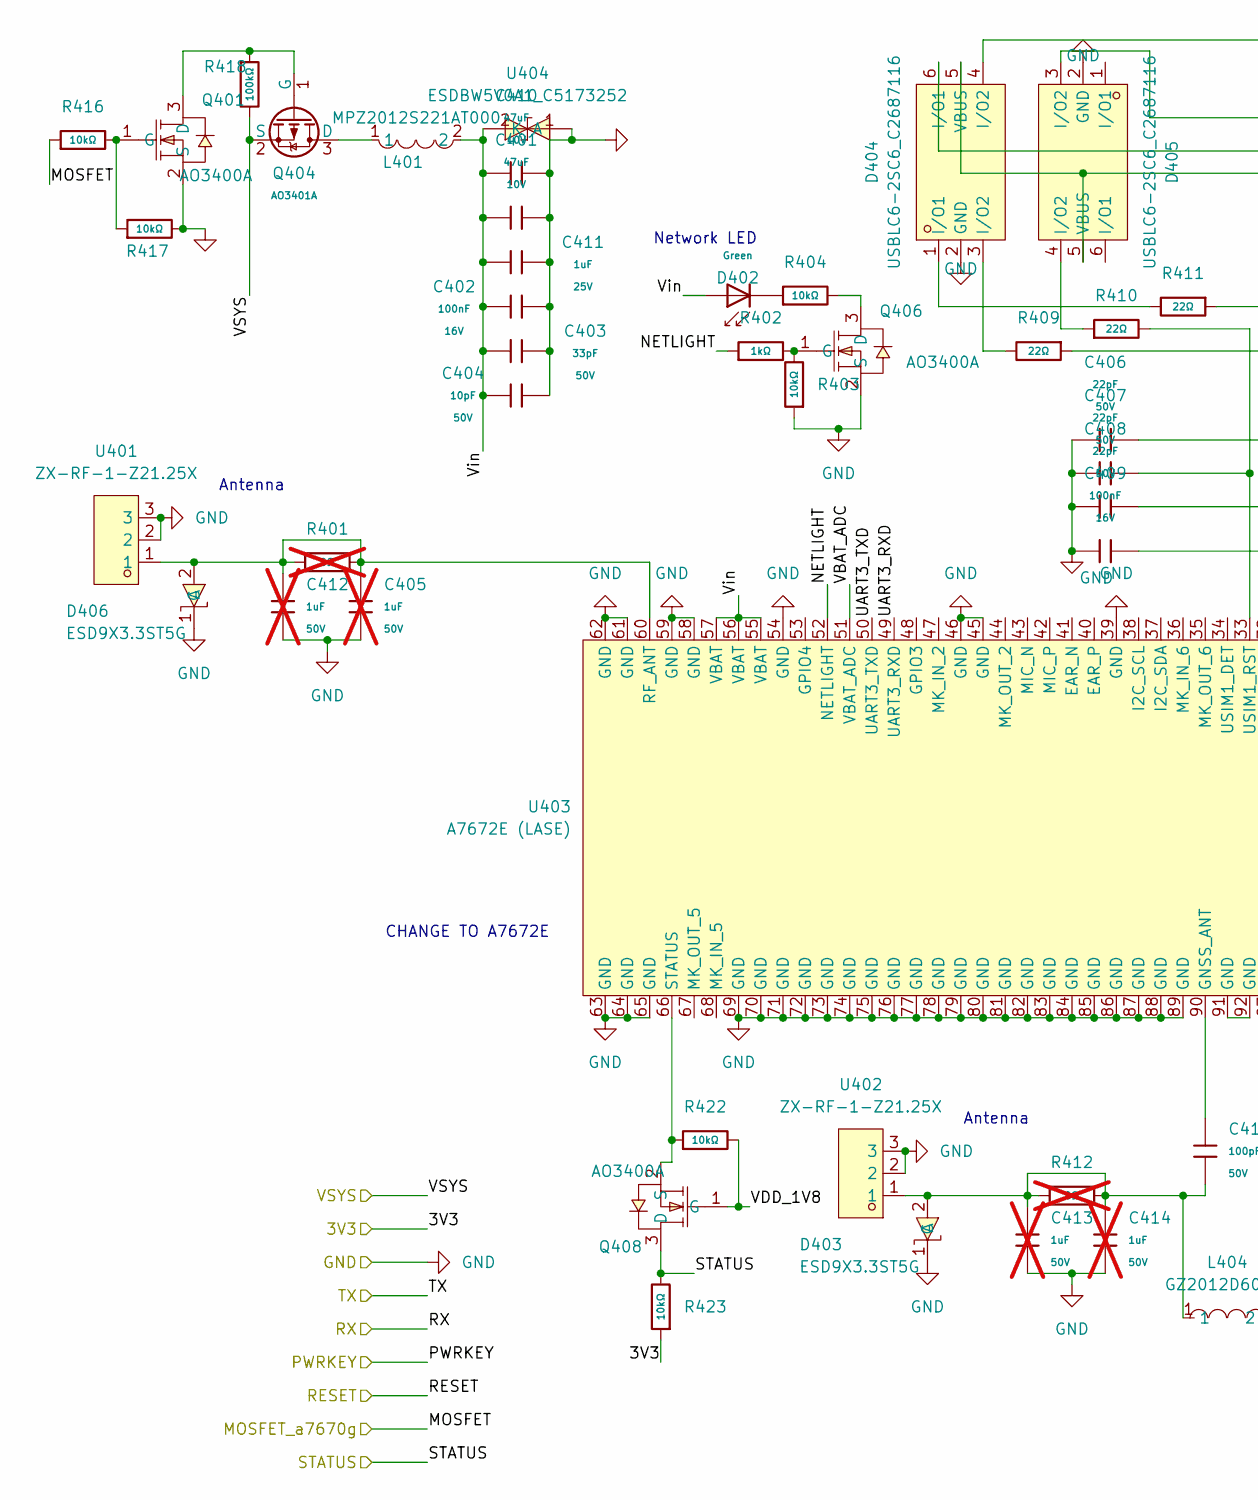
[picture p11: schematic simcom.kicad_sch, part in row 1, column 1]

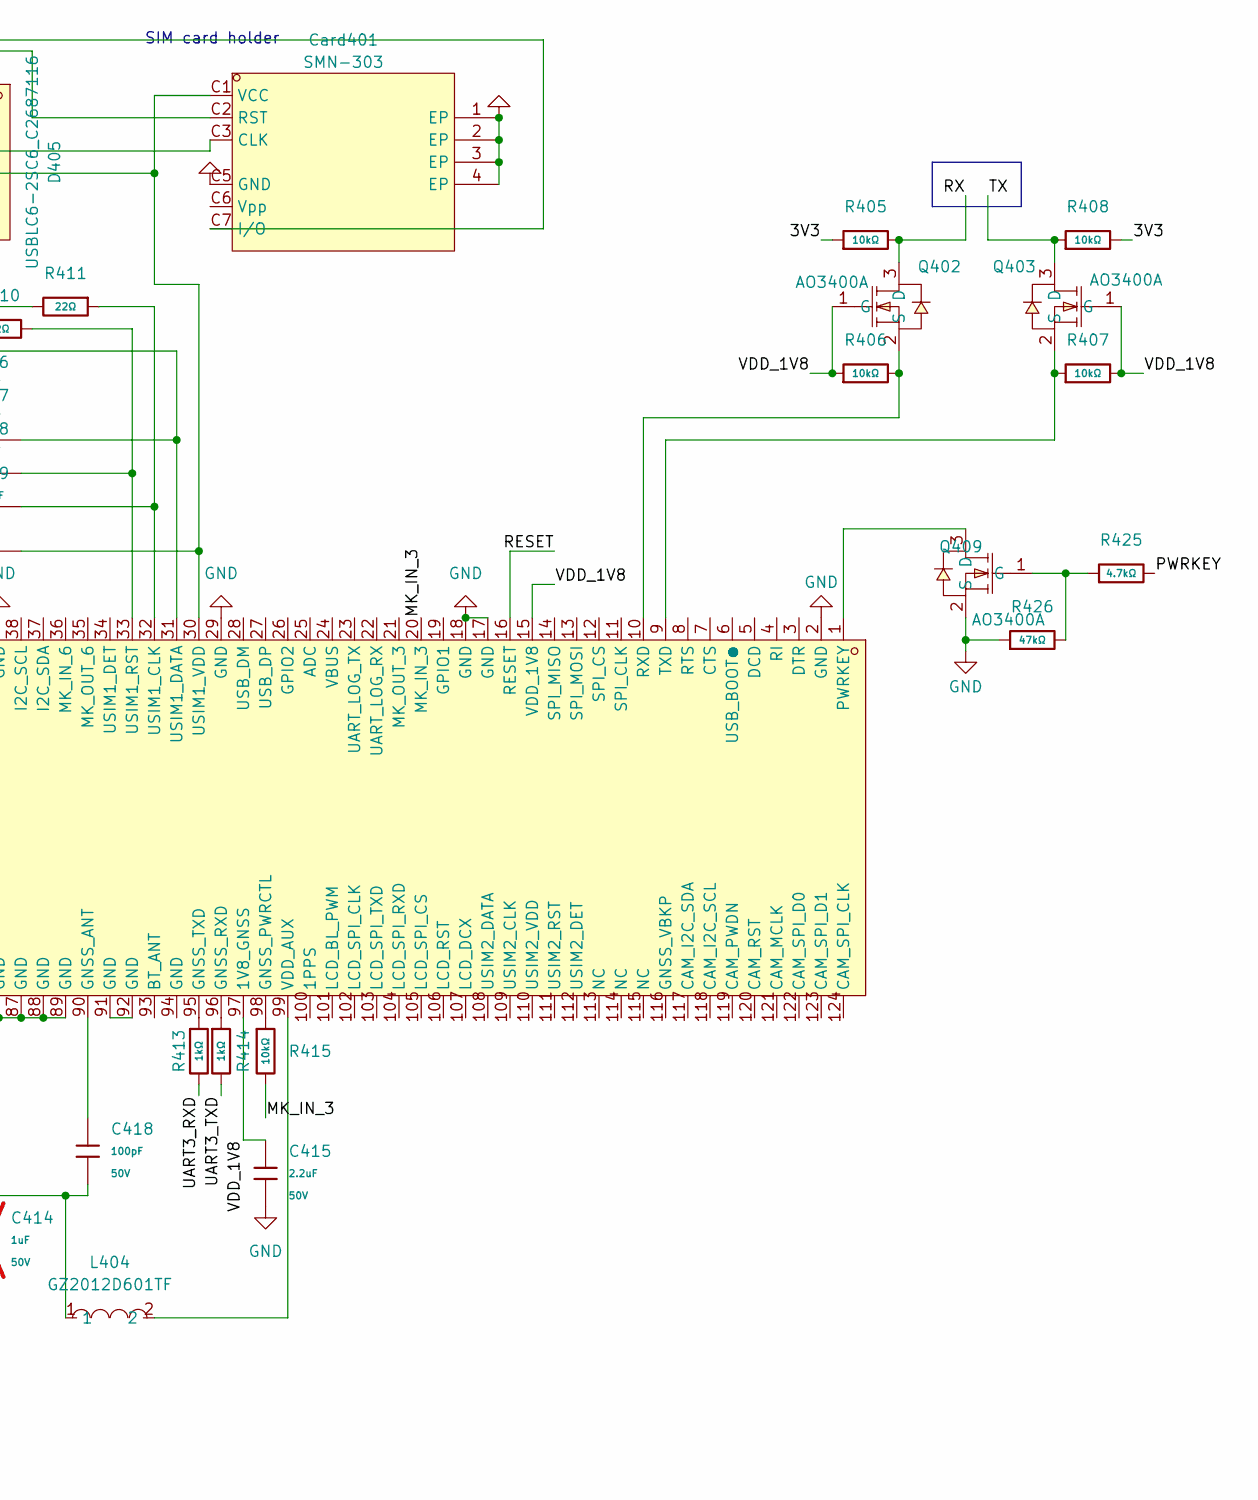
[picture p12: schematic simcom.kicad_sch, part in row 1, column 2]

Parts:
C401, C410: 47uF; C_1206; Voltage Rated 10V; Tolerance ±20%; Part CL31A476MPHNNNE; LCSC C96123
C402, C409: 100nF; C_0402; Voltage Rated 16V; Tolerance ±10%; Part CL05B104KO5NNNC; LCSC C1525
C403: 33pF; C_0402; Voltage Rated 50V; Tolerance ±5%; Part 0402CG330J500NT; LCSC C1562
C404: 10pF; C_0402; Voltage Rated 50V; Tolerance ±5%; Part CL05C100JB5NNNC; LCSC C32949
C405, C412, C413, C414: 1uF; C_0805; Voltage Rated 50V; Tolerance ±10%; Part CL21B105KBFNNNE; LCSC C28323; not fitted
C406, C407, C408: 22pF; C_0402; Voltage Rated 50V; Tolerance ±5%; Part 0402CG220J500NT; LCSC C1555
C411: 1uF; C_0402; Voltage Rated 25V; Tolerance ±10%; Part CL05A105KA5NQNC; LCSC C52923
C415: 2.2uF; C_0805; Voltage Rated 50V; Tolerance ±10%; Part CL21A225KBQNNNE; LCSC C377773
C418: 100pF; C_0805; Voltage Rated 50V; Tolerance ±5%; Part CL21C101JBANNNC; LCSC C1790
Card401: SMN-303; SIM-SMD_SMN-305; LCSC Part C266890
D402: Green; D_0805; Part KT-0805G; LCSC C2297
D403, D406: ESD9X3.3ST5G; SOD-923_L0.8-W0.6-LS1.0-RD; MPN ESD9X3.3ST5G; LCSC Part C130456
D404, D405: USBLC6-2SC6_C2687116; SOT-23-6_L2.9-W1.6-P0.95-LS2.8-BL; LCSC Part C2687116
L401: MPZ2012S221AT000; L0805; LCSC Part C76818
L404: GZ2012D601TF; L0805; MPN GZ2012D601TF; LCSC Part C1017
Q401, Q402, Q403, Q406, Q408, Q409: AO3400A; SOT-23-3_L2.9-W1.3-P1.90-LS2.4-BR; MPN AO3400A; LCSC Part C20917
Q404: AO3401A; Q_SOT-23; Part AO3401A; LCSC C15127
R401, R412: 0Ω; R_0805; Overload Voltage (Max) 150V; Tolerance ±1%; Part 0805W8F0000T5E; LCSC C17477; not fitted
R402, R413, R414: 1kΩ; R_0402; Overload Voltage (Max) 50V; Tolerance ±1%; Part 0402WGF1001TCE; LCSC C11702
R403, R404, R405, R406, R407, R408, R415, R416, R417, R422, R423: 10kΩ; R_0402; Overload Voltage (Max) 50V; Tolerance ±1%; Part 0402WGF1002TCE; LCSC C25744
R409, R410, R411: 22Ω; R_0402; Overload Voltage (Max) 50V; Tolerance ±1%; Part 0402WGF220JTCE; LCSC C25092
R418: 100kΩ; R_0402; Overload Voltage (Max) 50V; Tolerance ±1%; Part 0402WGF1003TCE; LCSC C25741
R425: 4.7kΩ; R_0402; Overload Voltage (Max) 50V; Tolerance ±1%; Part 0402WGF4701TCE; LCSC C25900
R426: 47kΩ; R_0402; Overload Voltage (Max) 50V; Tolerance ±1%; Part 0402WGF4702TCE; LCSC C25792
U401, U402: ZX-RF-1-Z21.25X; IPEX-SMD_3P-L2.6-W2.6-LS3.0_YUANDI_RF-001; LCSC Part C7426714
U403: A7672E (LASE); LGA-124_L24.0-W24.0-P1.0-A7670C-LASS; LCSC Part C6116733
U404: ESDBW5V0A1_C5173252; X1-DFN1006-2_L1.0-W0.6-P0.65-BI; LCSC Part C5173252

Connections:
/MCU/3V3_esp32: R405.1, R408.2, R423.1; also elsewhere on the board
/MCU/MOSFET_a7670g: R416.1; also elsewhere on the board
/MCU/PWRKEY: R425.2; also elsewhere on the board
/MCU/RESET: U403.16 (RESET)
/MCU/RX: Q402.3 (D), R405.2; also elsewhere on the board
/MCU/STATUS: Q408.3 (D), R423.2; also elsewhere on the board
/MCU/TX: Q403.3 (D), R408.1; also elsewhere on the board
/MCU/VSYS: Q404.2 (S), R418.2; also elsewhere on the board
/SimCom/MK_IN_3: R415.2, U403.20 (MK_IN_3)
/SimCom/NETLIGHT: R402.1, U403.52 (NETLIGHT)
/SimCom/UART3_RXD: R413.2, U403.49 (UART3_RXD)
/SimCom/UART3_TXD: R414.2, U403.50 (UART3_TXD)
/SimCom/VBAT_ADC: U403.51 (VBAT_ADC)
/SimCom/VDD_1V8: C415.2, Q402.1 (G), Q403.1 (G), Q408.1 (G), R406.1, R407.2, R422.2, U403.15 (VDD_1V8), U403.97 (1V8_GNSS)
/SimCom/Vin: C401.1, C402.1, C403.1, C404.1, C410.1, C411.1, D402.2, L401.2, U403.55 (VBAT), U403.56 (VBAT), U403.57 (VBAT), U404.2 (A)
GND: C401.2, C402.2, C403.2, C404.2, C405.2, C406.1, C407.1, C408.1, C409.1, C410.2, C411.2, C412.2, C413.2, C414.2, C415.1, Card401.1 (EP), Card401.2 (EP), Card401.3 (EP), Card401.4 (EP), Card401.C5 (GND), D403.1 (C), D404.2 (GND), D405.2 (GND), D406.1 (C), Q401.2 (S), Q406.2 (S), Q409.2 (S), R403.1, R417.2, R426.1, U401.2, U401.3, U402.2, U402.3, U403.2 (GND), U403.17 (GND), U403.18 (GND), U403.29 (GND), U403.39 (GND), U403.45 (GND), U403.46 (GND), U403.54 (GND), U403.58 (GND), U403.59 (GND), U403.61 (GND), U403.62 (GND), U403.63 (GND), U403.64 (GND), U403.65 (GND), U403.69 (GND), U403.70 (GND), U403.71 (GND), U403.72 (GND), U403.73 (GND), U403.74 (GND), U403.75 (GND), U403.76 (GND), U403.77 (GND), U403.78 (GND), U403.79 (GND), U403.80 (GND), U403.81 (GND), U403.82 (GND), U403.83 (GND), U403.84 (GND), U403.85 (GND), U403.86 (GND), U403.87 (GND), U403.88 (GND), U403.89 (GND), U404.1 (K); also elsewhere on the board
unnamed: Card401.C3 (CLK), D404.6 (I/O1)
unnamed: Card401.C7 (I/O), D404.4 (I/O2)
unnamed: Card401.C2 (RST), D405.3 (I/O2)
unnamed: C409.2, Card401.C1 (VCC), D404.5 (VBUS), D405.5 (VBUS), U403.30 (USIM1_VDD)
unnamed: D402.1, R404.1
unnamed: C413.1, C414.1, C418.1, D403.2 (A), L404.1, R412.1, R412.2, U402.1
unnamed: D404.1 (I/O1), R411.2
unnamed: D404.3 (I/O2), R409.2
unnamed: D405.4 (I/O2), R410.1
unnamed: C405.1, C412.1, D406.2 (A), R401.1, R401.2, U401.1, U403.60 (RF_ANT)
unnamed: Q401.3 (D), Q404.1 (G), R418.1
unnamed: Q401.1 (G), R416.2, R417.1
unnamed: Q402.2 (S), R406.2, U403.10 (RXD)
unnamed: Q403.2 (S), R407.1, U403.9 (TXD)
unnamed: L401.1, Q404.3 (D)
unnamed: Q406.3 (D), R404.2
unnamed: Q406.1 (G), R402.2, R403.2
unnamed: Q408.2 (S), R422.1, U403.66 (STATUS)
unnamed: Q409.3 (D), U403.1 (PWRKEY)
unnamed: Q409.1 (G), R425.1, R426.2
unnamed: U403.91 (GND), U403.92 (GND)
unnamed: C418.2, U403.90 (GNSS_ANT)
unnamed: R415.1, U403.98 (GNSS_PWRCTL)
unnamed: R414.1, U403.96 (GNSS_RXD)
unnamed: R413.1, U403.95 (GNSS_TXD)
unnamed: C408.2, R411.1, U403.32 (USIM1_CLK)
unnamed: C406.2, R409.1, U403.31 (USIM1_DATA)
unnamed: C407.2, R410.2, U403.33 (USIM1_RST)
unnamed: L404.2, U403.99 (VDD_AUX)

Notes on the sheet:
Antenna
Network LED
CHANGE TO A7672E
SIM card holder

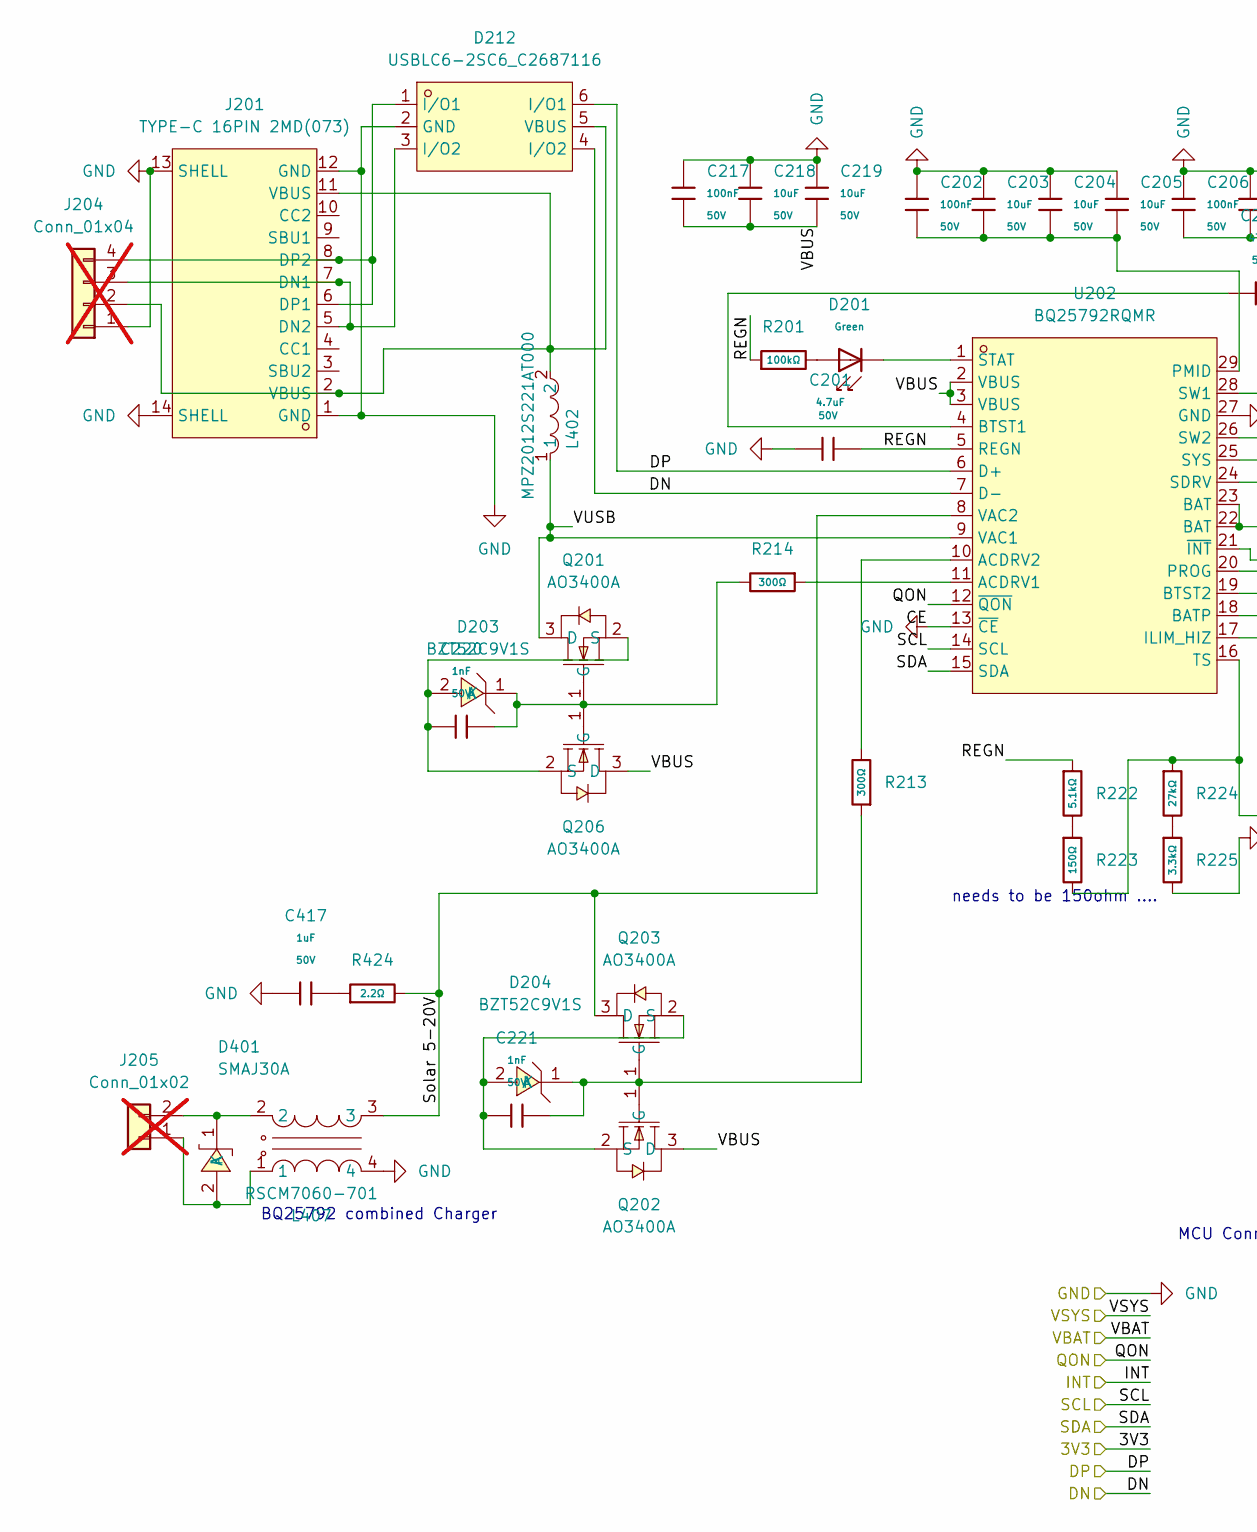
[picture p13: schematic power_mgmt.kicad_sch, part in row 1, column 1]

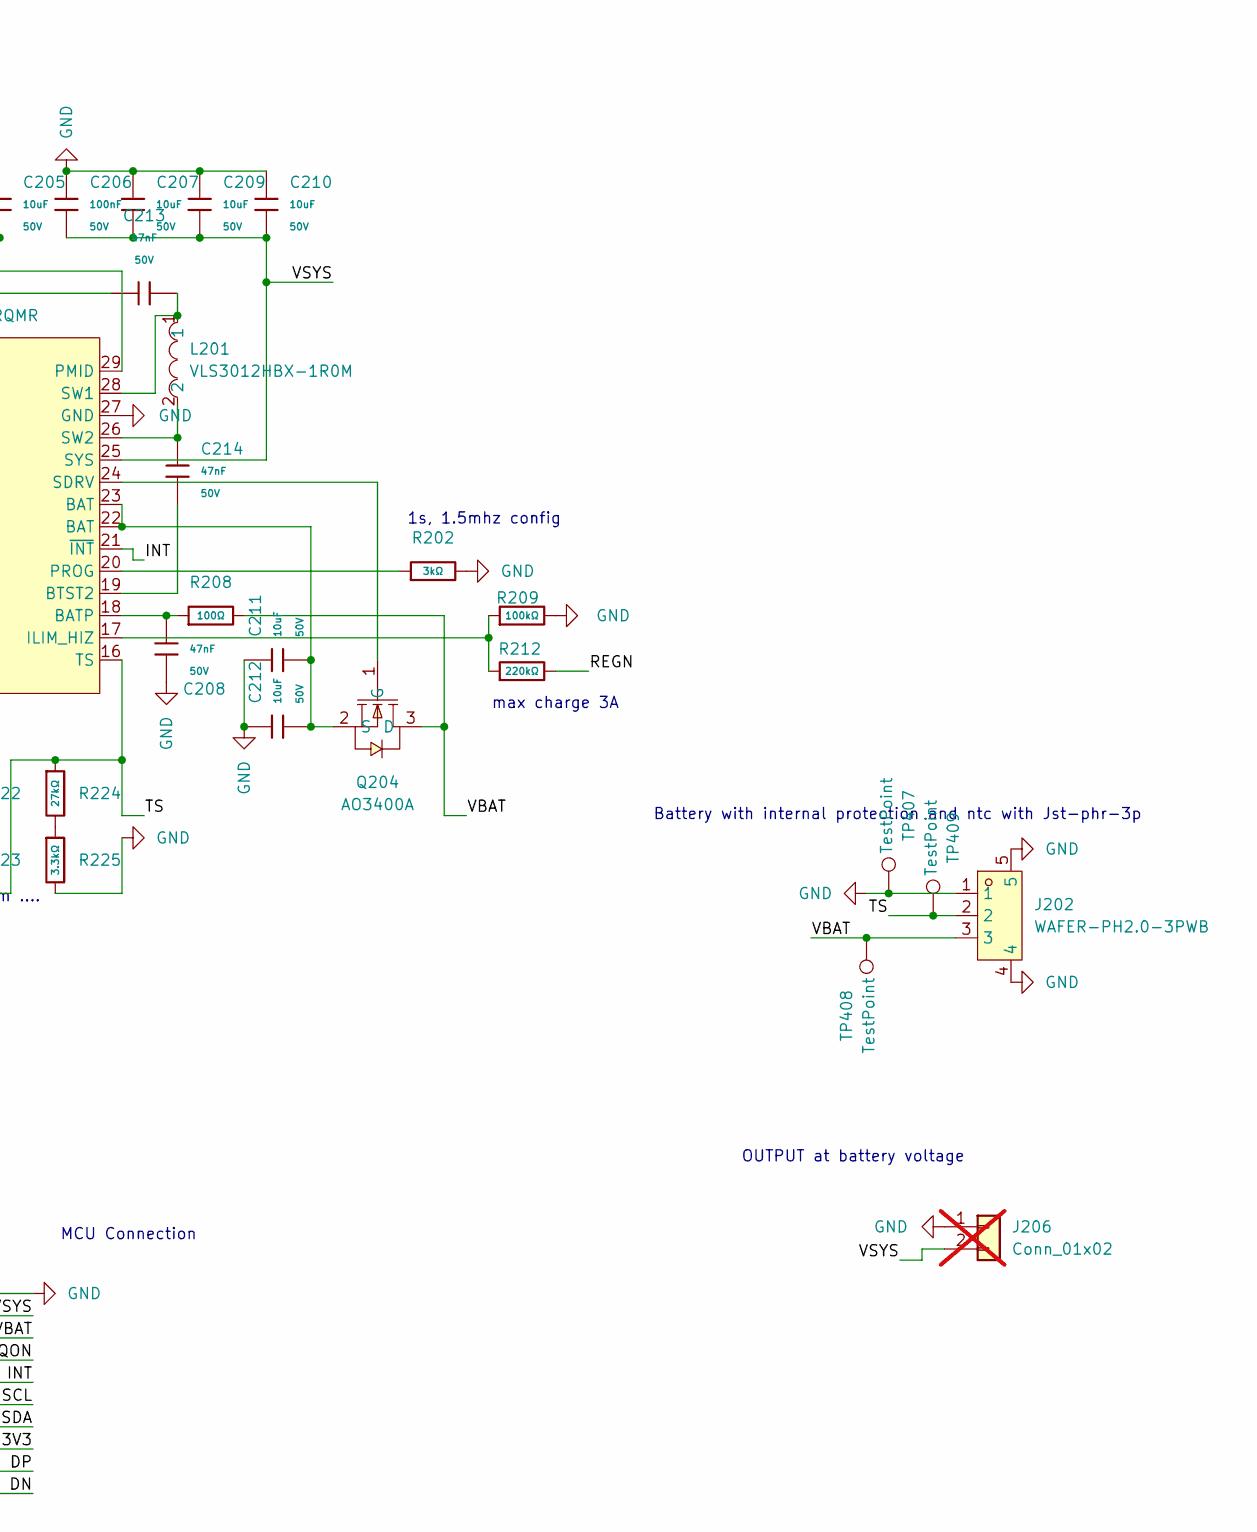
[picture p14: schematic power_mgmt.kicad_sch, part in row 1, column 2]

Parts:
C201: 4.7uF; C_1206; Voltage Rated 50V; Tolerance ±10%; Part 1206B475K500NT; LCSC C29823
C202, C206, C217: 100nF; C_0603; Voltage Rated 50V; Tolerance ±10%; Part CC0603KRX7R9BB104; LCSC C14663
C203, C204, C205, C207, C209, C210, C211, C212, C218, C219: 10uF; C_1206; Voltage Rated 50V; Tolerance ±10%; Part CL31A106KBHNNNE; LCSC C13585
C208, C213, C214: 47nF; C_0603; Voltage Rated 50V; Tolerance ±10%; Part CL10B473KB8NNNC; LCSC C1622
C220, C221: 1nF; C_0402; Voltage Rated 50V; Tolerance ±10%; Part 0402B102K500NT; LCSC C1523
C417: 1uF; C_0603; Voltage Rated 50V; Tolerance ±10%; Part CL10A105KB8NNNC; LCSC C15849
D201: Green; D_0805; Part KT-0805G; LCSC C2297
D203, D204: BZT52C9V1S; SOD-323_L1.8-W1.3-LS2.5-RD; LCSC Part C22614
D212: USBLC6-2SC6_C2687116; SOT-23-6_L2.9-W1.6-P0.95-LS2.8-BL; LCSC Part C2687116
D401: SMAJ30A; SMA_L4.3-W2.6-LS5.2-RD; MPN SMAJ30A; LCSC Part C10767
J201: TYPE-C 16PIN 2MD(073); USB-C-SMD_TYPE-C-6PIN-2MD-073; LCSC Part C2765186
J202: WAFER-PH2.0-3PWB; CONN-SMD_3P-P2.00_XUNPU_WAFER-PH2.0-3PWB; LCSC Part C3029441
J204: Conn_01x04; custom_01x04_2.54; not fitted
J205, J206: Conn_01x02; custom_1x02_2.54; not fitted
L201: VLS3012HBX-1R0M; IND-SMD_L3.0-W3.0_VLS3012CX; LCSC Part C404493
L402: MPZ2012S221AT000; L0805; LCSC Part C76818
L407: RSCM7060-701; FILTER-SMD_4P-L7.0-W6.0-P3.00-TL; MPN RSCM7060-701; LCSC Part C32712963
Q201, Q202, Q203, Q204, Q206: AO3400A; SOT-23-3_L2.9-W1.3-P1.90-LS2.4-BR; LCSC Part C20917
R201, R209: 100kΩ; R_0402; Overload Voltage (Max) 50V; Tolerance ±1%; Part 0402WGF1003TCE; LCSC C25741
R202: 3kΩ; R_0603; Overload Voltage (Max) 75V; Tolerance ±1%; Part 0603WAF3001T5E; LCSC C4211
R208: 100Ω; R_0603; Overload Voltage (Max) 75V; Tolerance ±1%; Part 0603WAF1000T5E; LCSC C22775
R212: 220kΩ; R_0603; Overload Voltage (Max) 75V; Tolerance ±1%; Part 0603WAF2203T5E; LCSC C22961
R213, R214: 300Ω; R_0805; Overload Voltage (Max) 150V; Tolerance ±1%; Part 0805W8F3000T5E; LCSC C17617
R222: 5.1kΩ; R_0402; Overload Voltage (Max) 50V; Tolerance ±1%; Part 0402WGF5101TCE; LCSC C25905
R223: 150Ω; R_0603; Overload Voltage (Max) 75V; Tolerance ±1%; Part 0603WAF1500T5E; LCSC C22808
R224: 27kΩ; R_0603; Overload Voltage (Max) 75V; Tolerance ±1%; Part 0603WAF2702T5E; LCSC C22967
R225: 3.3kΩ; R_0402; Overload Voltage (Max) 50V; Tolerance ±1%; Part 0402WGF3301TCE; LCSC C25890
R424: 2.2Ω; R_0603; Overload Voltage (Max) 75V; Tolerance ±1%; Part 0603WAF220KT5E; LCSC C22939
TP407, TP408, TP409: TestPoint; TestPoint_Pad_D1.0mm
U202: BQ25792RQMR; QFN-29_L4.0-W4.0-P0.40-TL-BQ25792RQMR; LCSC Part C2862876

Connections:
/MCU/DN: D212.4 (I/O2), U202.7 (D-); also elsewhere on the board
/MCU/DP: D212.6 (I/O1), U202.6 (D+); also elsewhere on the board
/MCU/INT: U202.21 (~INT); also elsewhere on the board
/MCU/QON: U202.12 (~QON); also elsewhere on the board
/MCU/SCL: U202.14 (SCL); also elsewhere on the board
/MCU/SDA: U202.15 (SDA); also elsewhere on the board
/MCU/VSYS: C206.2, C207.2, C209.2, C210.2, J206.2, U202.25 (SYS); also elsewhere on the board
/PowerManagament/REGN: C201.2, R201.1, R212.2, R222.1, U202.5 (REGN)
/PowerManagament/Solar 5-20V: L407.3, Q203.3 (D), R424.2, U202.8 (VAC2)
/PowerManagament/TS: J202.2, R223.2, R224.1, TP409.1 (1_1), U202.16 (TS)
/PowerManagament/VBAT: J202.3, Q204.3 (D), R208.2, TP408.1 (1_1)
/PowerManagament/VBUS: C217.2, C218.2, C219.2, Q202.3 (D), Q206.3 (D), U202.2 (VBUS), U202.3 (VBUS)
/PowerManagament/VUSB: L402.1, Q201.3 (D), U202.9 (VAC1)
GND: C201.1, C202.1, C203.1, C204.1, C205.1, C206.1, C207.1, C208.1, C209.1, C210.1, C211.1, C212.1, C217.1, C218.1, C219.1, C417.1, D212.2 (GND), J201.1 (GND), J201.12 (GND), J201.13 (SHELL), J201.14 (SHELL), J202.1, J202.4, J202.5, J204.1, J206.1, L407.4, R202.2, R209.2, R225.2, TP407.1 (1_1), U202.13 (~CE), U202.27 (GND); also elsewhere on the board
unnamed: C417.2, R424.1
unnamed: D201.2, R201.2
unnamed: C220.1, D203.2 (A), Q201.2 (S), Q206.2 (S)
unnamed: C220.2, D203.1 (K), Q201.1 (G), Q206.1 (G), R214.2
unnamed: C221.1, D204.2 (A), Q202.2 (S), Q203.2 (S)
unnamed: C221.2, D204.1 (K), Q202.1 (G), Q203.1 (G), R213.1
unnamed: D212.5 (VBUS), J201.2 (VBUS), J201.11 (VBUS), J204.2, L402.2
unnamed: D401.2 (A), J205.1, L407.1
unnamed: D401.1 (K), J205.2, L407.2
unnamed: D212.3 (I/O2), J201.5 (DN2), J201.7 (DN1), J204.3
unnamed: D212.1 (I/O1), J201.6 (DP1), J201.8 (DP2), J204.4
unnamed: Q204.1 (G), U202.24 (SDRV)
unnamed: C211.2, C212.2, Q204.2 (S), U202.22 (BAT), U202.23 (BAT)
unnamed: R222.2, R223.1
unnamed: R224.2, R225.1
unnamed: R214.1, U202.11 (ACDRV1)
unnamed: R213.2, U202.10 (ACDRV2)
unnamed: C208.2, R208.1, U202.18 (BATP)
unnamed: C213.1, U202.4 (BTST1)
unnamed: C214.2, U202.19 (BTST2)
unnamed: R209.1, R212.1, U202.17 (ILIM_HIZ)
unnamed: C202.2, C203.2, C204.2, C205.2, U202.29 (PMID)
unnamed: R202.1, U202.20 (PROG)
unnamed: D201.1, U202.1 (STAT)
unnamed: C213.2, L201.1, U202.28 (SW1)
unnamed: C214.1, L201.2, U202.26 (SW2)

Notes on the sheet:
MCU Connection
max charge 3A
1s, 1.5mhz config
Battery with internal protection and ntc with Jst-phr-3p
OUTPUT at battery voltage
BQ25792 combined Charger
needs to be 150ohm ....

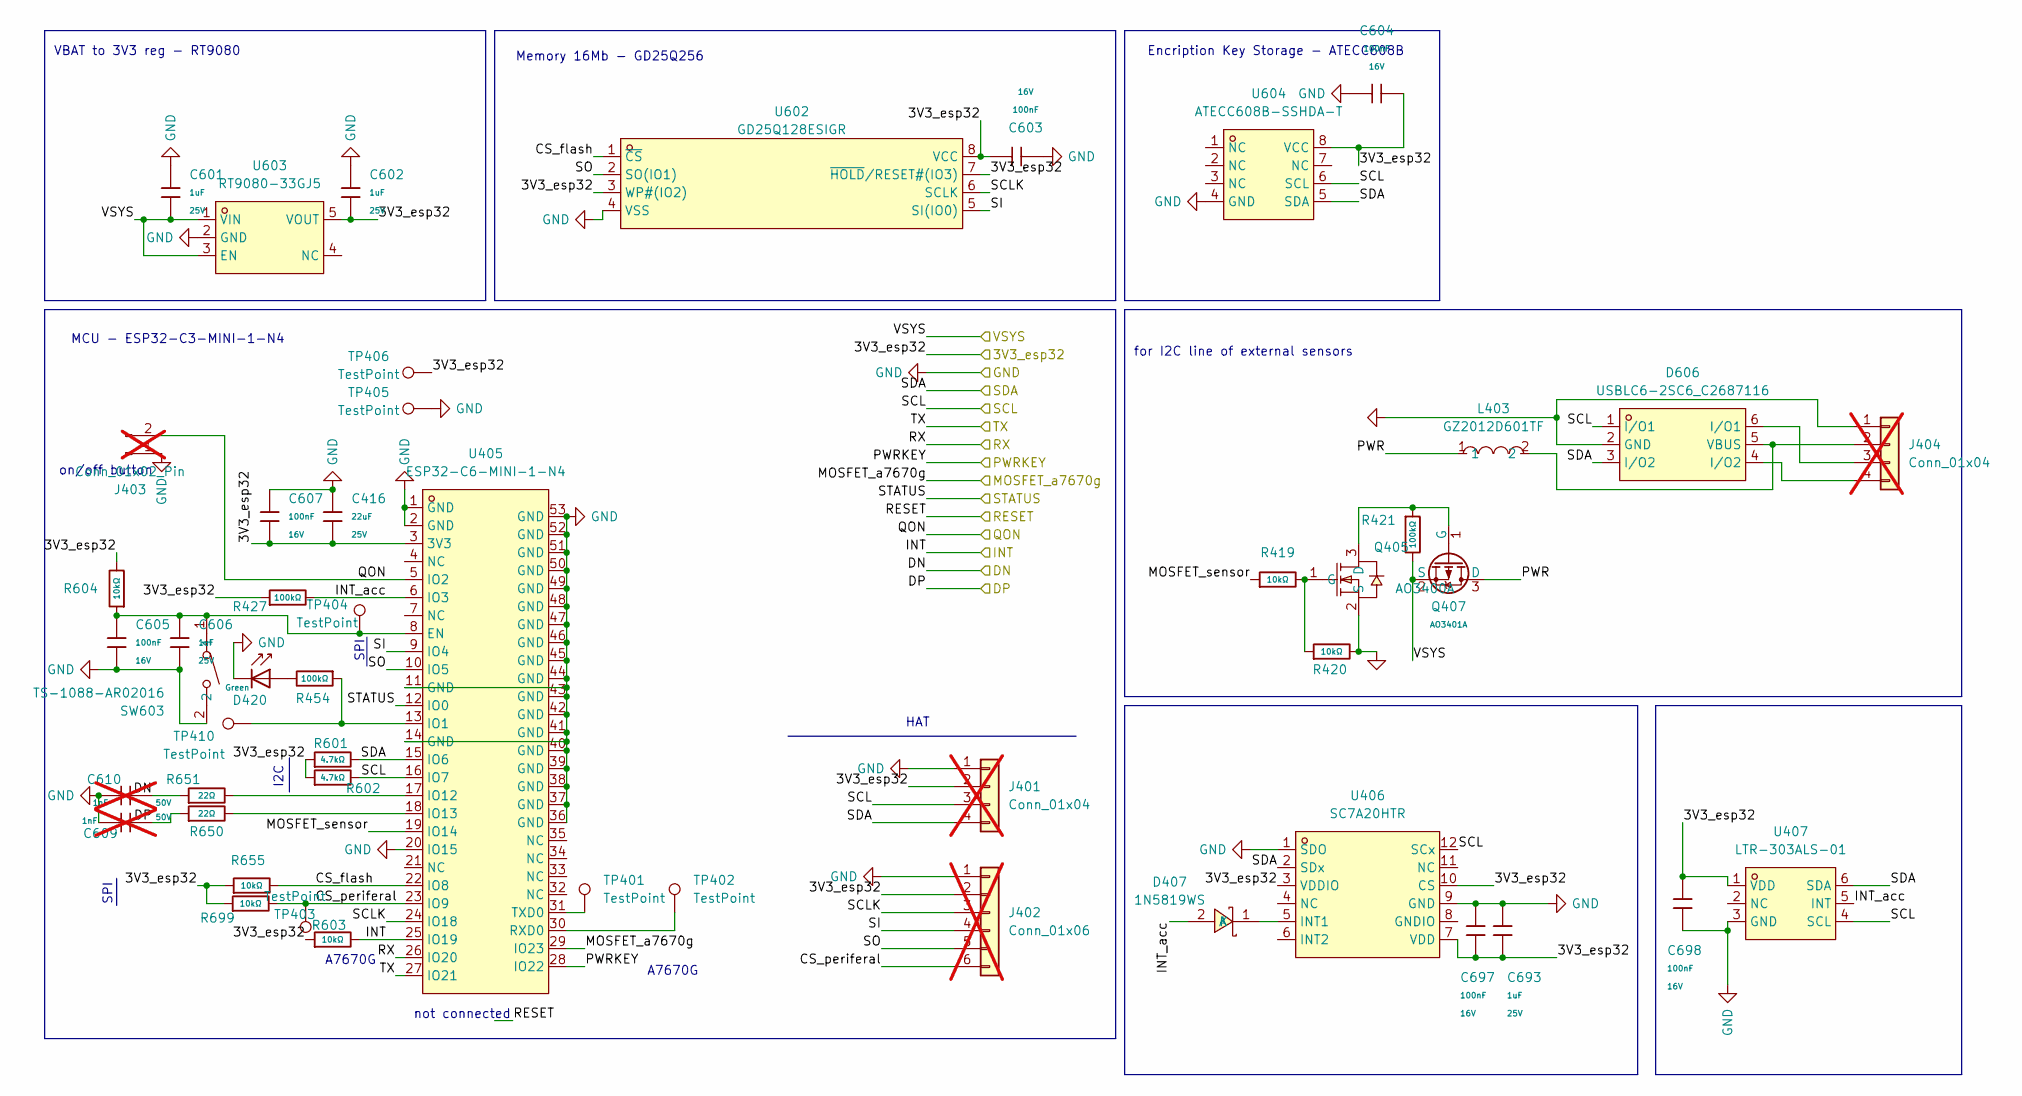
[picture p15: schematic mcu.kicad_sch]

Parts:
C416: 22uF; C_0805; Voltage Rated 25V; Tolerance ±20%; Part CL21A226MAQNNNE; LCSC C45783
C601, C602, C606, C693: 1uF; C_0402; Voltage Rated 25V; Tolerance ±10%; Part CL05A105KA5NQNC; LCSC C52923
C603, C604, C605, C607, C697, C698: 100nF; C_0402; Voltage Rated 16V; Tolerance ±10%; Part CL05B104KO5NNNC; LCSC C1525
C609, C610: 1nF; C_0402; Voltage Rated 50V; Tolerance ±10%; Part 0402B102K500NT; LCSC C1523; not fitted
D407: 1N5819WS; SOD-323_L1.8-W1.3-LS2.5-RD; MPN 1N5819WS; LCSC Part C191023
D420: Green; D_0805; Part KT-0805G; LCSC C2297
D606: USBLC6-2SC6_C2687116; SOT-23-6_L2.9-W1.6-P0.95-LS2.8-BL; LCSC Part C2687116
J401, J404: Conn_01x04; custom_01x04_2.54; not fitted
J402: Conn_01x06; custom_01x06_2.54; not fitted
J403: Conn_01x02_Pin; custom_1x02_2.54; not fitted
L403: GZ2012D601TF; L0805; MPN GZ2012D601TF; LCSC Part C1017
Q405: AO3400A; SOT-23-3_L2.9-W1.3-P1.90-LS2.4-BR; MPN AO3400A; LCSC Part C20917
Q407: AO3401A; Q_SOT-23; Part AO3401A; LCSC C15127
R419, R420, R603, R604, R655, R699: 10kΩ; R_0402; Overload Voltage (Max) 50V; Tolerance ±1%; Part 0402WGF1002TCE; LCSC C25744
R421, R427, R454: 100kΩ; R_0402; Overload Voltage (Max) 50V; Tolerance ±1%; Part 0402WGF1003TCE; LCSC C25741
R601, R602: 4.7kΩ; R_0402; Overload Voltage (Max) 50V; Tolerance ±1%; Part 0402WGF4701TCE; LCSC C25900
R650, R651: 22Ω; R_0402; Overload Voltage (Max) 50V; Tolerance ±1%; Part 0402WGF220JTCE; LCSC C25092
SW603: TS-1088-AR02016; SW-SMD_L3.9-W3.0-P4.45; LCSC Part C720477
TP401, TP402, TP403, TP404, TP405, TP406, TP410: TestPoint; TestPoint_Pad_D1.0mm
U405: ESP32-C6-MINI-1-N4; WIFIM-SMD_61P-L16.6-W13.2-P0.80-ESP32-C6-MINI-1-N4; LCSC Part C5736265
U406: SC7A20HTR; LGA-12_L2.0-W2.0-P0.50-TL; MPN SC7A20HTR; LCSC Part C19274408
U407: LTR-303ALS-01; TDFN-6_L2.0-W2.0-P0.65-BL; MPN LTR-303ALS-01; LCSC Part C364577
U602: GD25Q128ESIGR; SOP-8_L5.3-W5.3-P1.27-LS8.0-BL; LCSC Part C2928891
U603: RT9080-33GJ5; TSOT-23-5_L2.9-W1.6-P0.95-LS2.8-BL; LCSC Part C841192
U604: ATECC608B-SSHDA-T; SOIC-8_L4.9-W3.9-P1.27-LS6.0-BL; LCSC Part C1518769

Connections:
/MCU/3V3_esp32: C416.2, C602.2, C603.2, C604.2, C607.1, C693.2, C697.1, C698.2, J401.2, J402.2, R427.1, R601.1, R602.1, R603.1, R604.2, R655.1, R699.1, TP406.1 (1_1), U405.3 (3V3), U406.3 (VDDIO), U406.7 (VDD), U406.10 (CS), U407.1 (VDD), U602.3 (WP#(IO2)), U602.7 (~HOLD/RESET#(IO3)), U602.8 (VCC), U603.5 (VOUT), U604.8 (VCC); also elsewhere on the board
/MCU/CS_flash: R655.2, U405.22 (IO8), U602.1 (~CS)
/MCU/CS_periferal: J402.6, R699.2, TP403.1 (1_1), U405.23 (IO9)
/MCU/DN: C610.2, R651.1; also elsewhere on the board
/MCU/DP: C609.2, R650.1; also elsewhere on the board
/MCU/INT: R603.2, U405.25 (IO19); also elsewhere on the board
/MCU/INT_acc: D407.2 (A), R427.2, U405.6 (IO3), U407.5 (INT)
/MCU/MOSFET_a7670g: U405.29 (IO23); also elsewhere on the board
/MCU/MOSFET_sensor: R419.1, U405.19 (IO14)
/MCU/PWR: L403.1, Q407.3 (D)
/MCU/PWRKEY: U405.28 (IO22); also elsewhere on the board
/MCU/QON: J403.2, U405.5 (IO2); also elsewhere on the board
/MCU/RX: U405.26 (IO20); also elsewhere on the board
/MCU/SCL: D606.1 (I/O1), J401.3, R602.2, U405.16 (IO7), U406.12 (SCx), U407.4 (SCL), U604.6 (SCL); also elsewhere on the board
/MCU/SCLK: J402.3, U405.24 (IO18), U602.6 (SCLK)
/MCU/SDA: D606.3 (I/O2), J401.4, R601.2, U405.15 (IO6), U406.2 (SDx), U407.6 (SDA), U604.5 (SDA); also elsewhere on the board
/MCU/SI: J402.4, U405.9 (IO4), U602.5 (SI(IO0))
/MCU/SO: J402.5, U405.10 (IO5), U602.2 (SO(IO1))
/MCU/STATUS: U405.12 (IO0); also elsewhere on the board
/MCU/TX: U405.27 (IO21); also elsewhere on the board
/MCU/VSYS: C601.2, Q407.2 (S), R421.2, U603.1 (VIN), U603.3 (EN); also elsewhere on the board
GND: C416.1, C601.1, C602.1, C603.1, C604.1, C605.1, C606.2, C607.2, C609.1, C610.1, C693.1, C697.2, C698.1, D420.1, D606.2 (GND), J401.1, J402.1, J403.1, J404.1, Q405.2 (S), R420.2, SW603.2, TP405.1 (1_1), U405.1 (GND), U405.2 (GND), U405.11 (GND), U405.14 (GND), U405.20 (IO15), U405.36 (GND), U405.37 (GND), U405.38 (GND), U405.39 (GND), U405.40 (GND), U405.41 (GND), U405.42 (GND), U405.43 (GND), U405.44 (GND), U405.45 (GND), U405.46 (GND), U405.47 (GND), U405.48 (GND), U405.49 (GND), U405.50 (GND), U405.51 (GND), U405.52 (GND), U405.53 (GND), U406.1 (SDO), U406.9 (GND), U407.3 (GND), U602.4 (VSS), U603.2 (GND), U604.4 (GND); also elsewhere on the board
unnamed: D407.1 (K), U406.5 (INT1)
unnamed: D420.2, R454.2
unnamed: D606.5 (VBUS), J404.2, L403.2
unnamed: D606.6 (I/O1), J404.3
unnamed: D606.4 (I/O2), J404.4
unnamed: Q405.3 (D), Q407.1 (G), R421.1
unnamed: Q405.1 (G), R419.2, R420.1
unnamed: C605.2, C606.1, R604.1, SW603.1, TP404.1 (1_1), U405.8 (EN)
unnamed: R454.1, TP410.1 (1_1), U405.13 (IO1)
unnamed: R651.2, U405.17 (IO12)
unnamed: R650.2, U405.18 (IO13)
unnamed: TP402.1 (1_1), U405.30 (RXD0)
unnamed: TP401.1 (1_1), U405.31 (TXD0)

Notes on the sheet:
SPI
I2C
VBAT to 3V3 reg - RT9080
HAT
for I2C line of external sensors
A7670G
Memory 16Mb - GD25Q256
not connected
MCU - ESP32-C3-MINI-1-N4
on/off button
Encription Key Storage - ATECC608B

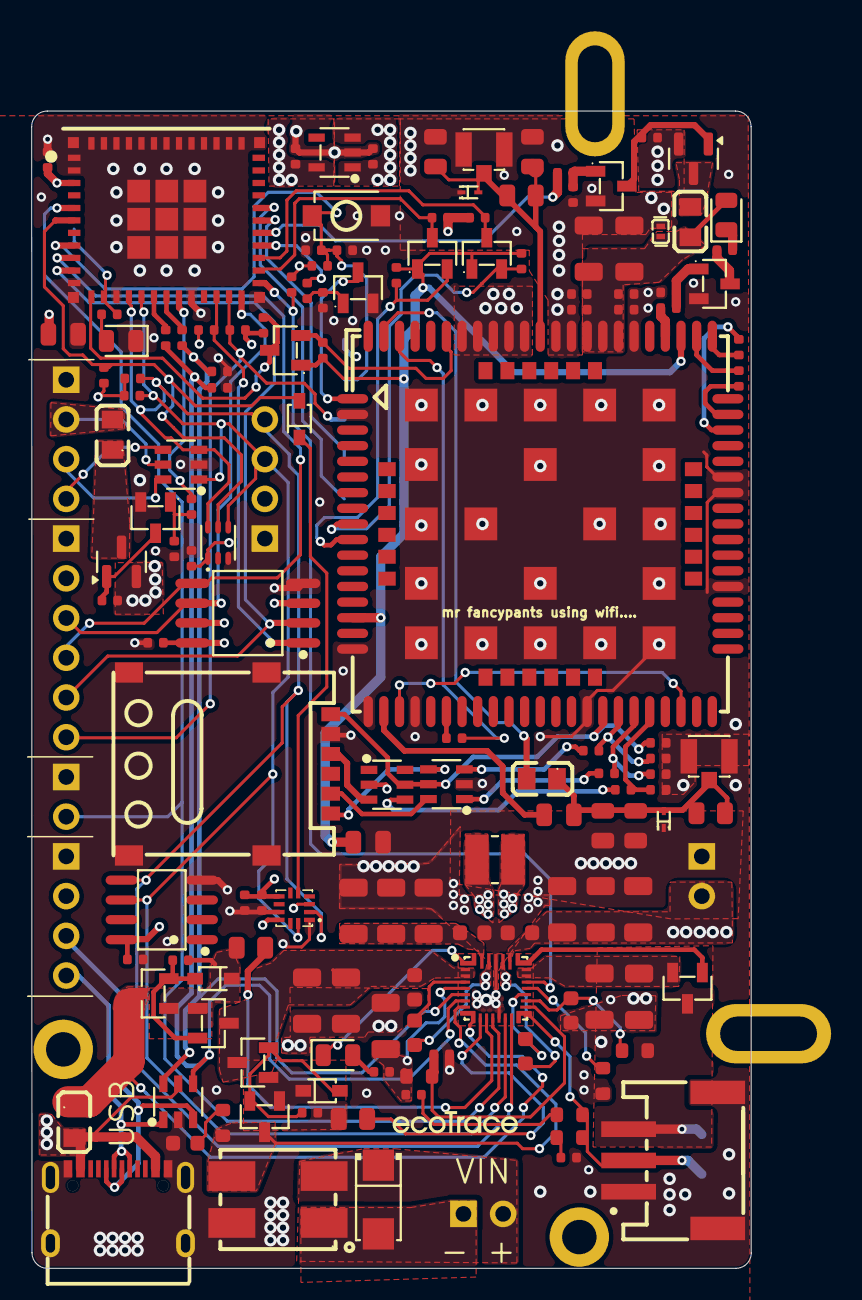
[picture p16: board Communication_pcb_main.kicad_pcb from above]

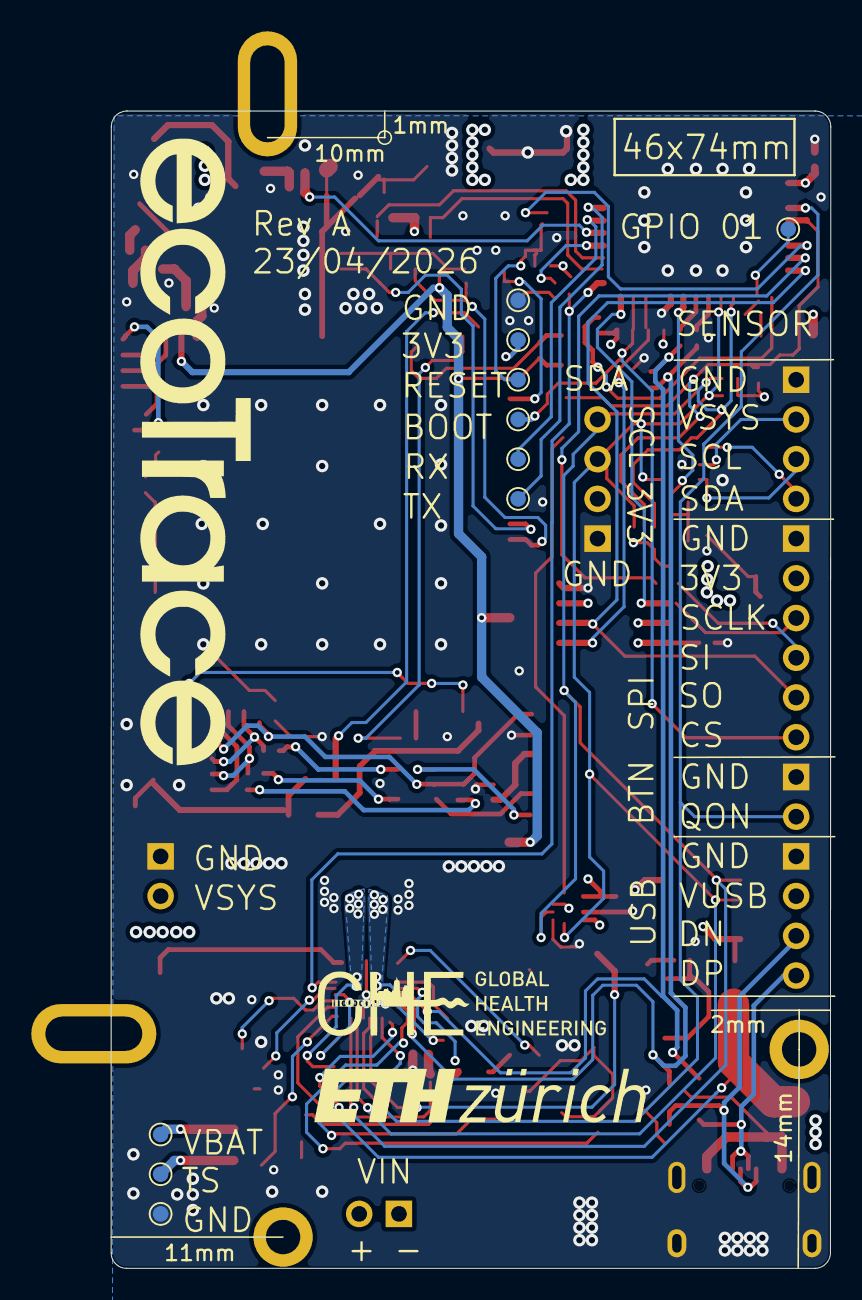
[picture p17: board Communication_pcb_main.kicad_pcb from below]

Board: 4 copper layers, 46.0 x 74.0 mm, 165 parts (10 on the bottom side), 102 nets.

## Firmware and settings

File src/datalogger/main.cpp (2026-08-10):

/*
 * ecoTrace datalogger
 * ===================
 * Solar-powered remote logger: samples everything every 5 minutes, stores to SPI
 * flash, uploads to ThingsBoard twice a day, deep-sleeps in between.
 *
 * Each wake:
 *   1. read the full battery/charger state (BQ25792) + the on-board I2C sensors
 *      (LTR-303 light, SC7A20 accel),
 *   2. run one solar-management pass (solar.cpp): MPPT step to maximise input
 *      power, per-day harvest accounting, and the weather-adaptive charge target
 *      (good weather -> stop at ~80 % SoC, bad weather -> allow 100 %),
 *   3. append one 64-byte record to the ring log on the 16 MB SPI flash
 *      (flash_log.cpp -- power-loss safe, ~2.5 years of capacity),
 *   4. if an upload is due (every 12 h, or first boot, with retry/backoff), drain
 *      the backlog to ThingsBoard: cellular first, WiFi backup (uplink.cpp),
 *      plus one device-health record. Every upload re-syncs the wall clock
 *      (modem NITZ / SNTP) -- the C6 sleep timer drifts, the 2x/day sync keeps
 *      timestamps honest.
 *   5. deep-sleep until the next sample (everything powered down; the BQ25792
 *      keeps charging autonomously with the settings we left it).
 *
 * Robustness: a task watchdog (WDT_TIMEOUT_S) reboots the board if any wake
 * hangs. RTC RAM survives such resets, so the log cursor and schedule carry on;
 * boot classification below distinguishes a clean timer wake, a crash reboot
 * (state intact -> count it, defer the upload, carry on), and a true cold boot
 * (RTC lost -> full re-init, recover the log from flash).
 *
 * Note on "constant" sampling: the C6's LP core could sample the LP-I2C sensors
 * while the HP core sleeps, but LP-core binaries can't be built in this
 * Arduino/PlatformIO toolchain -- so "constant" here means every wake. The
 * planned ESP-IDF port lifts that limitation.
 *
 * Config in config.h; credentials (SIM_APN, POST_URL, WIFI_*) in secrets.h.
 * Build/flash:  pio run -e datalogger -t upload && pio device monitor
 */
#include <Arduino.h>
#include "esp_random.h"
#include "esp_system.h"
#include "esp_task_wdt.h"
#include "esp_ota_ops.h"
#include "EcoTraceBoard.h"
#include "BQ25792.h"
#include "LTR303.h"
#include "SC7A20.h"
#include "MS5837.h"
#include "config.h"
#include "record.h"
#include "flash_log.h"
#include "solar.h"
#include "uplink.h"
#include "ota.h"
#include "timeutil.h"

/* ---- state that survives deep sleep (and crash reboots) ---- */
static constexpr uint32_t RTC_STATE_MAGIC = 0x8BADF00D;
static RTC_DATA_ATTR uint32_t s_rtc_magic;         /* valid-state sentinel */
static RTC_DATA_ATTR uint32_t s_uptime_s;          /* approx seconds since cold boot */
static RTC_DATA_ATTR uint32_t s_last_sleep_s;      /* duration of the sleep just ended */
static RTC_DATA_ATTR int32_t  s_next_upload_in_s;  /* countdown to the next upload */
static RTC_DATA_ATTR uint8_t  s_retries_left;
static RTC_DATA_ATTR uint8_t  s_boot_id;
/* health telemetry */
static RTC_DATA_ATTR uint16_t s_boot_count;
static RTC_DATA_ATTR uint16_t s_wake_count;
static RTC_DATA_ATTR uint16_t s_crash_count;       /* consecutive abnormal resets */
static RTC_DATA_ATTR uint16_t s_wdt_trips;
static RTC_DATA_ATTR uint16_t s_upload_fails;      /* consecutive failed attempts */
static RTC_DATA_ATTR uint16_t s_vbat_min_mv;       /* envelope since last upload */
static RTC_DATA_ATTR uint16_t s_vbat_max_mv;
static RTC_DATA_ATTR uint32_t s_awake_ms;          /* awake time since last upload */
static RTC_DATA_ATTR uint8_t  s_upload_inflight;   /* set around uploadAll(): if a crash
                                                    * reboot sees it, the upload (likely
                                                    * the modem burst) caused the crash */
static RTC_DATA_ATTR uint8_t  s_upload_crashed;    /* -> next attempt skips cellular ONCE;
                                                    * cellular stays the primary path */

BQ25792  bq;
LTR303   light;
SC7A20   accel;
MS5837   baro;
FlashLog flog;

/* Watch the whole wake: if anything hangs, panic-reboot instead of draining the
 * battery at run current. Long stages feed it at checkpoints. */
static void wdtBegin()
{
    esp_task_wdt_config_t cfg = {};
    cfg.timeout_ms    = (uint32_t)WDT_TIMEOUT_S * 1000;
    cfg.idle_core_mask = 0;
    cfg.trigger_panic = true;
    if (esp_task_wdt_init(&cfg) != ESP_OK)   /* already running (Arduino default) */
        esp_task_wdt_reconfigure(&cfg);
    esp_task_wdt_add(NULL);
}

/* Very crude 1S LiPo SoC from voltage. Good enough for thresholds + trends. */
static uint8_t socFromVoltage(uint16_t vbat_mv)
{
    if (vbat_mv >= 4200) return 100;
    if (vbat_mv <= 3300) return 0;
    return (uint8_t)((vbat_mv - 3300) * 100 / (4200 - 3300));
}

static void readSample(LogRecord& r, const Solar::Status& sol)
{
    memset(&r, 0xFF, sizeof(r));   /* spare bytes stay 0xFF (NOR-friendly) */

    r.ts_s     = clockValid() ? (uint32_t)time(nullptr) : 0;
    r.uptime_s = s_uptime_s;
    r.boot_id  = s_boot_id;

    r.vbat_mv   = bq.readVbat_mV();
    r.ibat_ma   = bq.readIbat_mA();
    r.vbus_mv   = bq.readVbus_mV();
    r.ibus_ma   = bq.readIbus_mA();
    r.vac2_mv   = bq.readVac2_mV();
    r.vsys_mv   = bq.readVsys_mV();
    r.chg_stat  = (uint8_t)bq.chargeState();
    bq.readFaults(r.fault0, r.fault1);
    r.soc_pct   = socFromVoltage(r.vbat_mv);

    r.vindpm_mv   = sol.vindpm_mv;
    r.vreg_mv     = sol.vreg_mv;
    r.harvest_mah = sol.harvest_today_mah;
    r.flags = (sol.solar_present ? RECF_SOLAR   : 0) |
              (sol.usb_present   ? RECF_USB     : 0) |
              (sol.weather_good  ? RECF_WEATHER : 0) |
              (sol.eco_target    ? RECF_ECO_CHG : 0);

    /* On-board I2C sensors (always-on 3V3 rail; low-powered between reads). */
    r.light_ch0 = r.light_ch1 = 0;
    if (light.begin()) {
        delay(120);   /* one ALS integration period after leaving standby */
        uint16_t c0, c1;
        if (light.read(c0, c1)) { r.light_ch0 = c0; r.light_ch1 = c1; }
        light.powerDown();
    }
    r.acc_mg[0] = r.acc_mg[1] = r.acc_mg[2] = 0;
    if (accel.begin()) {
        delay(20);    /* first sample at 100 Hz */
        int16_t ax, ay, az;
        if (accel.readMilliG(ax, ay, az)) {
            r.acc_mg[0] = ax; r.acc_mg[1] = ay; r.acc_mg[2] = az;
        }
        accel.powerDown();
    }

    /* MS5837 barometer on the I2C hat header (always-on rail, ~0.1 uA idle --
     * nothing to power down). Optional: zeros if not fitted. */
    r.press_dmbar = 0;
    r.temp_cC     = 0;
    if (baro.begin()) {
        float mbar, degC;
        if (baro.read(mbar, degC)) {           /* blocks ~40 ms */
            r.press_dmbar = (uint16_t)(mbar * 10.0f + 0.5f);
            r.temp_cC     = (int16_t)(degC * 100.0f + (degC >= 0 ? 0.5f : -0.5f));
        }
    }
}

/* QON button (GPIO2, shared with the BQ25792's QON input; external pull-up,
 * button pulls low). Short press while asleep = wake for an immediate sample.
 * BUTTON_OTA_PRESSES presses in a row = WiFi OTA mode (testing convenience).
 * Held BUTTON_SHIP_HOLD_MS = power off via BQ ship mode (BATFET opens,
 * ~129 uA); wake by holding the button ~1 s (BQ tSM_EXIT). A ~10 s hold
 * triggers the BQ's own hardware power cycle regardless of firmware.
 *
 * Presses 2..n of a multi-press land while the firmware is still booting
 * (~0.5-1 s of init before handleButton runs), so earlyButtonWatch() hangs an
 * interrupt on the pin in the very first lines of setup() to catch them; only
 * the ~300 ms ROM-loader window is truly blind. */
static volatile uint32_t s_btn_isr_last_ms;
static volatile uint8_t  s_btn_isr_presses;

static void IRAM_ATTR buttonIsr()
{
    uint32_t now = millis();
    if (now - s_btn_isr_last_ms > 120)   /* debounce; also swallows the wake
                                          * press's release bounce right after
                                          * attach (last_ms starts at 0) */
        s_btn_isr_presses = s_btn_isr_presses + 1;
    s_btn_isr_last_ms = now;
}

static void earlyButtonWatch(void)
{
    pinMode(ECO_PIN_QON, INPUT);
    attachInterrupt(digitalPinToInterrupt(ECO_PIN_QON), buttonIsr, FALLING);
}

/* Returns the short-press count (0 = button not involved in this wake). A short
 * press means "sample AND phone home now" -- handy on the bench and in the
 * field to check a unit is alive without waiting for the 12 h schedule. */
static uint8_t handleButton(void)
{
    detachInterrupt(digitalPinToInterrupt(ECO_PIN_QON));
    uint8_t early = s_btn_isr_presses;

    if (!EcoTrace::wokeFromButton() && early == 0 && digitalRead(ECO_PIN_QON) == HIGH)
        return 0;
    /* the wake press itself + whatever the boot-time interrupt caught */
    uint8_t presses = (EcoTrace::wokeFromButton() ? 1 : 0) + early;
    if (presses == 0) presses = 1;   /* pin low at a non-button boot */

    /* If that press is still held, watch for the ship-mode hold. */
    uint32_t t0 = millis();
    while (digitalRead(ECO_PIN_QON) == LOW) {
        if (millis() - t0 >= BUTTON_SHIP_HOLD_MS) {
            /* "armed" feedback: flicker off-on against the steady awake LED */
            for (int i = 0; i < 3; i++) {
                EcoTrace::ledOff(); delay(80);
                EcoTrace::ledOn();  delay(80);
            }
            Serial.println("button held: release to power off");
            Serial.flush();
            /* QON low for ~1 s is the BQ's wake-FROM-ship signal, so never
             * command ship mode while the button is still down. */
            while (digitalRead(ECO_PIN_QON) == LOW) delay(10);
            delay(150);          /* debounce + let QON settle high */
            bq.enterShipMode();  /* sets SFET_PRESENT; battery disconnects here */
            delay(1200);

            /* Only reached with an adapter attached: ship mode needs no input
             * present, so the charger refused. The board is still on VBUS and
             * will power off as soon as the cable is pulled -- but it would
             * also wake on the next plug-in, so just resume normal logging. */
            Serial.println("still powered (adapter present) -- unplug to finish power-off");
            for (int i = 0; i < 3; i++) {
                EcoTrace::ledOff(); delay(150);
                EcoTrace::ledOn();  delay(150);
            }
            EcoTrace::ledOff();
            EcoTrace::deepSleepSeconds(SAMPLE_INTERVAL_S);
        }
        delay(10);
    }

    /* Count further presses; each one restarts the window. The boot after the
     * wake press takes a few hundred ms, so "press 3x" in a normal rhythm lands
     * presses 2 and 3 in here. */
    uint32_t window_end = millis() + BUTTON_MULTIPRESS_WINDOW_MS;
    while ((int32_t)(window_end - millis()) > 0 && presses < BUTTON_OTA_PRESSES) {
        if (digitalRead(ECO_PIN_QON) == LOW) {
            delay(30);                                    /* debounce */
            if (digitalRead(ECO_PIN_QON) == LOW) {
                presses++;
                EcoTrace::ledOn(); delay(30); EcoTrace::ledOff();   /* press feedback */
                while (digitalRead(ECO_PIN_QON) == LOW) delay(10);  /* wait for release */
                window_end = millis() + BUTTON_MULTIPRESS_WINDOW_MS;
            }
        }
        delay(5);
    }

    if (presses >= BUTTON_OTA_PRESSES) {
        Serial.printf("button: %u presses - WiFi OTA mode\n", presses);
        Ota::runWindow();   /* reboots on a successful push, else returns */
        return 0;           /* OTA window done -- no forced upload on top */
    }
    Serial.printf("button: %u press(es) - extra sample + upload\n", presses);
    return presses;
}

void setup()
{
    earlyButtonWatch();   /* first thing: catch multi-press taps during init */
    Serial.begin(115200);
    wdtBegin();

    /* Boot classification: clean timer wake / crash reboot with RTC state intact /
     * true cold boot (power-on, RTC RAM lost). */
    bool timer_wake  = EcoTrace::wokeFromTimer();
    bool button_wake = EcoTrace::wokeFromButton();
    bool cold        = (s_rtc_magic != RTC_STATE_MAGIC);
    bool crashed     = !cold && !timer_wake && !button_wake;
    esp_reset_reason_t why = esp_reset_reason();

    if (cold) delay(1500);   /* give USB CDC time to enumerate on the bench only */

    EcoTrace::beginBoard();
#if LED_SHOW_AWAKE
    EcoTrace::ledOn();      /* stays on until deepSleepSeconds() latches it off */
#endif
    EcoTrace::beginI2C();
    EcoTrace::beginSPI();
    Serial.printf("ecoTrace datalogger %s (%s slot)\n", FW_VERSION,
                  esp_ota_get_running_partition()->label);

    uint8_t button_presses = handleButton();

    if (cold) {
        s_uptime_s         = 0;
        s_last_sleep_s     = 0;
        s_next_upload_in_s = 0;          /* upload (and clock-sync) on first boot */
        s_retries_left     = UPLOAD_MAX_RETRIES;
        s_boot_id          = (uint8_t)esp_random();
        s_boot_count       = 0;
        s_wake_count       = 0;
        s_crash_count      = 0;
        s_wdt_trips        = 0;
        s_upload_fails     = 0;
        s_vbat_min_mv      = 0xFFFF;
        s_vbat_max_mv      = 0;
        s_awake_ms         = 0;
        s_upload_inflight  = 0;
        s_upload_crashed   = 0;
        Solar::reset();
        s_rtc_magic = RTC_STATE_MAGIC;
        Serial.printf("cold boot (id %u, reset reason %d)\n", s_boot_id, (int)why);
        /* Cold boot (e.g. waking from ship mode with no serial attached): hold
         * the LED solid for a few seconds so it is unmistakable. */
        EcoTrace::ledOn();
        delay(3000);
    } else if (crashed) {
        /* The previous wake died (watchdog, panic, brownout, manual reset). Keep
         * all state, note it, and don't retry the likely culprit immediately. */
        s_crash_count++;
        if (why == ESP_RST_TASK_WDT || why == ESP_RST_INT_WDT ||
            why == ESP_RST_WDT || why == ESP_RST_PANIC)
            s_wdt_trips++;
        if (s_upload_inflight) {   /* the upload (modem burst?) killed us */
            s_upload_crashed  = 1;
            s_upload_inflight = 0;
        }
        if (s_next_upload_in_s <= 0) s_next_upload_in_s = UPLOAD_RETRY_S;
        Serial.printf("recovered from abnormal reset (reason %d, %u in a row)\n",
                      (int)why, s_crash_count);
    } else {
        s_wake_count++;
        if (timer_wake) {
            /* A button wake cuts the sleep short by an unknown amount, so leave
             * the uptime/upload bookkeeping to the timer wakes only. */
            s_uptime_s         += s_last_sleep_s;
            s_next_upload_in_s -= (int32_t)s_last_sleep_s;
        }
    }
    s_boot_count++;

    /* After a crash the log cursors in RTC RAM may predate a half-finished
     * append -- re-recover from the chip in that case (cheap). */
    if (!flog.begin(cold || crashed))
        Serial.println("WARNING: SPI flash not found -- samples will be lost!");

    /* Charger up: ADC on, profile applied (VREG is set by the solar manager). */
    Solar::Status sol = {};
    bool bq_ok = bq.begin();
    if (bq_ok) {
        bq.enableADC();
        bq.enableIbatSensing();
        bq.configureCharging(CHARGE_CURRENT_MA, 0 /* set per source below */, 0);
        bq.enableACDRV1(true);   /* USB path gate is off at POR */
        bq.enableACDRV2(true);   /* solar path gate */
        sol = Solar::onWake(bq, SAMPLE_INTERVAL_S, localDayNum());
    } else {
        Serial.println("WARNING: BQ25792 not found -- battery data will be zero.");
    }
    esp_task_wdt_reset();

    /* Sample -> flash. */
    LogRecord r;
    readSample(r, sol);
    flog.append(r);
    if (r.vbat_mv) {
        if (r.vbat_mv < s_vbat_min_mv) s_vbat_min_mv = r.vbat_mv;
        if (r.vbat_mv > s_vbat_max_mv) s_vbat_max_mv = r.vbat_mv;
    }
    Serial.printf("seq %lu: VBAT=%umV IBAT=%+dmA SOC=%u%% | in: %s VINDPM=%umV "
                  "IBUS=%dmA | harvest %umAh (prev %u) weather=%s target=%umV | "
                  "lux0=%u acc=[%d,%d,%d] P=%.1fmbar T=%.2fC | pending %lu\n",
                  (unsigned long)r.seq, r.vbat_mv, r.ibat_ma, r.soc_pct,
                  sol.usb_present ? "USB" : sol.solar_present ? "solar" : "none",
                  r.vindpm_mv, r.ibus_ma,
                  sol.harvest_today_mah, sol.harvest_prev_mah,
                  sol.weather_good ? "good" : "bad", r.vreg_mv,
                  r.light_ch0, r.acc_mg[0], r.acc_mg[1], r.acc_mg[2],
                  r.press_dmbar / 10.0f, r.temp_cC / 100.0f,
                  (unsigned long)flog.pendingCount());
    esp_task_wdt_reset();

    /* A short button press means "phone home now". */
    if (button_presses > 0) s_next_upload_in_s = 0;

    /* Upload if due -- and only if the battery can afford the modem burst. */
    if (s_next_upload_in_s <= 0) {
        bool can_afford = r.vbat_mv >= UPLOAD_MIN_VBAT_MV ||
                          sol.usb_present || sol.solar_present;
        if (!can_afford) {
            Serial.println("upload due but battery low -- deferring");
            s_next_upload_in_s = UPLOAD_RETRY_S;
        } else {
            Uplink::StatusInfo si = {};
            si.boot_id      = s_boot_id;
            si.reset_reason = (uint8_t)why;
            si.boot_count   = s_boot_count;
            si.wake_count   = s_wake_count;
            si.crash_count  = s_crash_count;
            si.wdt_trips    = s_wdt_trips;
            si.upload_fails = s_upload_fails;
            si.vbat_min_mv  = (s_vbat_min_mv == 0xFFFF) ? 0 : s_vbat_min_mv;
            si.vbat_max_mv  = s_vbat_max_mv;
            si.awake_ms     = s_awake_ms + millis();
            si.uptime_s     = s_uptime_s;

            s_upload_inflight = 1;
            Uplink::Result u = Uplink::uploadAll(flog, SAMPLE_INTERVAL_S, si,
                                                 s_upload_crashed != 0);
            s_upload_inflight = 0;
            s_upload_crashed  = 0;   /* one-shot: cellular is primary again */
            if (u.all_sent) {
                s_next_upload_in_s = UPLOAD_PERIOD_S;
                s_retries_left     = UPLOAD_MAX_RETRIES;
                s_upload_fails     = 0;
                s_vbat_min_mv = s_vbat_max_mv = r.vbat_mv ? r.vbat_mv : s_vbat_max_mv;
                if (!r.vbat_mv) s_vbat_min_mv = 0xFFFF;
                s_awake_ms = 0;
            } else {
                s_upload_fails++;
                if (s_retries_left > 0) {
                    s_retries_left--;
                    s_next_upload_in_s = UPLOAD_RETRY_S;
                } else {
                    s_next_upload_in_s = UPLOAD_PERIOD_S;   /* give up until next slot */
                    s_retries_left     = UPLOAD_MAX_RETRIES;
                }
            }
        }
    }

    /* Everything down, then sleep. Charging continues autonomously. */
    if (bq_ok) {
        bq.disableADC();
        bq.enableIbatSensing(false);   /* EN_IBAT costs charger quiescent; nothing
                                        * reads IBAT while we sleep. Re-enabled
                                        * next wake before sampling. */
    }
    flog.sleep();

    uint32_t sleep_s = SAMPLE_INTERVAL_S;
    if (r.vbat_mv && r.vbat_mv < CRITICAL_VBAT_MV && !sol.usb_present && !sol.solar_present)
        sleep_s = SAMPLE_INTERVAL_S * CRITICAL_INTERVAL_MULT;
    if (s_crash_count >= CRASH_SLOWDOWN_COUNT)
        sleep_s = SAMPLE_INTERVAL_S * CRITICAL_INTERVAL_MULT;   /* containment */

    /* Reaching this point = the wake completed; the crash streak is over. */
    s_crash_count  = 0;
    s_awake_ms    += millis();
    s_uptime_s    += millis() / 1000;   /* count awake time into uptime too */
    s_last_sleep_s = sleep_s;

    Serial.printf("sleeping %lus (next upload in %lds)\n",
                  (unsigned long)sleep_s, (long)s_next_upload_in_s);
    Serial.flush();
    EcoTrace::deepSleepSeconds(sleep_s);   /* never returns */
}

void loop() {}

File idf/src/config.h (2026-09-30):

/*
 * config.h  --  tunables for the ESP-IDF datalogger.
 * Values carried over from the hardware-validated Arduino build
 * (src/datalogger/config.h), plus the field-robustness floors agreed 2026-08-11.
 */
#pragma once

/* FW_VERSION is NOT defined here since com-0.36. It comes from idf/version.txt:
 * ESP-IDF reads that file into PROJECT_VER, which lands in the image's app
 * descriptor, and src/CMakeLists.txt passes the same string in as FW_VERSION.
 * One source, so the version the server reads out of an uploaded image and the
 * one the board reports in "fw" can never disagree. Bump version.txt and
 * TOUCH idf/CMakeLists.txt: PlatformIO re-runs CMake (where version.txt is
 * read) only when a CMakeLists changes, so a bump alone rebuilds the old
 * version. Check the descriptor of the .bin (offset 0x30) when in doubt. (Scheme renamed idf-x.y -> com-x.y at 0.34; numbering continues.) */
#ifndef FW_VERSION
#error "FW_VERSION comes from idf/version.txt via src/CMakeLists.txt -- build from idf/"
#endif

/* DEBUG ONLY -- pad the flash log up to this many pending records so a drain
 * can be timed without waiting 12 h for a real backlog. 0 disables.
 *
 * 120 is chosen to match the real thing: the 3-day soak showed cycles starting
 * with 80-128 pending, and the drain cost is what we are measuring, so the
 * count has to be representative rather than convenient.
 *
 * MUST be 0 for any real soak. With it set, every cold boot tops the log back
 * up to the target and uploads duplicate rows. */
#define ECO_FAKE_BACKLOG        0

/* ---- Duty cycle ----
 * COMPILED DEFAULTS. Since com-0.35 both are remotely configurable (devcfg.c,
 * retained MQTT config): code must read devcfg_sample_s() / devcfg_upload_s(),
 * not these. They apply until the first config payload arrives. */
#define SAMPLE_INTERVAL_S       300     /* 5 min */
#define UPLOAD_PERIOD_S         (12 * 3600)
#define CRITICAL_VBAT_MV        3350
#define CRITICAL_INTERVAL_MULT  6       /* -> 30 min when critical */

/* ---- Battery floors (A7672 needs >=3.4 V at the pin under 2 A bursts;
 * RT9080 dropout wants margin for the ESP) ---- */
#define MODEM_MIN_VBAT_MV       3600    /* no cellular attempts below (resting) */
#define WIFI_MIN_VBAT_MV        3450    /* no WiFi attempts below */
#define PARK_VBAT_MV            3300    /* full park: no flash, no sensors */
#define PARK_RESUME_VBAT_MV     3450    /* hysteresis */
#define PARK_SLEEP_S            3600    /* recheck cadence while parked */

/* ---- Charge profile (BQ25792, 1S LiPo) ---- */
#define VREG_FULL_MV            4200
#define VREG_ECO_MV             4050    /* ~80 % SoC resting */
#define CHARGE_CURRENT_MA       1000
#define INPUT_LIMIT_USB_MA      2000
#define INPUT_LIMIT_SOLAR_MA    3000
#define USB_VINDPM_MV           4400

/* ---- Solar MPPT (fractional-Voc + P&O), validated on hardware ---- */
#define MPPT_FOC_PCT            80
#define MPPT_VOC_PERIOD_WAKES   12
#define MPPT_VOC_SETTLE_MS      250
#define MPPT_COLLAPSE_MA        30
#define MPPT_STEPS_PER_WAKE     3
#define MPPT_STEP_MV            100
#define MPPT_SETTLE_MS          150
#define MPPT_VINDPM_START_MV    14000
#define MPPT_VINDPM_MIN_MV      5000
#define MPPT_VINDPM_MAX_MV      22000

/* ---- Weather detection ----
 * Two independent signals, either one declares the day "good":
 *  - harvest (charge actually drawn): catches sunny days while the battery
 *    still wants charge;
 *  - Voc sun-hours: hourly open-circuit panel voltage >= SUN_FRACTION_PCT of
 *    the self-calibrating max (NVS-persisted) -- catches sunny days when a
 *    full battery makes harvest blind (the 2026-08-12 finding). Voc is a
 *    daylight detector, not an intensity meter (logarithmic in light,
 *    -0.3 %/C in temperature), hence the loose fraction. */
#define WEATHER_GOOD_MAH        1000
#define SUN_FRACTION_PCT        80
#define SUN_HOURS_GOOD          4
#define TZ_OFFSET_MIN           120     /* local day rollover (CEST) */
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

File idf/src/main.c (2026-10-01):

/*
 * ecoTrace datalogger -- ESP-IDF port.
 *
 * Milestone: LOGGING PARITY with the hardware-validated Arduino build
 * (src/datalogger, frozen at dl-2.14). Each wake: full battery/charger state +
 * all three I2C sensors -> one 64 B record into the flash ring -> deep sleep.
 * Includes the field-robustness battery floors + park mode (2026-08-11 spec).
 *
 * NOT yet ported (next milestones, in order):
 *   - uplink: esp_modem PPP + esp-mqtt + mbedTLS (fail-closed, no plaintext),
 *     registration diagnostics, bounded escalation ladder
 *   - error-event log (coredump partition), health telemetry
 *   - OTA with rollback, NVS provisioning, ATECC identity, LP-core sampling
 */
#include <string.h>
#include <time.h>

#include "esp_attr.h"
#include "esp_log.h"
#include "esp_ota_ops.h"
#include "esp_random.h"
#include "esp_sleep.h"
#include "esp_system.h"
#include "esp_task_wdt.h"
#include "esp_pm.h"   /* reproduction experiment 2026-09-14 -- see sdkconfig */
#include "freertos/FreeRTOS.h"
#include "freertos/task.h"

#include "config.h"
#include "board.h"
#include "record.h"
#include "flash_log.h"
#include "ext_flash.h"
#include "bq25792.h"
#include "solar.h"
#include "sensors.h"
#include "uss.h"
#include "uss_link.h"
#include "gasflow.h"
#include "i2c_bus.h"
#include "devcfg.h"
#include "ota.h"
#include "esp_timer.h"
#include "wf280a.h"
#include "uplink.h"

static const char *TAG = "ecotrace";

/* When the switched SENSOR rail came up this wake; the ultrasonic module needs
 * BOARD_SENSOR_BOOT_MS from that point before its I2C slave answers. */
static int64_t s_sensor_up_us;

/* True only when THIS wake actually powered the module up (cold boot, or a
 * recovery power cycle). On a timer wake the SENSOR rail was held on through
 * deep sleep and the module has been running for hours, so there is no boot to
 * wait out. Gating on the FLAG, not on the timestamp: esp_timer_get_time()
 * restarts at 0 every boot, so leaving s_sensor_up_us unstamped makes
 * elapsed_ms ~= the current uptime (~500 ms), which is still < 3000 and waits
 * anyway. That mistake cost a measurement cycle on 2026-09-15. */
static bool s_sensor_cold_up;

/* ---- state surviving deep sleep (and crash reboots) ---- */
#define RTC_STATE_MAGIC 0x8BADF00Du
static RTC_DATA_ATTR uint32_t s_rtc_magic;
static RTC_DATA_ATTR uint32_t s_uptime_s;
static RTC_DATA_ATTR uint32_t s_last_sleep_s;
static RTC_DATA_ATTR uint8_t  s_boot_id;
static RTC_DATA_ATTR uint16_t s_boot_count;
static RTC_DATA_ATTR uint16_t s_wake_count;
static RTC_DATA_ATTR uint16_t s_crash_count;
static RTC_DATA_ATTR uint8_t  s_parked;      /* battery park mode latch */
/* upload scheduling: bounded tempo (2026-08-11 spec) */
static RTC_DATA_ATTR int32_t  s_next_upload_in_s;

/* Module link health for the status record. Plain statics, not RTC_DATA_ATTR:
 * they are re-read every wake and only ever used within the same wake. */
static bool     s_uss_health_valid;
static uint16_t s_uss_rst_cause;
static uint16_t s_uss_lh_starts;
static uint16_t s_uss_lh_uptime_s;

/* Module preset (gas-dependent capture window, gain, pulses, tones) for this
 * MODULE boot. The settings persist in module FRAM, so checking them every wake
 * would only burn awake time; they can only change when the module restarts
 * (a reflash resets them to compiled defaults) or when this board has lost its
 * RTC state. -1 not yet tried, 0 failed, 1 in place. A failure is retried on
 * the next wakes, but at most PRESET_TRIES times per module boot: a module
 * firmware without PARAM support never answers, and a retry every wake would
 * cost a 3 s timeout at 16 mA 288 times a day. */
#define PRESET_TRIES 3
RTC_DATA_ATTR static int8_t   s_uss_preset = -1;
RTC_DATA_ATTR static uint8_t  s_uss_preset_tries;

/* Which preset the last sync was for. A reflash with a different cell, gas or
 * constant set must re-sync even when RTC state survived the reset: otherwise a
 * board moved from the 75 mm to the 44 mm profile keeps the 75 mm capture
 * window (140 us), which opens after the 44 mm echo and blinds the module. */
#define PRESET_KEY ((uint32_t) USS_CELL << 16 | (uint32_t) USS_GAS_PROFILE << 8 | GF_DERIVE_VER)
RTC_DATA_ATTR static uint32_t s_uss_preset_key;

/* Last uss_seq we published, for stale-frame detection. RTC_DATA_ATTR so the
 * check survives deep sleep -- the fault it looks for lasted ten hours, i.e.
 * ~120 wakes, so a check that reset every wake would never have seen it. */
RTC_DATA_ATTR static uint16_t s_uss_seq_prev;
RTC_DATA_ATTR static bool     s_uss_seq_valid;
RTC_DATA_ATTR static uint16_t s_uss_stale_n;
static RTC_DATA_ATTR uint8_t  s_retries_left;
static RTC_DATA_ATTR uint32_t s_last_deep_uptime;   /* deep search once/day */
static RTC_DATA_ATTR uint8_t  s_upload_inflight;
static RTC_DATA_ATTR uint8_t  s_upload_crashed;

#define UPLOAD_RETRY_S  (30 * 60)
#define UPLOAD_RETRIES  2

static uint8_t soc_from_voltage(uint16_t vbat_mv)
{
    if (vbat_mv >= 4200) return 100;
    if (vbat_mv <= 3300) return 0;
    return (uint8_t)((vbat_mv - 3300) * 100 / (4200 - 3300));
}

/* Bring the module's gas-dependent settings to the profile's values.
 *
 * GET first, SET only what differs: on a module already running the profile
 * (the normal case -- the compiled biogas defaults ARE the biogas preset) this
 * writes nothing, so FRAM is untouched and bench tuning is not silently
 * overwritten by a board that merely rebooted. Every SET is verified by the
 * value the module reports back as in effect. */
static bool preset_get(uint8_t id, const char *name, int32_t *have)
{
    uint8_t st = 0xFF;
    if (!uss_param_get(id, have, &st) || st != USS_PRM_ST_OK) {
        ESP_LOGW(TAG, "USS preset: cannot read %s (status %u)", name, st);
        return false;
    }
    return true;
}

static bool preset_set(uint8_t id, const char *name, int32_t want)
{
    int32_t have = 0;
    uint8_t st = 0xFF;
    esp_task_wdt_reset();
    if (!uss_param_set(id, want, &have, &st) || st != USS_PRM_ST_OK || have != want) {
        ESP_LOGE(TAG, "USS preset: %s -> %ld refused (status %u, in effect %ld)",
                 name, (long) want, st, (long) have);
        return false;
    }
    ESP_LOGW(TAG, "USS preset: %s set to %ld", name, (long) want);
    return true;
}
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

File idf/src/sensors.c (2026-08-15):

#include "sensors.h"
#include "i2c_bus.h"

#include <string.h>
#include "freertos/FreeRTOS.h"
#include "freertos/task.h"

#define XFER_MS 100

/* ---- shared small helpers ---- */

static bool dev_rd(i2c_master_dev_handle_t d, uint8_t reg, uint8_t *buf, size_t n)
{
    if (!d) return false;
    return i2c_master_transmit_receive(d, &reg, 1, buf, n, XFER_MS) == ESP_OK;
}

static bool dev_wr(i2c_master_dev_handle_t d, uint8_t reg, uint8_t v)
{
    if (!d) return false;
    uint8_t tx[2] = { reg, v };
    return i2c_master_transmit(d, tx, 2, XFER_MS) == ESP_OK;
}

/* ===================== LTR-303 (0x29) ===================== */

static i2c_master_dev_handle_t s_ltr;

bool ltr303_sample(uint16_t *ch0, uint16_t *ch1)
{
    *ch0 = *ch1 = 0;
    if (!s_ltr) eco_i2c_add_tracked(&s_ltr, 0x29);

    uint8_t pid = 0;
    if (!dev_rd(s_ltr, 0x86, &pid, 1) || (pid & 0xF0) != 0xA0) return false;

    dev_wr(s_ltr, 0x80, 0x01);              /* ALS_CONTR: active */
    vTaskDelay(pdMS_TO_TICKS(150));         /* one integration (~100 ms default) */

    /* CH1 low byte read latches the pair; burst from 0x88 covers both. */
    uint8_t d[4];
    bool ok = dev_rd(s_ltr, 0x88, d, 4);
    if (ok) {
        *ch1 = ((uint16_t)d[1] << 8) | d[0];
        *ch0 = ((uint16_t)d[3] << 8) | d[2];
    }
    dev_wr(s_ltr, 0x80, 0x00);              /* standby */
    return ok;
}

/* ===================== SC7A20 (0x18 / 0x19) ===================== */

static i2c_master_dev_handle_t s_acc;
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

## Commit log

2026-07-24 missed stuff
    [BOM-Communication_pcb_main.csv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]
2026-08-07 more bord debug
    [partitions.csv]
2026-08-07 included button and pressure sensor tests
2026-08-11 changed to esp-idf
    [partitions.csv]
2026-08-13 pre-USS merge
    [tb_export_PCB-test-rig_20260813_1229.csv]
2026-08-15 added USS i2c
2026-08-15 Sensor rail power-cycle with bus hold-low, and USS auto-recovery
    Cutting the SENSOR rail does not power the ultrasonic board down while the
    I2C bus idles high: current flows 3V3 -> pull-up -> SDA -> the slave's ESD
    clamp -> its VCC, parking it a diode drop below the bus. Too low to run, too
    high to trigger a power-on reset. Measured on the bench 2026-08-15; it cost
    most of two sessions there. Without handling it, the GPIO14 gate cannot
    actually reset the slave and the node has no remote recovery.
    * i2c_bus: eco_i2c_hold_low() / eco_i2c_release(). hold_low removes every
    device, deletes the bus and drives SDA+SCL low; release restores the pins
    and rebuilds. Drivers now attach via eco_i2c_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
    [board.c, board.h, bq25792.c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]
2026-08-15 Comm module reads the ultrasonic link end to end
    Verified on hardware 2026-08-15:
    USS ok: code=122 dtof=1952 ps tof=131.2/131.2 us amp=1500/1532
    snr=30.5 dB gain=25
    wf280a: found at 0x38
    BQ 4197 mV / 99 %, accelerometer reading gravity, records uploaded
    Three real bugs found by putting it on the actual board:
    * The SENSOR rail was never switched on. board_init() drove GPIO14 low and
    nothing ever raised it, so anything on that header sat unpowered. Worse, an
    unpowered board CLAMPS the shared bus: its ESD diodes hold SDA/SCL near
    0.6 V and its own 4k7 pull-ups become pull-downs to a dead rail. The BQ25792
    on our always-on rail was unreachable and every record came bac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
    [board.c, board.h, main.c]
2026-08-15 Bus scan + decoded sensor_ok; rail stays on; real barometer for p_abs
    All six devices confirmed answering on hardware 2026-08-15:
    sensor_ok=0x3F BQ:y LTR303:y SC7A20:y MS5837:y USS:y WF280A:y
    lux0=544 acc=[48,8,1060] P=965.4mbar T=30.14C
    USS ok: code=122 tof 130.7/131.2 us amp 1533/1528 snr 32.5 dB
    The LTR-303 and accelerometer were never faulty -- they were victims of the
    clamped bus. Their zeros and the USS NACK had the same single cause.
    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
2026-08-15 Pressure: the MS5837 is the GAS sensor, not ambient
    Correcting my own mislabelling. The MS5837 on the I2C hat header sits in the
    gas line, so press_dmbar is GAS pressure. I had just published it as
    p_abs_hpa/atmospheric, which would have quietly corrupted any density or
    composition work downstream -- it reads ~965 hPa right now only because the
    line is open to air.
    p_gas_hpa <- MS5837 (sensor_ok bit 3)
    p_atm_hpa <- P_ATM_CONST_HPA, per-site constant, p_atm_is_const=1
    dp_hpa <- gas - atmospheric, for convenience; both inputs are sent
    raw so it can be recomputed off-device
    Atmospheric still has no sensor on this node, so the constant stays and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
    [config.h, uplink.c]
2026-08-15 Drive the module in autonomous mode; tof/dtof in us; pre-sleep recap
    * uss_start_auto(): puts the module into 1 Hz autonomous totalizing. Only
    issued when STATUS.AUTO is clear, because AUTO_START zeroes the accumulator
    and re-issuing it every wake would discard the volume it exists to collect.
    Re-asserting on a clear bit still recovers automatically after the module
    reboots, and it is retried after a power-cycle recovery too.
    * It WAITS for STATUS.AUTO before returning. The write only queues the command;
    the module then raises its AFE rails, settles and runs a discard capture --
    ~700 ms. Returning early let uss_sample() read STATUS inside that window, see
    AUTO clear and issue a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
    [board.c, config.h, main.c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]
2026-08-15 Fix telemetry: buffer overflow, stack fault, and oversized publishes
    Three bugs I introduced by adding fields without checking what they sat in.
    Symptom the user spotted: every sensor key on ThingsBoard frozen at one
    timestamp while "transport" kept updating -- the short status payload was
    getting through while every record payload was being rejected.
    1. record_values() wrote into char vals[800]. With the USS block, both ToFs
    and the pressure trio a record is ~1070 chars, so it truncated mid-field
    and produced malformed JSON, which took the whole batch down SILENTLY.
    Buffer is 1536 now and record_values() returns -1 on truncation so it can
    never fail quietly again.
    2. That 1536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
    [uplink.c]
2026-08-15 Trim telemetry to 22 useful keys; wait for the first autonomous result
    Telemetry went from ~40 datapoints per record to 22. Rule applied: publish what
    you would act on or analyse; drop what is derivable, what is only wanted for a
    post-mortem, and what is structurally constant. Nothing is lost -- the 128-byte
    flash record still carries every field.
    Dropped: bat_mw (= vbat*ibat), vac2/vsys/vreg/vindpm (charger internals),
    fault0/1 (almost always 0), weather_good + eco_chg (derived heuristics),
    light_ch1 (IR), tdie_c + ts_pct + ts_stat (charger thermals), flow_lpm (the VFR
    constants are wrong for this cell, so it is actively misleading), uss_amp_*,
    uss_gain and uss_status (summarised by uss_sn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
    [uplink.c, uss.c]
2026-08-15 docs: record the working ultrasonic link, errata and test status
    COMMUNICATION_MODULE section 7 rewritten: no longer claims 'not yet run against
    hardware'. Documents how the module is driven (autonomous, master-side rules),
    why the sensor rail is always-on, and the 22 telemetry keys.
    hardware-errata gains 9-12: no bleed resistor on the switched rail; an unpowered
    device clamps the whole shared bus; cutting VCC does not power a device down
    while the bus idles high; and the telemetry datapoint/buffer/stack constraints.
    testing-status records what is proven (link, autonomous mode, watchdog, upload)
    and what is explicitly NOT calibrated (flow constants, gas pressure plumbing,
    atmospheric constan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
2026-08-26 small time accounting fix
    [main.c, uplink.c]
2026-09-04 power optimizing
    [tb_export_PCB-test-rig_20260902_1831.csv]
2026-09-07 more power optimizing with joulescope.
    [tb_export_PCB-test-rig_20260905_1100.csv, tb_export_PCB-test-rig_20260905_1126.csv, tb_export_PCB-test-rig_20260906_1107.csv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]
2026-09-08 moooooore power optimization
2026-09-11 there is an issue where every 5 hours there is a bad reading... i could not identify the cause, it wasnt always there.... we not a pply a filter... it only costs us about 0.05% of all readings so it 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
    [tb_export_PCB-test-rig_20260909_1955.csv, tb_export_PCB-test-rig_20260911_0831.csv]
2026-09-13 this is maybe a bad commit we are trying to figure out why stuff reboots...
    [tb_export_PCB-test-rig_20260911_1544.csv, tb_export_PCB-test-rig_20260912_1105.csv, tb_export_PCB-test-rig_20260913_1200.csv]
2026-09-14 found error new soak
    [tb_export_PCB-test-rig_20260913_1710.csv, tb_export_PCB-test-rig_20260913_1947.csv, tb_export_PCB-test-rig_20260913_2144.csv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]
2026-09-23 lots of power soak and server stuff
    [eco-field-02_1d(1).csv, eco-field-02_1d(2).csv, eco-field-02_1d(3).csv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]
2026-09-25 low-power soak and propper USS control
    [eco-field-02_1d(4).csv]
2026-09-25 server board communication
2026-09-30 implemented downlink stage one, chaning config remotely
